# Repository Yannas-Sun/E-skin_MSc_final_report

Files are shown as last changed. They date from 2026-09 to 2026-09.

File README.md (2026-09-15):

# E-SKIN MSc final report companion

This repository is the evidence package for a modular electronic-skin prototype and its final MSc report. It collects the report-linked experimental records, derived analyses, hardware design evidence and selected figures needed to assess the reported communication, power and calibration results.

## Contents

- [Final report PDF](main_final.pdf)
- [Project background](#project-background)
- [System and data path](#system-and-data-path)
- [Hardware overview](#hardware-overview)
- [Core reported results](#core-reported-results)
- [Repository structure](#repository-structure)
- [Software simulation](#software-simulation)
- [Evidence and reproduction](#evidence-and-reproduction)
- [Scope limits](#scope-limits)

## Project background

The final report treats the E-SKIN prototype as a system-level scalability problem. It starts from an existing modular FSR platform and evaluates whether adding sensing modules remains practical across the complete chain: local acquisition, shared communication, host transport, power delivery and calibration.

### Research gap

Existing e-skin work often foregrounds sensing materials, array geometry or local sensor performance. The report identifies a system-level gap: the available modular prototype had not been evaluated as one connected scaling problem across data traffic, regulated power and calibration repeatability. In particular, the report needed evidence for:

- whether complete FSR data can be transported as modules are added, and whether cached change-driven DELTA frames reduce the same-rate traffic;
- whether the parallel 3.3 V supply maintains the specified voltage range as module count increases, without confusing static readings with a verified transient capacity; and
- whether a layer-wide calibration workflow reduces cell-to-cell variation and reconstructs applied whole-layer mass for separately calibrated FSR layers.

The report separates measured behaviour for N = 1–4 modules from conditional model projections beyond the measured range. The repository follows the same boundary.

### Hypotheses to be tested

The report defines the following hypotheses in its Background chapter. They are listed here as the claims the evidence package is intended to test or bound.

- **D-H1 — protocol-model agreement:** within N = 1–4, observed mean FULL packet lengths and DELTA packet lengths follow the byte budgets using the recorded mask activity, complete-frame incidence and module-update coverage. Values beyond four modules remain conditional extrapolations.
- **D-H2 — DELTA traffic reduction:** change-driven DELTA reduces same-rate packet bytes under the tested activity conditions in windows without detected sequence, cache-chain or target-update anomalies.
- **P-H1 — current prediction:** separately measured single-module currents provide a useful descriptive prediction of the tested multi-module combinations under comparable operating conditions; this is not treated as proof of a universal current-versus-count law.
- **P-H2 — voltage range:** recorded module voltages remain within the project-defined 3.3 V ± 5% band for the tested configurations. Transient delivery and fault-free operation require additional monitoring.
- **C-H1 — spatial dispersion:** with matched RAW inputs and common valid cells, per-cell multi-load fitting reduces spatial dispersion relative to two-point LINEAR or GAMMA calibration, assessed separately using CV, variance, IQR and MAD.
- **C-H2 — mass reconstruction:** per-cell calibration estimates known applied whole-layer mass, quantified with signed bias, absolute error, per-cell MAE/RMSE and non-zero-load percentage error. The report specifies no pass/fail accuracy threshold, so this remains a descriptive error assessment.
- **C-H3 — second-layer repeatability:** applying the same workflow independently to a second nominally identical FSR layer retains the FIT PRESS benefit relative to LINEAR and GAMMA under the same validation procedure. This tests independent retraining across layers, not direct transfer of one fitted model.

The reported results below show which parts are supported by the measured records and which remain model-based or unmeasured.

## System and data path

The report's layered acquisition and communication path is reproduced here for orientation.

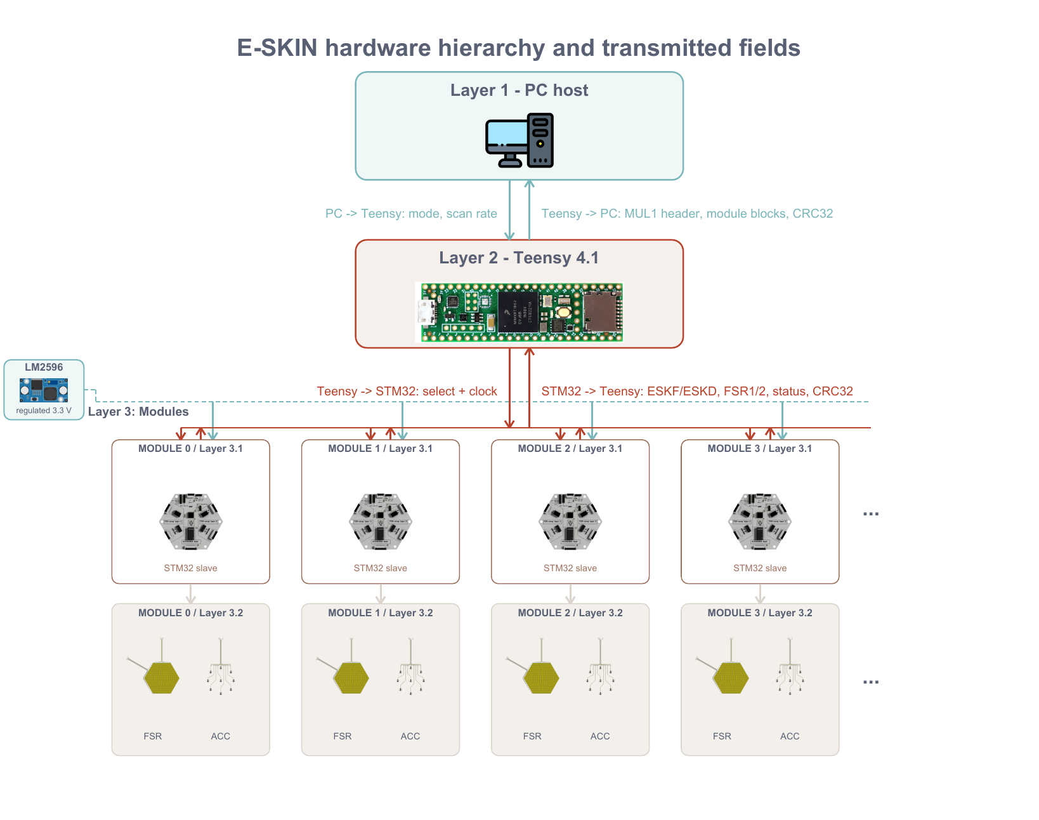
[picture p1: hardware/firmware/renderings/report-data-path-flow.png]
Layered acquisition and communication path from the report


[Open the original report flow figure](<Imperial College Individual Project Template_LaTeX/figures/data/data_path_flow.pdf>).

## Hardware overview

The sensing layer places pressure-sensitive resistive foam between opposing copper electrode layers. Orthogonal row and column electrodes form a 16 × 16 matrix; pressure changes the local resistance at each row-column intersection. The STM32 scans the matrix, buffers a complete ESKF or change-driven ESKD frame, and sends it to the Teensy bridge. The mainboard uses an external regulated 3.3 V branch for the module electronics.

The ACC board shown below is an existing prototype interface. It is retained as hardware evidence but is outside the reported FSR performance evaluation.

<table width="100%">
<tr>
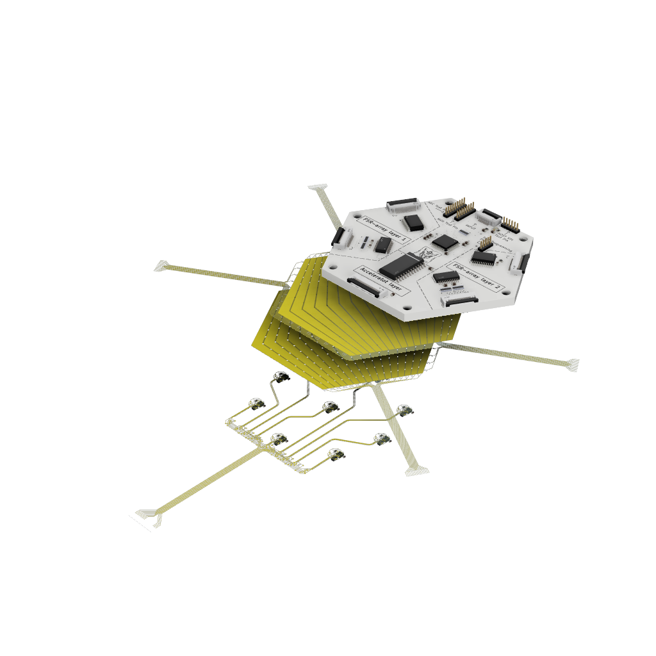
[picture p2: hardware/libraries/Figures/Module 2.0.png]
Module rendering
<td width="50%" align="center"><br>Module stack</td>
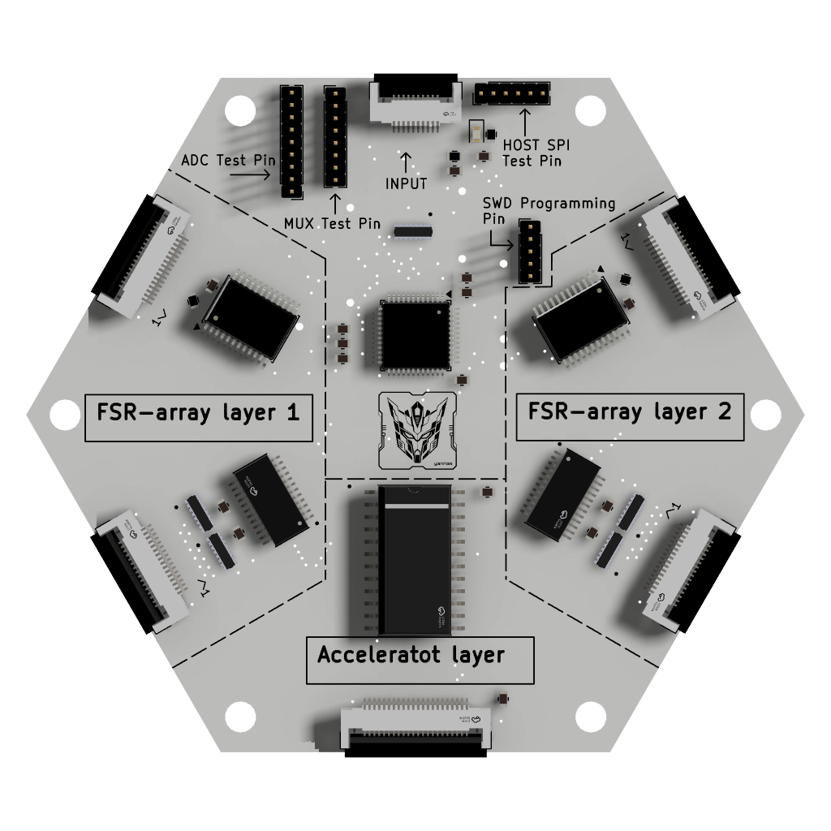
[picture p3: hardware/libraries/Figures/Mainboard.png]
Mainboard rendering
<td width="50%" align="center"><br>Rigid mainboard</td>
</tr>
<tr>
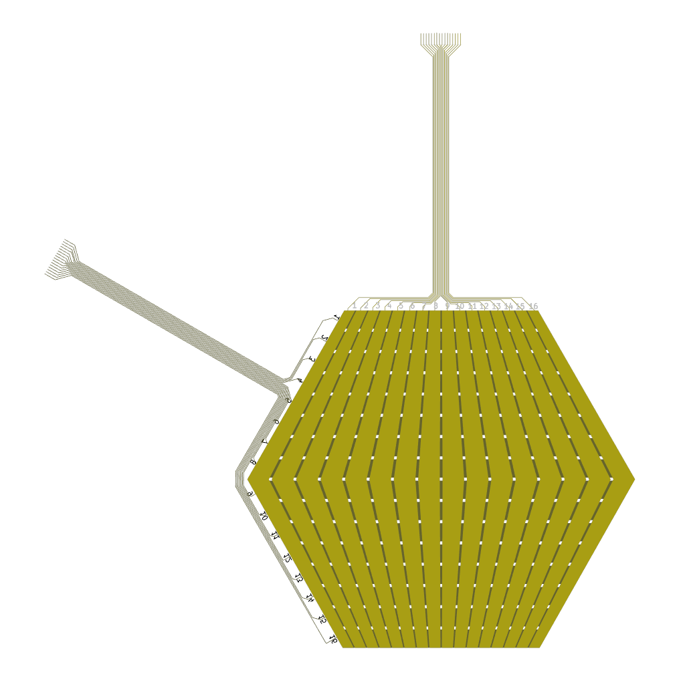
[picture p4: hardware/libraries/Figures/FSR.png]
FSR layer rendering
<td width="50%" align="center"><br>Flexible FSR layer</td>
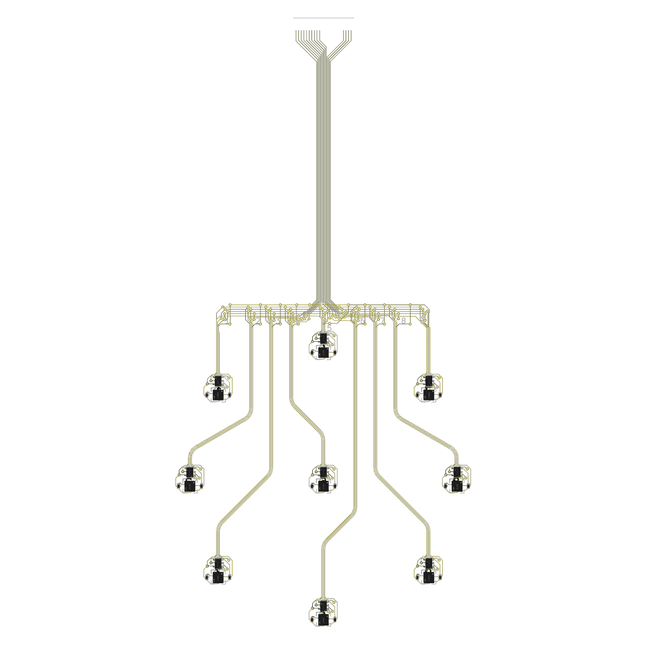
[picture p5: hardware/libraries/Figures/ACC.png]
ACC prototype rendering
<td width="50%" align="center"><br>ACC prototype</td>
</tr>
</table>

- [Hardware overview](hardware/README.md)
- [Prototype design records](hardware/prototype/README.md)
- [Shared KiCad libraries and renderings](hardware/libraries/README.md)
- [Active and archived firmware](hardware/firmware/README.md)

## Core reported results

### Communication

- The four-module FULL stream measured 6.747828 ± 0.001148 Mbit/s at the configured 200 Hz scan rate.
- Measured FULL packet lengths matched the protocol model for N = 1–4. Mean USB rates differed from the nominal 200 Hz predictions by +0.029% to +0.125%.
- Extending the FULL model to N = 100 gives 167.7184 Mbit/s; this value is unvalidated because only four modules were measured.
- DELTA reduced same-rate packet bytes by 86.60%–88.73% in zero-load windows and by 65.10%–80.57% in five audited dynamic batches.
- The fitted zero-load ordinary-mask trend is K0(N) = 7.554189 + 0.582684N. The rolling stress projection uses K = 254.
- At 200 Hz, the modelled crossing counts are conditional planning values:

<table width="100%">
<tr>
<th align="left">Traffic model</th>
<th align="right">USB 480 Mbit/s</th>
<th align="right">HOST SPI 10 Mbit/s</th>
</tr>
<tr>
<td>FULL</td>
<td align="right">286 modules</td>
<td align="right">5 modules</td>
</tr>
<tr>
<td>DELTA, zero-load K0(N)</td>
<td align="right">464 modules</td>
<td align="right">41 modules</td>
</tr>
<tr>
<td>DELTA, rolling K = 254</td>
<td align="right">501 modules</td>
<td align="right">10 modules</td>
</tr>
</table>

Only N = 1–4 is experimentally measured. The crossing counts are extrapolations from the reported packet models and interface rates.

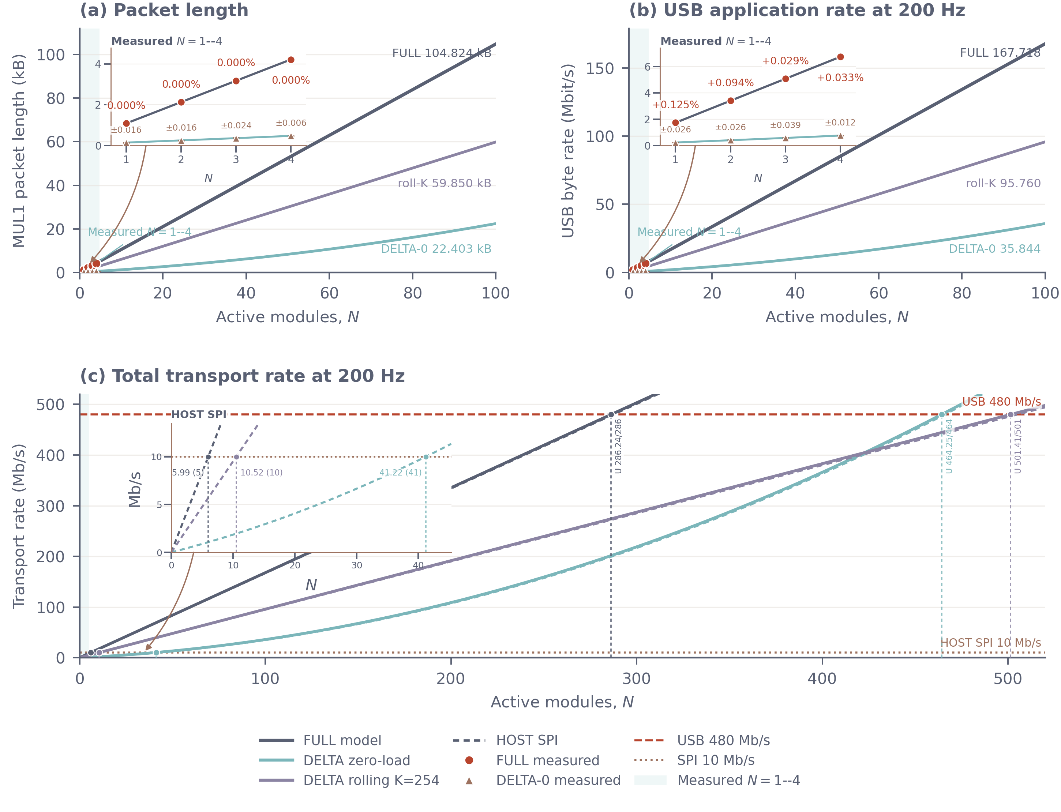
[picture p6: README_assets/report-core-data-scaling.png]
Report figure: transport-model validation and capacity projection


[Report source: transport-model validation and capacity projection](<Imperial College Individual Project Template_LaTeX/figures/data/v2_11/full_model_validation.pdf>) · [Communication data and analyses](<data scalability/README.md>)

### Power

The power experiment records static voltage, branch current and temperature readings for all 15 non-empty combinations of M0–M3 under the configured 200 Hz FULL acquisition. The four-module branch-current readings were 72.513 mA and 78.720 mA in the reported branches, and the lowest accepted module minimum was 3.236 V. These static readings do not establish transient supply capacity.

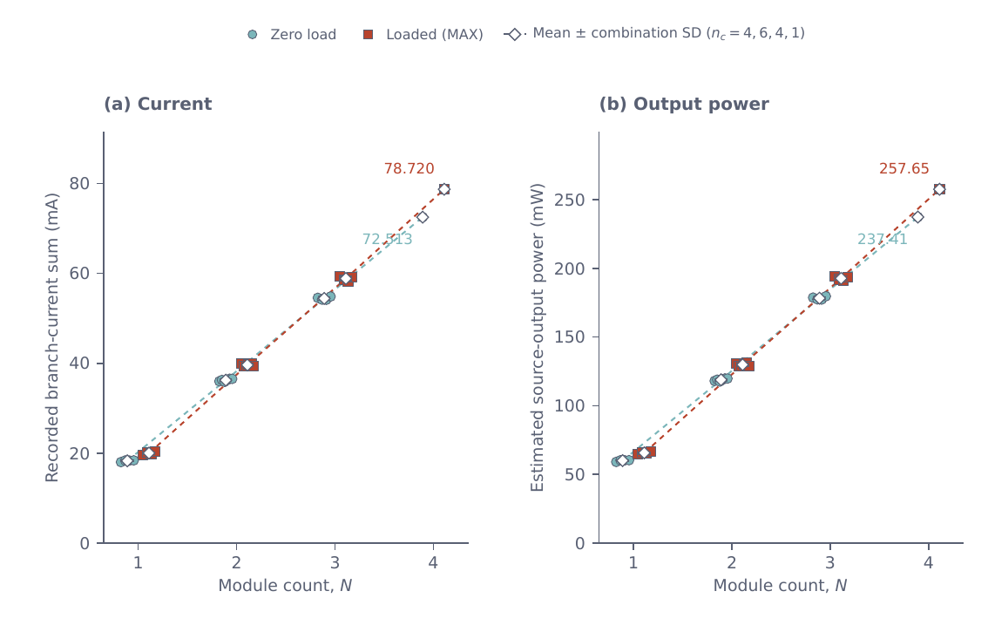
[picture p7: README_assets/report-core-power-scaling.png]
Report figure: continuous-read electrical demand


[Report source: continuous-read electrical demand](<Imperial College Individual Project Template_LaTeX/figures/power/v2_9/current_power_scaling.pdf>) · [Power data and analyses](<power scalability/README.md>)

### Calibration

FSR1 and FSR2 were calibrated in separate 22-point sweeps from 0 to 5000 g. In the FSR2 evaluation, FIT PRESS produced a 10.22% mean layer-estimate APE and 171.69 g mean per-cell MAE across 21 validation captures, with a 40.12 g zero-load estimate. The report treats these metrics as comparator- and metric-dependent.

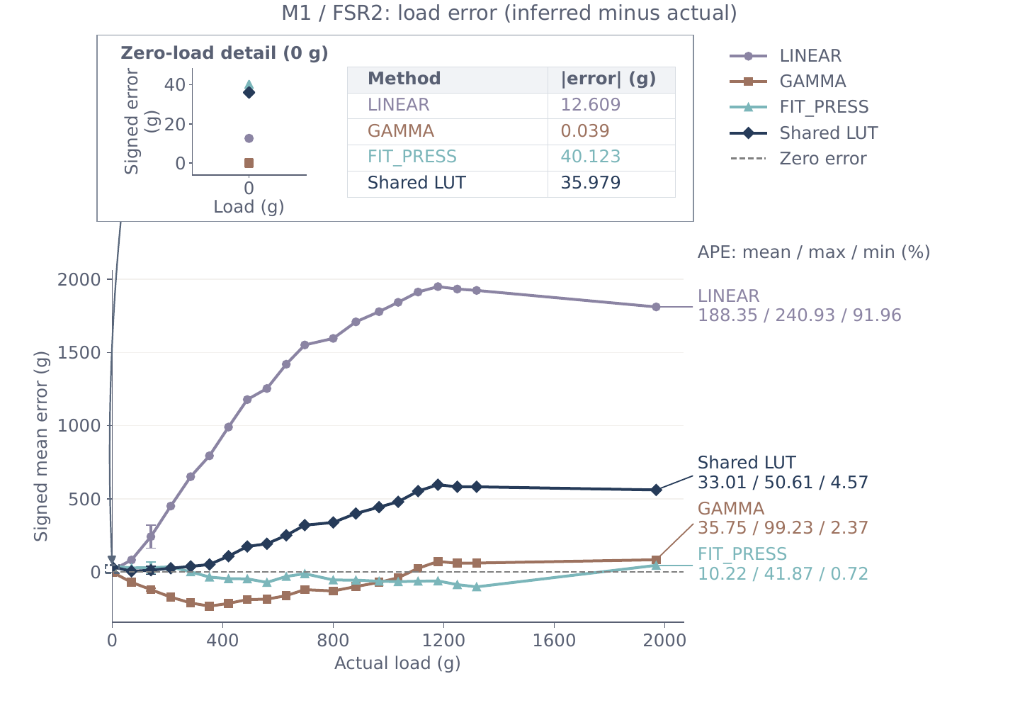
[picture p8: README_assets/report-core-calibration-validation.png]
Report figure: FSR2 load reconstruction error


[Report source: FSR2 load reconstruction error](<Imperial College Individual Project Template_LaTeX/figures/calibration/v2_7/fsr2_load_error_vs_load.pdf>) · [Calibration data and analyses](<Calibration scalability/README.md>)

## Repository structure

| Path | Purpose |
|---|---|
| [Calibration scalability](<Calibration scalability>) | FSR1/FSR2 training sweeps, validation captures, calibration models, figures and audits. |
| [data scalability](<data scalability>) | Canonical FULL/DELTA recordings, selected windows, communication models and figures. |
| [power scalability](<power scalability>) | Canonical electrical records, matched photographs, power analyses and figures. |
| [hardware](hardware/README.md) | Prototype design files, manufacturing exports, shared libraries, renderings and firmware. |
| [LaTeX supplementary package](<Imperial College Individual Project Template_LaTeX/figures>) | Report-linked figures and [audit evidence](<Imperial College Individual Project Template_LaTeX/audit>). |
| [README assets](README_assets) | Rendered copies of the core report result figures used by this README; the data-path rendering is stored with firmware. |
| [figure_style.py](figure_style.py) | Shared plotting-style helper retained with the evidence package. |

The complete report source and build outputs are intentionally ignored by Git. The final rendered report is available at [main_final.pdf](main_final.pdf); this repository publishes the supporting records and selected supplementary material rather than a standalone report compiler.

## Evidence and reproduction

Raw records are retained as recorded in the three scalability packages. Derived tables and figures identify their input manifests and analysis directories. Scripts use portable relative paths within the organized packages; machine-specific build products, caches, live captures and temporary review files are ignored.

The audit material records provenance and validation checks for report-linked data. It does not introduce additional experiments or replace the report's stated methods.

## Scope limits

- Communication measurements stop at four modules; larger module counts are conditional projections.
- Power results are static readings and do not establish transient supply capacity.
- Cross-module calibration, calibration transfer between layers and repeatability after reassembly were not measured.
- The ACC prototype is documented as hardware evidence but is outside the reported FSR evaluation.

## Software simulation

The early software simulator is maintained in the separate [e-skin-simulator repository](https://github.com/Yannas-Sun/e-skin-simulator). It explores module geometry, FSR and accelerometer readout, protocol traffic and visualisation before all hardware paths are complete.

The simulator is an initial design and communication tool. It is not evidence for the measured report results and is not a high-fidelity electrical, mechanical or finite-element model. Scan strategies, MCU-in-the-loop behaviour, event-driven sensing, multi-patch communication and physical validation still require further development.

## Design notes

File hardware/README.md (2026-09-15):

# Hardware package

This directory contains the hardware evidence for the final project: prototype design records, manufacturing exports, shared KiCad libraries, renderings and firmware.

## System principle

Each replaceable module contains two flexible FSR electrode layers and a local STM32G474CETx. Orthogonal copper rows and columns surround a pressure-sensitive resistive foam layer, producing a 16 x 16 sensing matrix. The rigid mainboard provides the FSR interfaces, ADC and multiplexing paths, branch power, connectors and programming access.

The Teensy 4.1 acts as the host bridge. It selects modules over the shared 10 MHz HOST SPI link, aggregates ESKF FULL or ESKD DELTA frames into MUL1 v2 packets and forwards them to the PC over USB. The ACC interface is retained as an existing prototype record and is outside the reported FSR evaluation.

## Renderings

<table>
<tr>
<td>Module stack<br>Module stack</td>
<td>Rigid mainboard<br>Rigid mainboard</td>
</tr>
<tr>
<td>Flexible FSR layer<br>Flexible FSR layer</td>
<td>ACC prototype<br>ACC prototype</td>
</tr>
</table>

## Navigation

- [Prototype design records](prototype/README.md): mainboard, flexible FSR array and ACC prototype design/manufacturing files.
- [Shared libraries](libraries/README.md): KiCad symbols and footprints, models, datasheets, BOMs and exported figures.
- [Firmware](firmware/README.md): active four-module firmware, protocol notes and archived firmware records.

Each prototype directory separates design files from manufacturing outputs. KiCad projects use paths relative to this hardware package.

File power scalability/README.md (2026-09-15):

# Power scalability

Evidence package for the report's module current, voltage, temperature and power analysis.

## Report links

- `Imperial College Individual Project Template_LaTeX/method/power.tex`
- `Imperial College Individual Project Template_LaTeX/result/power.tex`
- `Imperial College Individual Project Template_LaTeX/discussion/power_outline.tex`
- `Imperial College Individual Project Template_LaTeX/appendix/power.tex`
- Current figures: `Imperial College Individual Project Template_LaTeX/figures/power/`

## Contents

- `DATA/raw/canonical/`: source YAML, photographs, retests and `power_raw.csv`.
- `DATA/raw/intake/`: voltage-intake supplements.
- `DATA/analysis/current/`: current reviews, tables and figure exports.
- `DATA/analysis/retest_reviews/`: pointwise retest provenance.
- `DATA/analysis/provenance/`: path and hash manifests.
- `DATA/reference/`: frozen earlier inputs retained by current manifests.
- `DATA/archive/`: superseded previews.
- `script/Main/`: analysis utilities and pipeline entry points.

The report uses all 15 non-empty module combinations under configured 200 Hz `FULL` acquisition. Electrical readings are static descriptive measurements; they do not establish transient supply capacity or thermal equilibrium.

The neighbouring LaTeX source is excluded by its `.gitignore`.

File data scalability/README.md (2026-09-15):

# Data scalability

Evidence package for the report's FULL and DELTA communication experiments.

## Report links

- `Imperial College Individual Project Template_LaTeX/method/data_scalability.tex`
- `Imperial College Individual Project Template_LaTeX/result/data_scalability.tex`
- `Imperial College Individual Project Template_LaTeX/discussion/data_scalability.tex`
- `Imperial College Individual Project Template_LaTeX/appendix/data_scalability.tex`
- Current figures: `Imperial College Individual Project Template_LaTeX/figures/data/`

## Current selection

The indexed campaign contains 114 recordings: 48 FULL zero-load, 45 DELTA zero-load and 21 DELTA dynamic records. The report selection contains 45 FULL windows, 45 DELTA zero-load windows and 15 DELTA dynamic windows.

## Contents

- `data/`: canonical recordings and per-condition records.
- `analysis/`: current selection, audits and derived statistics.
- `history/`: superseded or diagnostic campaigns retained for provenance.
- `figures/`: figure exports; only report-linked files are release material.
- `script/`: indexing and audit utilities.

Key indexes are `data/run_index.csv`, `data/primary_matrix.csv`, `data/dynamic_analysis_selected.csv` and `data/analysis_selected.csv`. Values and source files are unchanged by this organisation.

The neighbouring LaTeX source is excluded by its `.gitignore`.

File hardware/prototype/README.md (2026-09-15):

# Prototype design records

This directory contains the current KiCad design and manufacturing records for the evaluated mainboard and flexible FSR layers, plus the ACC prototype interface.

## Hardware principles

- The [mainboard](mainboard/README.md) is a four-layer rigid FR4 controller board with local STM32G474CETx acquisition, FSR readout, branch power distribution, connectors and programming access.
- The [flexible FSR array](fsr_array/README.md) is a passive two-layer electrode carrier. Orthogonal row and column electrodes surround a pressure-sensitive resistive foam layer to form a 16 x 16 matrix.
- The [ACC prototype](acc_prototype/README.md) is an existing accelerometer interface retained as hardware evidence; it is outside the reported FSR evaluation.

Each board directory separates design files from manufacturing exports. The renderings below are orientation images; the KiCad projects and Gerbers are the source records.

## Renderings

<table>
<tr>
<td>Module stack<br>Module stack</td>
<td>Rigid mainboard<br>Rigid mainboard</td>
</tr>
<tr>
<td>Flexible FSR layer<br>Flexible FSR layer</td>
<td>ACC prototype<br>ACC prototype</td>
</tr>
</table>

## Contents

- [mainboard/](mainboard/README.md): rigid controller schematic, PCB layout, BOM and manufacturing files.
- [fsr_array/](fsr_array/README.md): flexible FSR schematic, PCB layout and manufacturing files.
- [acc_prototype/](acc_prototype/README.md): ACC prototype schematic, PCB layout, BOM and manufacturing files.
- renderings/: small reference images used by this README.

Open each KiCad project from its design directory with the shared libraries available under hardware/libraries/.

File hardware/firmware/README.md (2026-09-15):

# Firmware

This directory contains the active STM32 and Teensy firmware used by the final four-module prototype, plus archived firmware records.

## Principle

Each STM32G474CETx scans its local 16 x 16 FSR matrix and sends a complete ESKF frame or a change-driven ESKD frame over the shared 10 MHz HOST SPI link. The Teensy 4.1 selects modules, aggregates the returned frames into a MUL1 v2 packet and forwards the packet to the PC over USB. The ACC interface is a prototype record and is outside the reported FSR evaluation.

Layered acquisition and communication path from the report

## Contents

- active/: firmware used for the final report.
- active/four-module-variable-spi/: STM32 module firmware, Teensy bridge, commands, protocol notes and tests.
- archive/: superseded firmware and historical records.
- renderings/: the report data-path figure used for orientation.

## Active workflow

From active/four-module-variable-spi/:

1. Build the STM32 and Teensy targets with the supplied command scripts.
2. Flash each STM32 with its probe UID.
3. Upload the matching Teensy bridge image.
4. Start the serial monitor with the actual port name.

Required tools are CMake, Ninja, arm-none-eabi-gcc, arduino-cli, pyocd and Python on PATH. Do not commit generated build output or live measurement captures; the firmware ignore rules exclude them.

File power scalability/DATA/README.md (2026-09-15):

# Power data

Power evidence is separated by provenance and processing state.

| Directory | Role |
|---|---|
| `raw/canonical/` | Immutable source records, photographs, retests and `power_raw.csv`. |
| `raw/intake/` | Dated voltage supplements and intake notes. |
| `analysis/current/` | Current reviews, tables and report figure exports. |
| `analysis/retest_reviews/` | Pointwise retest analysis. |
| `analysis/provenance/` | Relocation and hash manifests. |
| `reference/` | Earlier analyses retained by current provenance. |
| `archive/` | Superseded preview material. |

Current report inputs are under `raw/canonical/` and `analysis/current/`. Do not edit raw records; regenerate derived outputs with scripts in `../script/Main/`.

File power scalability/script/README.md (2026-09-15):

# Power scripts

Scripts use project-relative paths and discover the project root from their own location.

- Main/pipeline/: current voltage, ZERO/MAX and retest compilation.
- Main/figures/: report figure generators and plotting style.
- Main/intake/: dated photograph transcription and supplements.
- Main/tests/: provenance and coverage checks.
- Main/legacy/: historical Power 2.1 reproduction.

Run from the power scalability directory. See Main/README.md for the current entry points.

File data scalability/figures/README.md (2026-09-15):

# Data figures

This directory contains source exports and diagnostics for the data-scalability figures.

Report-linked figures:
- figures/data/v2_11/full_model_validation.pdf
- figures/data/v2_9/data_length_traces.pdf

Other exports are intermediate theory panels, protocol diagrams and diagnostic views. They are retained only when needed to trace a report figure. USB theory uses the 480 Mbit/s reference; HOST SPI uses the 10 MHz reference. Measurements stop at N=4; extensions are conditional projections.

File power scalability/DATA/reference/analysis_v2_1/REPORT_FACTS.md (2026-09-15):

# Power report 2.1: reproducible recorded-data facts

18 continuous USB-read YAML records (9 ZERO, 9 MAX), FULL at 200 Hz; 13 separate legacy blocked-standby CSV records. Standby YAML duplicates are excluded.

Every exact continuous condition has R1 only. N=1: four labelled modules; N=2: two combinations; N=3: two combinations; N=4: one combination. Different combinations are not repeat recordings.

## Continuous USB-read results

| Load | N | Combination | Current sum (mA) | Output power estimate (mW) | Lowest module representative (V) | Lowest module MIN field (V) |
|---|---:|---|---:|---:|---:|---:|
| MAX | 1 | M0 | 19.689 | 64.600 | 3.231 | 3.231 |
| MAX | 1 | M1 | 20.110 | 65.981 | 3.250 | 3.249 |
| MAX | 1 | M2 | 19.897 | 65.282 | 3.247 | 3.247 |
| MAX | 1 | M3 | 20.340 | 66.715 | 3.248 | 3.248 |
| MAX | 2 | M0+M1 | 39.968 | 131.015 | 3.241 | 3.241 |
| MAX | 2 | M2+M3 | 39.379 | 129.084 | 3.245 | 3.244 |
| MAX | 3 | M0+M1+M2 | 59.328 | 194.359 | 3.237 | 3.237 |
| MAX | 3 | M1+M2+M3 | 59.617 | 195.305 | 3.232 | 3.232 |
| MAX | 4 | M0+M1+M2+M3 | 78.720 | 257.651 | 3.237 | 3.236 |
| ZERO | 1 | M0 | 18.160 | 59.565 | 3.235 | 3.235 |
| ZERO | 1 | M1 | 18.380 | 60.305 | 3.255 | 3.255 |
| ZERO | 1 | M2 | 18.360 | 60.239 | 3.249 | 3.249 |
| ZERO | 1 | M3 | 18.400 | 60.352 | 3.251 | 3.250 |
| ZERO | 2 | M0+M1 | 36.016 | 118.168 | 3.234 | 3.234 |
| ZERO | 2 | M2+M3 | 36.534 | 119.795 | 3.248 | 3.248 |
| ZERO | 3 | M0+M1+M2 | 54.481 | 178.480 | 3.224 | 3.224 |
| ZERO | 3 | M1+M2+M3 | 54.851 | 179.692 | 3.245 | 3.245 |
| ZERO | 4 | M0+M1+M2+M3 | 72.513 | 237.408 | 3.240 | 3.240 |

## Independent N=1 prediction

Residual = 100 × (observed branch sum − sum of separately recorded N=1 currents) / predicted sum. MAX results require equivalent loading; module labels are assumed consistent across runs.

| Load | Combination | Predicted (mA) | Observed (mA) | Residual (%) |
|---|---|---:|---:|---:|
| MAX | M0+M1 | 39.799 | 39.968 | 0.4246 |
| ZERO | M0+M1 | 36.540 | 36.016 | -1.4340 |
| MAX | M2+M3 | 40.237 | 39.379 | -2.1324 |
| ZERO | M2+M3 | 36.760 | 36.534 | -0.6148 |
| MAX | M0+M1+M2 | 59.696 | 59.328 | -0.6165 |
| ZERO | M0+M1+M2 | 54.900 | 54.481 | -0.7632 |
| MAX | M1+M2+M3 | 60.347 | 59.617 | -1.2097 |
| ZERO | M1+M2+M3 | 55.140 | 54.851 | -0.5241 |
| MAX | M0+M1+M2+M3 | 80.036 | 78.720 | -1.6443 |
| ZERO | M0+M1+M2+M3 | 73.300 | 72.513 | -1.0737 |

## Matched load comparisons

| Combination | ZERO (mA) | MAX (mA) | Increase (mA) | Increase (%) |
|---|---:|---:|---:|---:|
| M0 | 18.160 | 19.689 | 1.529 | 8.4196 |
| M1 | 18.380 | 20.110 | 1.730 | 9.4124 |
| M2 | 18.360 | 19.897 | 1.537 | 8.3715 |
| M3 | 18.400 | 20.340 | 1.940 | 10.5435 |
| M0+M1 | 36.016 | 39.968 | 3.952 | 10.9729 |
| M2+M3 | 36.534 | 39.379 | 2.845 | 7.7873 |
| M0+M1+M2 | 54.481 | 59.328 | 4.847 | 8.8967 |
| M1+M2+M3 | 54.851 | 59.617 | 4.766 | 8.6890 |
| M0+M1+M2+M3 | 72.513 | 78.720 | 6.207 | 8.5598 |

## Limits on interpretation

- Every exact continuous-state/mode/frequency/load/module-combination condition has one recording (R1); repeat SD is unavailable. Different modules/combinations are not repeats.
- Fields named avg are treated as recorded representative instrument readings, not verified time averages. DMM MIN/MAX are not repeat SD or verified high-speed transient extrema.
- Currents were measured sequentially by branch; their sum is a module-supply demand estimate, not a simultaneously measured total-current waveform or peak.
- Teensy USB power is excluded. V_source times the branch-current sum estimates module-supply output power, not converter input power, efficiency or whole-system power.
- MAX records state 2000 g but omit area and application: per-module versus whole-system mass, position and layer are unresolved. Loaded prediction comparisons are conditional on equivalent module loading.
- Continuous YAML dates, start times and operator are absent; nominal 30 s warm-up and 10 s measurement fields are prefilled and not independently confirmed.
- Fault counters are template-default zero without confirmed observation; they do not establish fault-free operation.
- M0..M3 identify modules as written in experiment records; consistent physical identity across combinations has not been independently verified by hardware UID.
- Temperature readings do not establish thermal equilibrium. Startup, fast transients, full supply-board capacity, maximum module count and 20% headroom are unverified.
- Blocked and continuous results come from separate records, not a randomized paired intervention; state differences are descriptive, not an isolated causal estimate.

5 continuous current representative readings fall outside their recorded MIN/MAX range by at most 0.005 mA. Original readings are retained.

- PS01_N2_F200_ZERO_M0-M1_USB_RX_R1 / M1: Representative=18.055 mA; MIN=18.06; MAX=18.31; outside by 0.005000 mA. Check instrument display/rounding; do not replace values.
- PS01_N3_F200_ZERO_M0-M1-M2_USB_RX_R1 / M0: Representative=17.968 mA; MIN=17.97; MAX=17.99; outside by 0.002000 mA. Check instrument display/rounding; do not replace values.
- PS01_N3_F200_ZERO_M0-M1-M2_USB_RX_R1 / M2: Representative=18.383 mA; MIN=18.35; MAX=18.38; outside by 0.003000 mA. Check instrument display/rounding; do not replace values.
- PS01_N3_F200_ZERO_M1-M2-M3_USB_RX_R1 / M3: Representative=18.383 mA; MIN=18.35; MAX=18.38; outside by 0.003000 mA. Check instrument display/rounding; do not replace values.
- PS01_N4_F200_ZERO_M0-M1-M2-M3_USB_RX_R1 / M1: Representative=18.302 mA; MIN=18.27; MAX=18.3; outside by 0.002000 mA. Check instrument display/rounding; do not replace values.

Lowest continuous module MIN field: 3.224 V, PS01_N3_F200_ZERO_M0-M1-M2_USB_RX_R1, M0; margin above 3.135 V: 89.0 mV. This is a recorded DMM value, not a high-speed transient guarantee.

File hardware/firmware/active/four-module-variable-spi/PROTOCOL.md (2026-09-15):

# Host SPI 变长传输与 USB 契约

## 1. 连接和事务

- Teensy 4.1 为 SPI master；每个 STM32 为 SPI3 slave。
- 10 MHz，mode 0，8-bit，MSB first。多字节字段使用 little-endian。
- 模块 0..3 的 Teensy CS：10、14、15、16；IRQ：2、3、4、5。
- STM32 将一帧编码到最大容量 1044 B 的缓冲区，保存其实际长度 L；按 L 启动
  一次 Tx/Rx DMA，再拉高 IRQ。两个缓冲区各自保存长度，重编码时同步更新长度。
- Teensy 等待 IRQ，拉低该模块 CS，先读 16 B ESK 头，同时在 MOSI 发出 16 B DSCM
  命令。验证头后，保持 CS 为低，继续读 L−16 B。STM32 DMA 在两次调用之间不重启。
- 完整帧总时钟数为 8L；16 B 帧头本来就在 L 中，不是额外开销。剩余 MOSI 字节为零。
- Teensy 读完后拉高 CS，验证掩码数量和 CRC，并按原规则放入 USB 队列。
  STM32 在 DMA 完成后处理收到的命令。模式改变或请求完整同步时重编码下一缓冲区。

```text
IRQ   ____/-----------------------------------\____
CS    ______\________________________________/_____
SCK          [16 B header]  [L - 16 B remainder]
MISO         [ESK header ]  [masks/values/CRC  ]
MOSI         [DSCM command] [zero filler       ]
```

示意图只表示事务关系；IRQ 下降由 DMA 完成回调触发，不要求和 CS 上升同一时刻。
STM32 可并行采集下一帧，但不会覆盖正在传输的缓冲区。

## 2. ESK v4 帧

两种帧共用 16 B 头：

| 偏移 | 长度/B | 字段 |
|---:|---:|---|
| 0 | 4 | ASCII `ESKF` 或 `ESKD` |
| 4 | 1 | version = 4 |
| 5 | 1 | flags：0x10 表示 CRC；0x20 表示 DELTA 模式；低四位为采集状态 |
| 6 | 2 | 帧总长度 L，包含 CRC |
| 8 | 4 | sequence |
| 12 | 4 | base_sequence；完整帧为 0xffffffff |

flags 的高两位保留为零。结尾 CRC32 IEEE 为 4 B little-endian，覆盖从 magic
开始到 CRC 前的所有字节。

**ESKF：1044 B。** 头后依次为 FSR1 的 256 个 uint16 和 FSR2 的 256 个 uint16，
均按编码器的行优先顺序输出，然后是 CRC。FULL 模式和 DELTA 的完整同步共用此帧；
后者带 0x20 flag。

**ESKD：84+2K B。** 头后是 FSR1 的 32 B 掩码、FSR2 的 32 B 掩码、K 个 uint16
当前值及 CRC。每个掩码的 bit i 对应 `row*16+column=i`，字节内最低位优先。
当前值先按 FSR1 的置位索引升序输出，再输出 FSR2。K 是两个掩码置位数之和。
无变化也发送 84 B 全零掩码帧。最大 DELTA K=480，超过则使用 ESKF。

变化判断仍为 `abs(current - previous) > delta_threshold`，默认阈值为 8。
为保持原始 USB 数据一致，本次不更改上一帧缓存更新方式、数值量化、采集映射或
重建语义。阈值内的微小变化仍受现有 DELTA 近似行为影响。

完整同步条件仍为缓存无效、距上次完整同步至少 1000 ms、显式重同步、或 K 超限。
Teensy 保留序号跳变、队列溢出和模块重连后的 DELTA 恢复机制。

## 3. DSCM v2 下行命令

命令与帧头同时交换，不另占 SPI 事务：

| 偏移 | 长度/B | 字段 |
|---:|---:|---|
| 0 | 4 | ASCII `DSCM` |
| 4 | 1 | version = 2 |
| 5 | 1 | mode：0 FULL；1 DELTA |
| 6 | 2 | delta_threshold |
| 8 | 2 | reserved = 0 |
| 10 | 2 | scan_rate_hz，0..1000 |
| 12 | 1 | bit 0：请求 DELTA 完整同步；其余位保留 |
| 13 | 3 | reserved = 0 |

PC 文本命令为 `MODE FULL`、`MODE DELTA`、`RESYNC DELTA`、`SCAN_HZ n`，以换行结束。
命令作用于后续采集/编码；正在发送的帧保持不变。

## 4. 异常长度和中途终止

Teensy 在仅收到头时检查 marker、版本、flags、范围和偶数长度；ESKF 必须为
1044 B，ESKD 必须在 84..1044 B。头非法则在 16 B 后释放 CS，不继续按不可信
长度读取，不将其当作有效数据。头合法后才读剩余数据，再核验掩码置位数量及 CRC。

若长度损坏成一个较小的合法值，STM32 会看到未完成 DMA 的 NSS 提前释放。
若损坏成更大的合法值，主机仍最多读取 1044 B，内层 CRC/掩码校验用于拒绝坏帧。
该协议不为帧头添加新 CRC，以保持原 ESK 字节格式。

STM32 在等待传输时检测 `NSS=高` 且 `0 < RX剩余数量 < 本帧长度`，作为部分事务
被主机终止的证据，降低 IRQ、取消 DMA，并走 SPI 重置恢复路径。此检查在并行的
下一帧采集结束后运行；极低扫描率下仍可能先等待现有扫描周期。DMA 尚未收到
任何字节时不会因空闲 NSS 高而误取消；两段读取之间 CS 低时也不会误取消。
等待传输阶段仍保留 1500 ms 超时保护。

## 5. USB MUL1 v2 保持不变

外层结构为 20 B 公共头、四个模块槽、4 B CRC。每个槽含：

| 元数据字段 | 长度/B | 用途 |
|---|---:|---|
| module_id | 1 | 表示来自哪个模块，0..3 |
| status | 1 | 更新/错误状态 |
| length | 2 | 此槽后面实际携带的字节数 |

其后仅复制 length 字节的 ESK 内帧。未更新的槽保留 4 B 元数据，通常长度为零；
诊断错误可携带原有的 16 B 帧头前缀。公共头、槽顺序、状态编码、外层序号、时间戳、
CRC 算法、USB 队列深度 4 及部分 USB 写入的处理方式均沿用原实现。

因此精确字节模型为：

```text
L_USB = 20 + 4*4 + sum(slot_length[m], m=0..3) + 4
      = 40 + sum(slot_length[m], m=0..3)
```

40 B 来源于固定四槽封装；不能随着实际在线模块数量而缩减。
若 N 个在线模块都提交 FULL、其余槽无诊断载荷，则 `L_USB=40+1044N`。
若 N 个模块都提交 ESKD，则 `L_USB=40+84N+2*sum(K_m)`。
完整同步帧和混合帧必须按实际槽长度相加。

令 q 为某模块实际输出中完整同步帧的比例，K_mean_D 为仅 ESKD 帧的平均 K：

```text
L_SPI_mean = q*1044 + (1-q)*(84 + 2*K_mean_D)
wire_time = 8*L_SPI / 10,000,000 seconds
```

上述时间仅计算 SCK 时钟，不含 IRQ 等待、CS 建立/保持、读取头后软件判断和 DMA
准备时间。K=27 的 ESKD 从原 1044 B 降至 138 B，纯时钟时间从 835.2 us 降至
110.4 us；相同有效帧在 USB 上的长度完全相同。

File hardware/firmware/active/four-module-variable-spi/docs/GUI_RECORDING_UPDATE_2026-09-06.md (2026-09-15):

# GUI recording update — 2026-09-06

This document records the PC-side recording changes. STM32/Teensy firmware and USB frame formats are unchanged.

## Paths and scheduling

- Default output: `docs/Final/data scalability/data/<run_id>/`.
- Default schedule: `docs/Final/new_firmware_experiment_plan/halfday_schedule.csv`.
- `Use row` loads the planned modules, mode, condition, block and duration, then sends `MODE` and `SCAN_HZ`.
- Settings stores operator metadata only. Repeat is generated as 1/2/3. A short record defaults to 40 s with a 10 s startup segment; long records default to 310 s with a 10 s startup segment.

## Three-record batches

- Manual recording detects recently valid slots and mode before starting.
- `Record x3` locks the batch configuration and records three consecutive windows without resending `MODE` or `SCAN_HZ`.
- Each run has its own directory. The same `batch_id` and block are used with repeats 1/2/3. Dynamic loading remains operator-controlled.
- A missing module remains an anomaly in the planned configuration; the recorder does not silently reduce `N`.

## Parsing and integrity

- Serial buffering, sequence tracking and DELTA cache state persist across recording files.
- `seq gaps` counts forward sequence jumps in complete MUL1 packets. `missing MUL1` estimates missing packets from those jumps; it is not a physical ADC-scan loss count.
- A packet split across the start boundary is completed and parsed, but only bytes received inside the window are written to the new raw file. Cross-boundary fragments are recorded as events and are excluded from window byte, `K` and `q` totals.
- CRC, missing-module, unexpected-module, stale-update and mode mismatches can produce `CHECK REQUIRED`. The recorder does not retry or overwrite a run because of a check result.
- Byte ownership follows read time; packet ownership follows completion time. PC-to-packet time is not ADC acquisition time.
- Local build hashes identify local files. The matching-flash checkbox is an operator statement, not device flash read-back.
- M0–M3 identify CS/IRQ slots, not unique physical boards. Hardware mapping requires labels or notes. Target scan rate records the GUI/plan setting; measured packet rate is separate.

## Output files

Each run writes raw bytes, `packet_log.csv`, `module_log.csv`, `events.jsonl`, `summary.json`, `experiment_log.md` and initial metadata. `summary.schema_version=2` separates `scopes.full_run` from `scopes.main` and retains per-module `K/q`, update rates, missing updates, CRC results and cache-base chains.

## Runtime controls

- `Event` and `Mark` store PC-time annotations.
- `Resync` sends an explicit synchronisation command.
- `Stop` saves received data and cancels later windows.
- Disconnects and write failures cancel remaining windows.
- Opening Settings pauses heatmap refresh only; serial receive, parsing and recording continue.
- `Next` loads the next schedule row but does not start recording.

The offline test suite covers parser recovery, three-record batches, raw offsets, configuration locking, stop/cancel paths and error attribution. These tests do not establish hardware throughput or electrical timing.

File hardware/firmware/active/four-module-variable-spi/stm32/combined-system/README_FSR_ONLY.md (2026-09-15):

# Four-module FSR firmware with variable-length HOST SPI

This STM32 image is the final-report sensing firmware. All four modules use the same image; the Teensy CS/IRQ wiring determines the module slot. ACC is not sampled or transmitted.

## Frame and link format

| Item | Definition |
|---|---|
| Acquisition | Two 16 x 16 FSR arrays using the shared MUX and two MAX11633 converters |
| HOST SPI | SPI3 slave; one full-duplex DMA transaction for the encoded frame length |
| FULL | `ESKF`, 1044 B: 16 B header, 512 B FSR1, 512 B FSR2, 4 B CRC |
| DELTA | `ESKD`, `84 + 2K` B: 16 B header, two 32 B masks, `K` uint16 values, 4 B CRC |
| DELTA base | FULL on the first frame, resynchronisation, 1000 ms base timeout or `K > 480` |
| USB | Teensy carries frames in MUL1 v2 module blocks |

The Teensy reads the 16-byte header, then clocks `length - 16` additional bytes while CS remains low. A zero-change DELTA frame clocks 84 bytes; unused buffer capacity is not clocked.

## HOST SPI command

The first 16 MOSI bytes are `DSCM` v2. Fields are: version at byte 4; mode at byte 5 (`0` FULL, `1` DELTA); little-endian DELTA threshold at bytes 6–7; target scan rate at bytes 10–11; and DELTA resync at bit 0 of byte 12. Reserved bytes are transmitted as zero.

The Teensy may send `MODE FULL`, `MODE DELTA` and `SCAN_HZ <Hz>`. Commands apply after a completed DMA transaction and preserve the existing acquisition and cache rules.

## Buffering and recovery

Acquisition and encoding use the buffer not being transmitted. DMA completion or error lowers IRQ; a new transfer waits for NSS release and reinitialises HOST SPI. Invalid or truncated transactions are aborted and retried after the existing timeout/back-off path. DELTA resynchronisation requests a new FULL base.

## Build

```powershell
cmake --preset Release
cmake --build --preset Release
```

Output: `build/Release/ESKIN_STM32.elf`. Building does not flash a device. Deploy this image with the matching variable-length Teensy bridge.

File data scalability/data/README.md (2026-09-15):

# Current data snapshot

The current variable-length FULL/DELTA campaign contains 114 recordings and 684 source files. The CSV indexes below define the evidence selection used by the report.

| Group | Recordings | Main-window PASS | CHECK | Selected windows |
|---|---:|---:|---:|---:|
| FULL zero load | 48 | 47 | 1 | 45 |
| DELTA zero load | 45 | 45 | 0 | 45 |
| DELTA dynamic | 21 | 16 | 5 | 15 |
| Total | 114 | 108 | 6 | 105 |

- All 114 records: run_index.csv
- 90-window zero-load matrix: primary_matrix.csv
- 15-window dynamic performance set: dynamic_analysis_selected.csv
- 105-window combined selection: analysis_selected.csv
- Seven-batch dynamic diagnostics: dynamic_diagnostic_statistics.csv
- Source paths and hashes: path_map.csv
- FULL matrix: FULL/README.md
- DELTA overview: DELTA/README.md
- DELTA zero-load matrix: DELTA/Zero_load/README.md
- DELTA dynamic batches: DELTA/Dynamic_load/README.md

Each run retains its raw binary stream, packet and module logs, summary metadata and experiment log. The first 10 seconds remain in the files; the main report window starts at 10 seconds and ends at recording stop. Historical pre-variable-SPI records are kept separately in history/ and are not pooled with this snapshot.

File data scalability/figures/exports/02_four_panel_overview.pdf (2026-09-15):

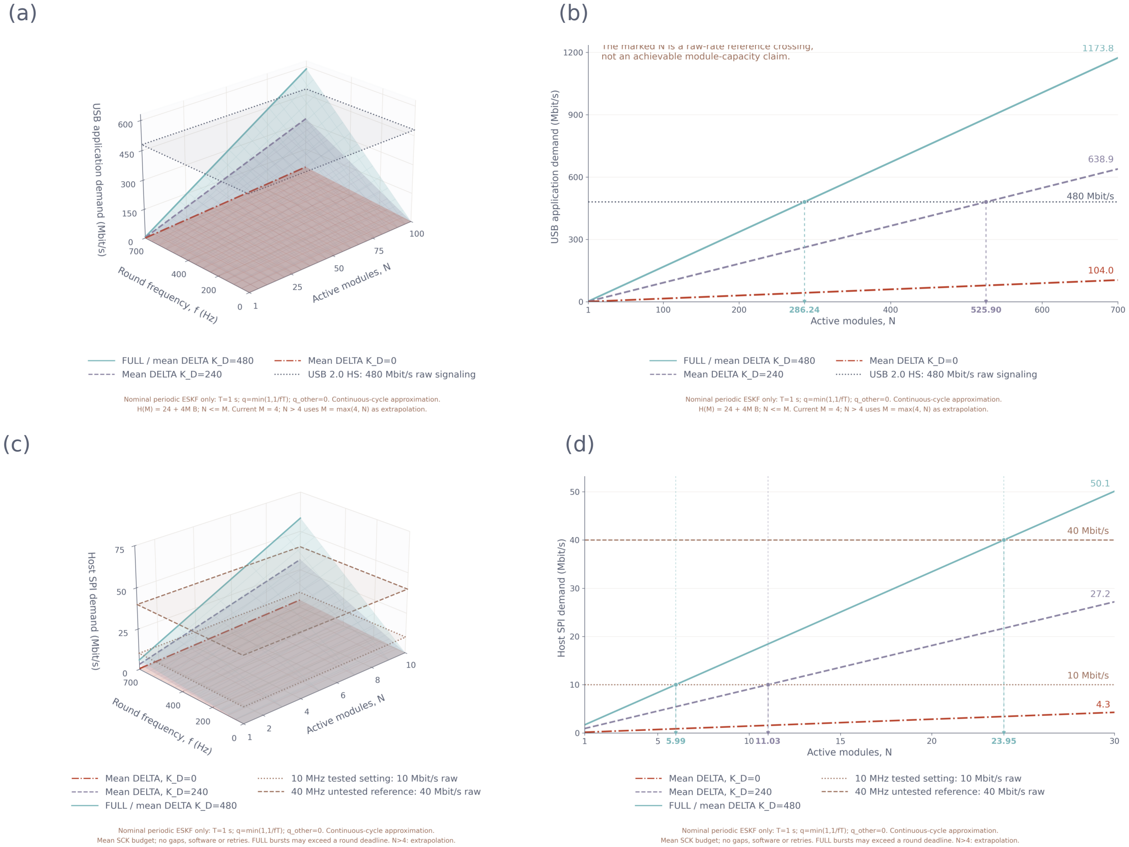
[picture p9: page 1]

(a) (b)
(c) (d)

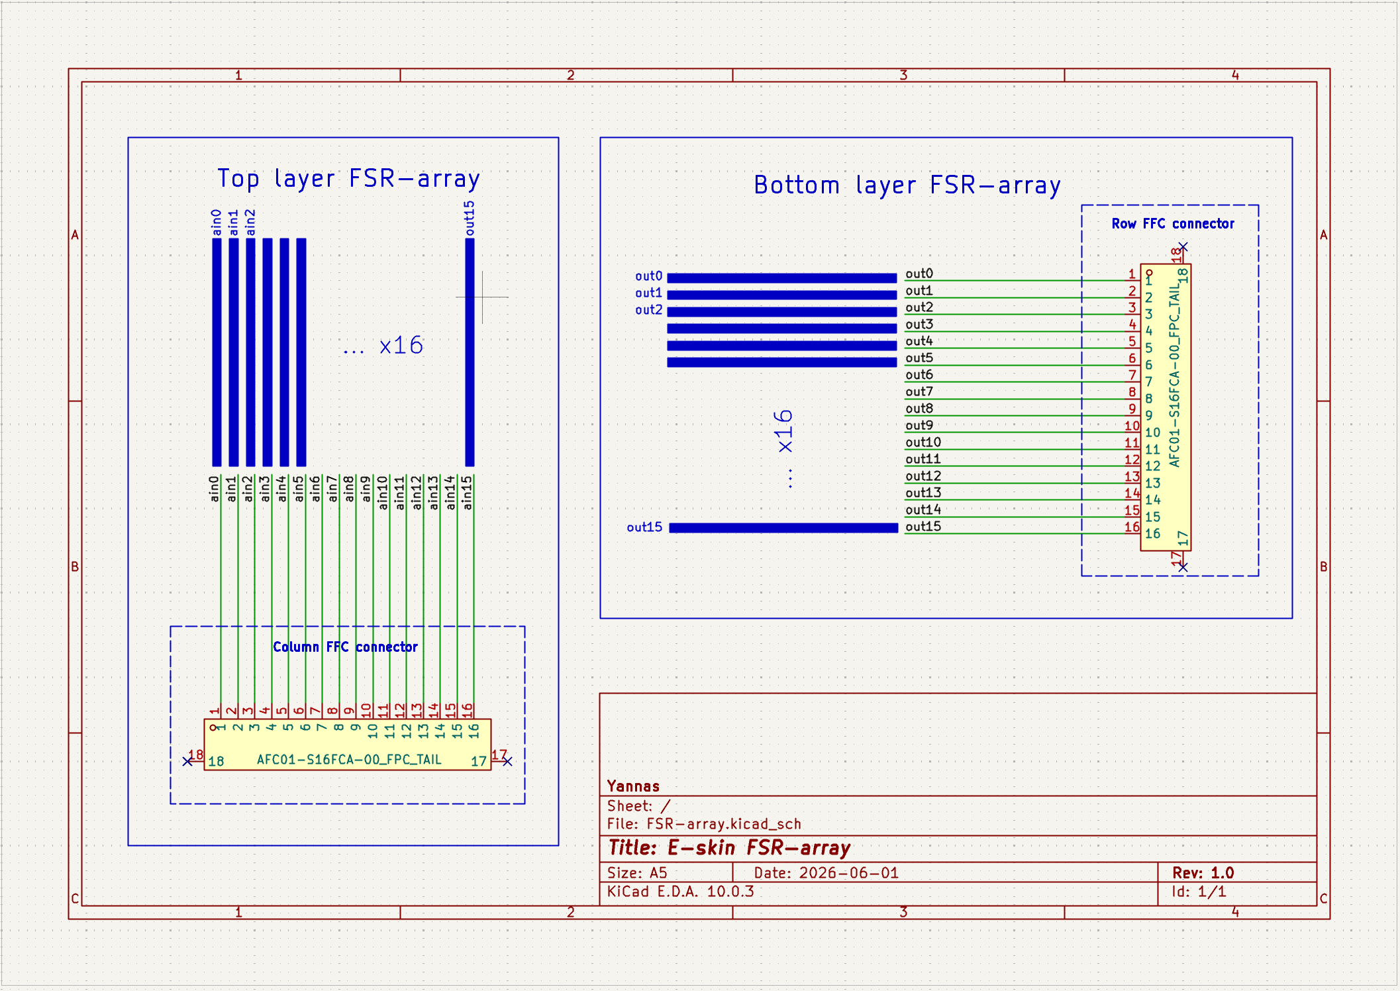
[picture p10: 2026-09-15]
Imperial College Individual Project Template_LaTeX/figures/hardware/FSR_circuit.png

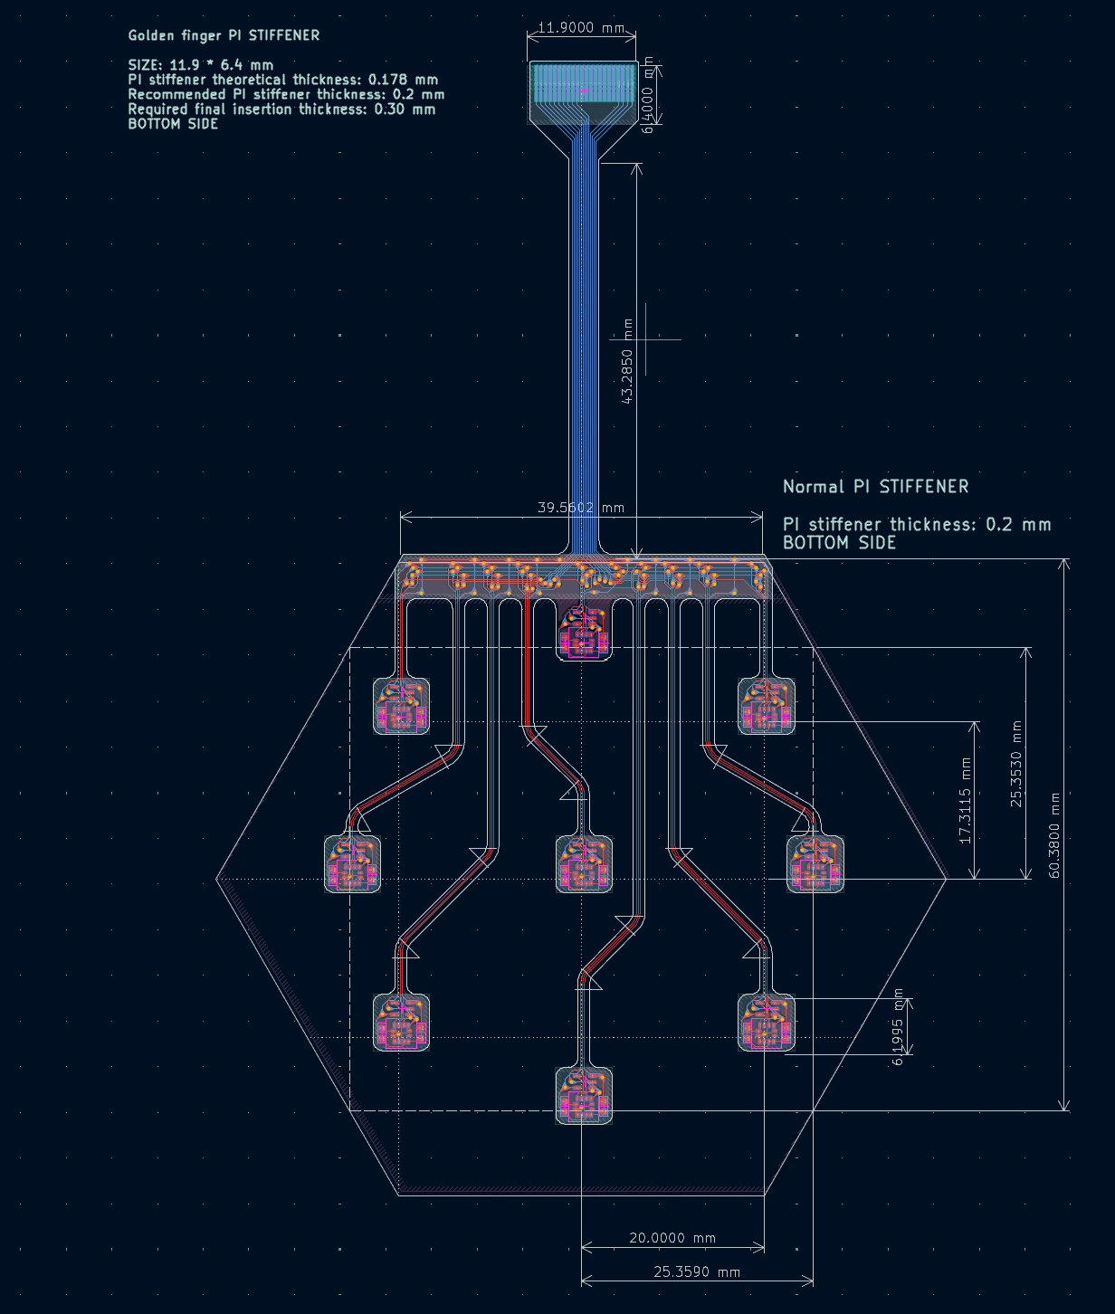
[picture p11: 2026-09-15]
Imperial College Individual Project Template_LaTeX/figures/hardware/ACC_layout.png

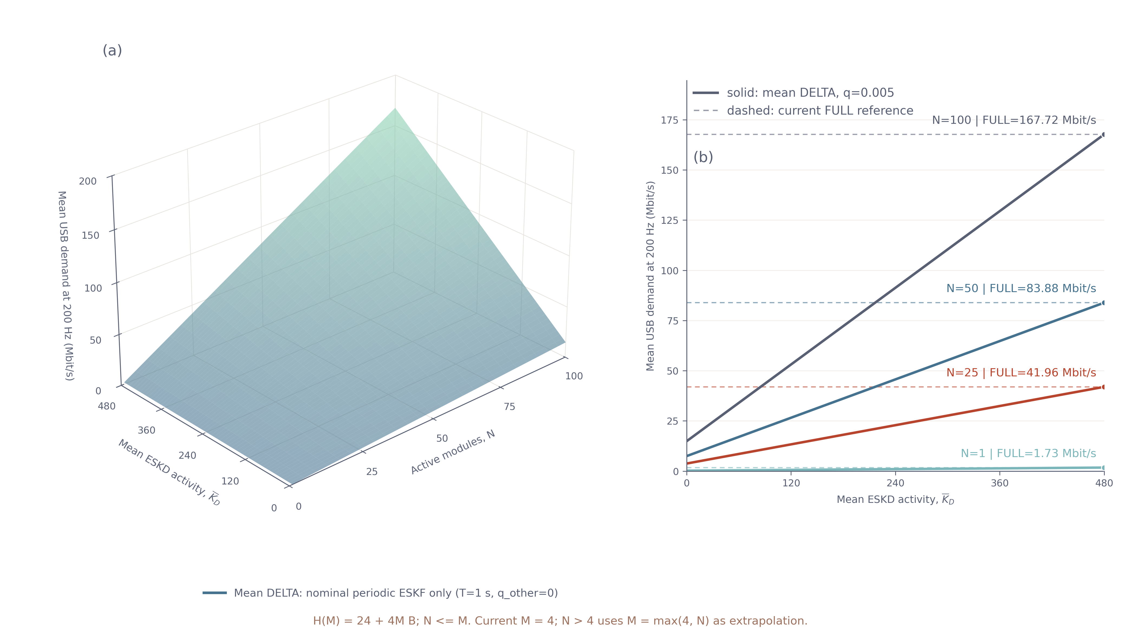
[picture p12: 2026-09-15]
data scalability/figures/exports/02e_delta_usb_k_overview_200hz.png

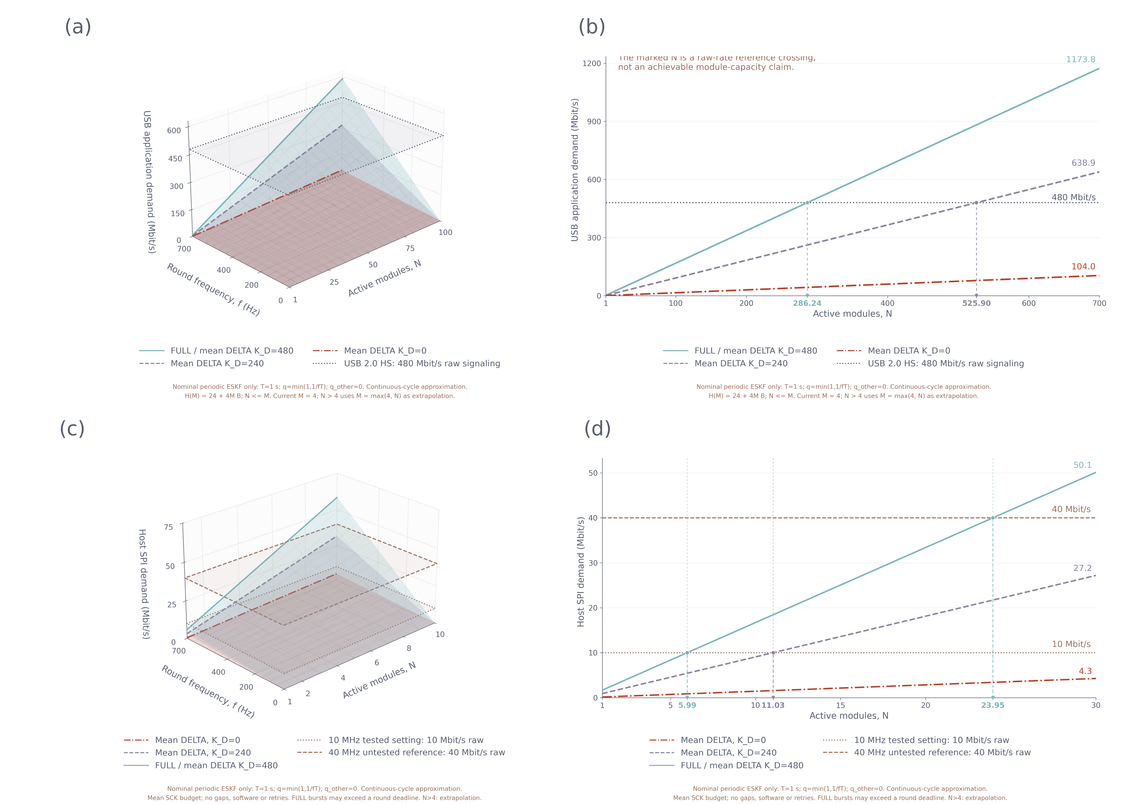
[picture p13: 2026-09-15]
data scalability/figures/exports/02_four_panel_overview.png

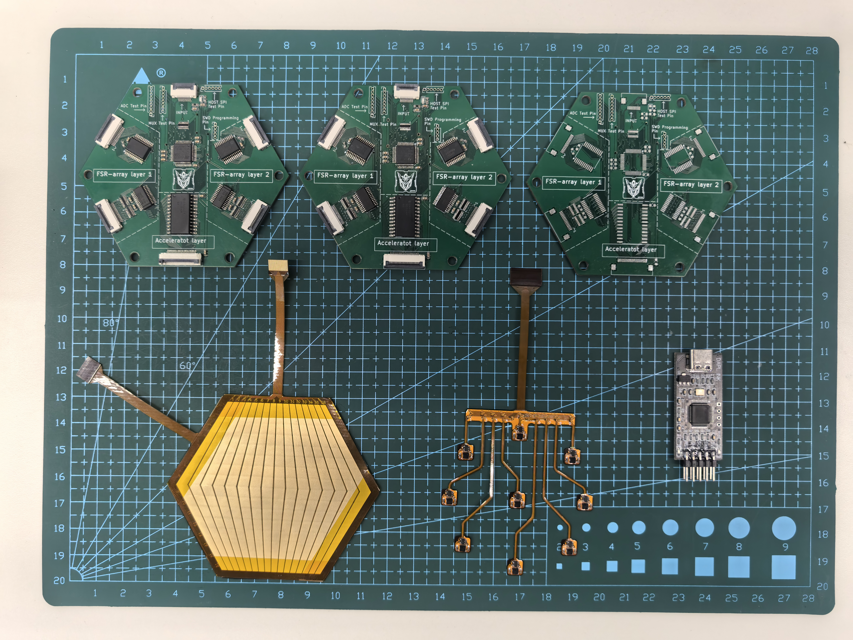
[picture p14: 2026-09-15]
Imperial College Individual Project Template_LaTeX/figures/hardware/Layer.jpg

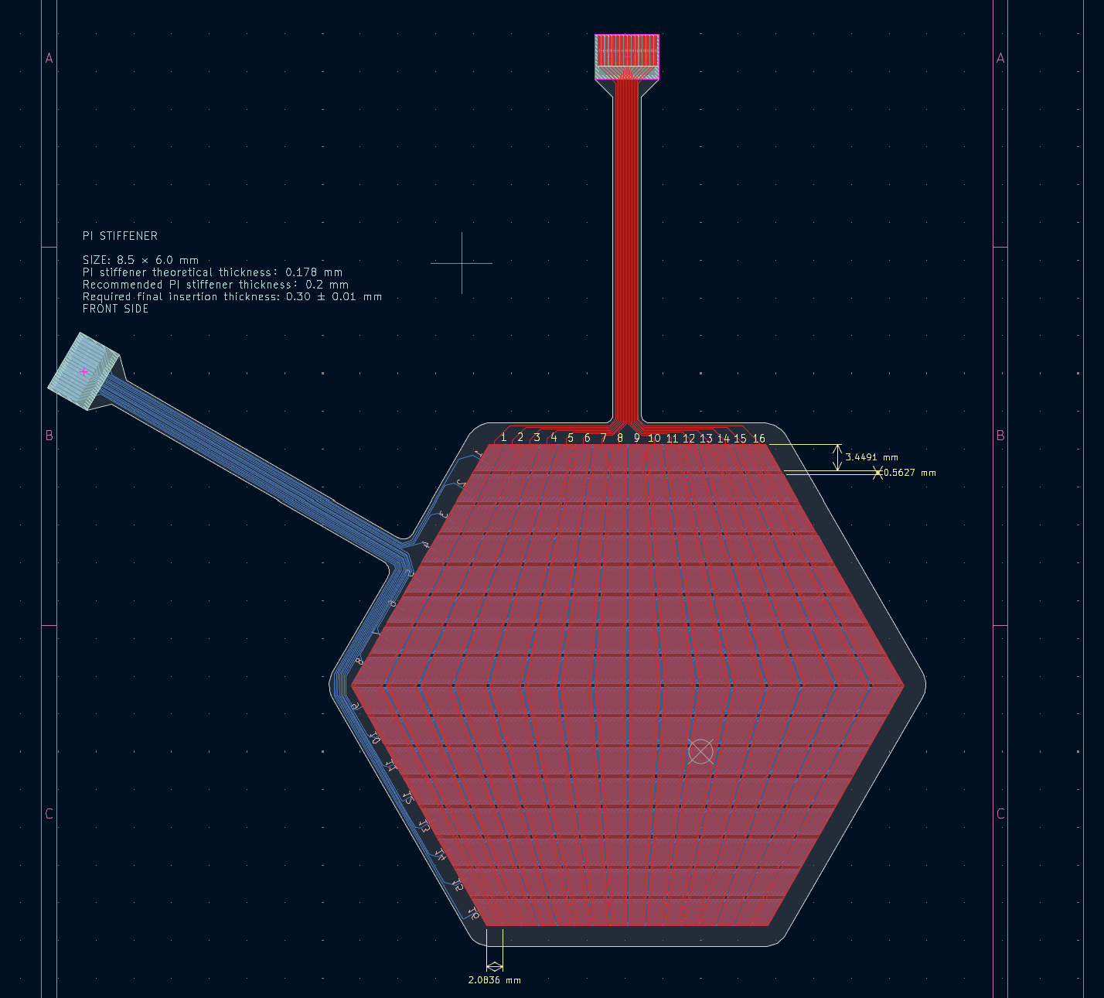
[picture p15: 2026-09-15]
Imperial College Individual Project Template_LaTeX/figures/hardware/FSR_layout.png

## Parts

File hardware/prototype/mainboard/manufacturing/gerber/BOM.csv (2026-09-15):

Reference | Value | Datasheet | Footprint | Qty | Source
J1 | AFC01-S10FCA-00 | ../../../../libraries/datasheet/MAINBOARD/connector (AFC01-S10FCA-00).PDF | 000:AFC01-S10FCA-00 | 1 | LCSC
ROW_FPC2 | FSR Scanning FFC connector 2 | ${KIPRJMOD}/../../../DATA SHEET/connector (AFC01-S16FCA-00).PDF | 000:AFC01-S16FCA-00 | 1 | LCSC
ROW_FPC1 | FSR Scanning FFC connector 1 | ${KIPRJMOD}/../../../DATA SHEET/connector (AFC01-S16FCA-00).PDF | 000:AFC01-S16FCA-00 | 1 | LCSC
COL_FPC2 | FSR ADC FFC connector 2 | ${KIPRJMOD}/../../../DATA SHEET/connector (AFC01-S16FCA-00).PDF | 000:AFC01-S16FCA-00 | 1 | LCSC
COL_FPC1 | FSR ADC FFC connector 1 | ${KIPRJMOD}/../../../DATA SHEET/connector (AFC01-S16FCA-00).PDF | 000:AFC01-S16FCA-00 | 1 | LCSC
ACC_FPC1 | ACC Scanning FFC connector | https://lcsc.com/product-detail/Others_JUSHUO-AFC01-S22FCA-00_C262668.html | 000:AFC01-S22FCA-00 | 1 | LCSC
ACC_DEC1 | CD74HC154M96 | https://www.ti.com/lit/gpn/CD74HCT154 | 000:CD74HC154M96 | 1 | LCSC
COL_ADC1,COL_ADC2 | MAX11633EEGT |  | 000:MAX11633EEGT | 2 | Digikey
RN1,RN2,RN3,RN4,RN5 | 10K |  | 000:EXB2HV103JV | 5 | LCSC
C18 | 10u |  | Capacitor_SMD:C_0603_1608Metric | 1 | LCSC
C1,C2,C5,C6,C7,C8,C9,C10,C11,C12,C13,C14,C15,C16,C17 | 100n |  | Capacitor_SMD:C_0603_1608Metric | 15 | LCSC
D1 | LED |  | LED_SMD:LED_0603_1608Metric | 1 | LCSC
MCU1 | STM32G474CETx | https://www.st.com/resource/en/datasheet/stm32g474ce.pdf | Package_QFP:LQFP-48_7x7mm_P0.5mm | 1 | Digikey
ROW_MUX1,ROW_MUX2 | CD74HC4067SM | http://www.ti.com/lit/ds/symlink/cd74hc4067.pdf | Package_SO:SSOP-24_5.3x8.2mm_P0.65mm | 2 | LCSC
R_MUX1_COM1,R_MUX2_COM1 | 1k |  | Resistor_SMD:R_0603_1608Metric | 2 | LCSC
R_LED1 | 1K |  | Resistor_SMD:R_0603_1608Metric | 1 | LCSC
R1 | 0 |  | Resistor_SMD:R_0603_1608Metric | 1 | LCSC

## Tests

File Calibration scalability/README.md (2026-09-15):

# Calibration scalability

Evidence package for the two independently calibrated 16×16 FSR layers used by the report.

## Report links

- `Imperial College Individual Project Template_LaTeX/method/calibration.tex`
- `Imperial College Individual Project Template_LaTeX/result/calibration.tex`
- `Imperial College Individual Project Template_LaTeX/discussion/calibration.tex`
- `Imperial College Individual Project Template_LaTeX/appendix/calibration.tex`
- Current figures: `Imperial College Individual Project Template_LaTeX/figures/calibration/v2_7/`

## Contents

- `DATA/`: M1 training sweeps, validation captures, fitted models and per-cell outputs.
- `script/`: acquisition, calibration, fitting and plotting scripts.
- `audit/`: checks and machine-readable summaries used by the report.
- `docs/`: calibration notes and provenance.

## Evidence boundary

Each layer uses a separate 22-point, 0–5000 g whole-layer sweep with 200 `FULL` frames per point. The report evaluates FSR2 in the main text and FSR1 in Appendix E. Validation captures are separate from training sweeps.

## Reproduction

Run scripts from this directory with relative paths, for example:

```text
python script/Main/calibrate_fsr.py --port COM9 --module 0 --fsr FSR1
```

The neighbouring LaTeX source is excluded by its `.gitignore`; this package retains evidence and supporting material.

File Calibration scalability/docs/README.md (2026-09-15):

# Documentation

| File | Purpose |
| --- | --- |
| CURRENT_WORKFLOW.md | Concise description of the acquisition, calibration, validation, and analysis procedure reported in the paper. |

Historical protocol notes, synthetic validation logs, changelogs, and superseded redraw inventories were removed so this folder describes only the current paper workflow.

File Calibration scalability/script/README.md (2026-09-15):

# Calibration scripts

The scripts implement the current paper workflow. Run them from the package root with python -B.

- Main/data_scalability_monitor.py — acquisition GUI and validation controls.
- Main/calibration_measurement.py — immutable model snapshots and 200-frame validation capture.
- Main/calibration_shared_endpoints.py — 22-point sweep and shared endpoint workflow.
- Main/Calibration/calibrate_fsr.py — endpoint-model generation from a saved sweep.
- Main/Model/plot_pressure_calibration_monotonic.py — per-cell monotonic fitting and response plots.
- Main/Model/plot_calibration_comparison.py — LINEAR, GAMMA, and FIT PRESS comparison plots; the Shared LUT comparator is generated by Main/Evaluation/shared_lut_baseline.py.
- Main/Evaluation/ — single-capture, cumulative error, dispersion, and preflight analysis.
- Main/Utility/ — portable paths and saturation-range helpers.

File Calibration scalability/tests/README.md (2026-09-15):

# Tests

These software checks cover the current shared-endpoint workflow:

- test_endpoint_calibration.py — shared endpoints, dynamic U, provenance, and incomplete captures.
- test_calibration_comparison.py — source identity, ranges, plateaus, and comparison plotting.
- test_gui_shared_endpoints.py — acquisition interlocks, queue handling, module switching, and endpoint saving.

Additional evaluation tests live beside the production modules in script/Main/Evaluation/ and cover current capture, grouping, error, dispersion, Shared LUT, and refresh behavior. They use synthetic fixtures and do not replace hardware loading validation.

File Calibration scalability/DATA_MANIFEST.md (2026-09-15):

# Current calibration data manifest

The `DATA` tree contains only the M1/FSR1 and M1/FSR2 records used by the current report. FSR2 supplies the main-text calibration results; FSR1 is the independent second-layer application reported in Appendix E.

| Path | Current-paper content |
| --- | --- |
| `module_1/FSR1/fit/raw/` | Complete 22-point FSR1 RAW sweep, 0–5000 g. |
| `module_1/FSR2/fit/raw/` | Complete 22-point FSR2 RAW sweep, 0–5000 g. |
| `module_1/*/two_point/` | Shared zero and final-load endpoint models derived from the same sweep. |
| `module_1/*/fit/analysis/` | Frozen 256-cell monotonic inverse models and calibration plots. |
| `module_1/*/evaluation/view_distribution/load_*/` | Current validation captures by recorded load, with RAW predictions and frozen model copies. FSR2 has two capture directories at 140 g; every other recorded load has one. |
| `module_1/*/evaluation/analysis/error/` | Published cumulative LINEAR, GAMMA, FIT PRESS, and Shared LUT error outputs. |
| `module_1/*/evaluation/analysis/dispersion/` | Published CV, variance, IQR, MAD, and supplementary SD outputs. |
| `module_1/*/evaluation/analysis/latest_analysis.json` | Pointer to the retained canonical full-session analysis. |

The capture roots and model copies are read-only evidence. Timestamped analysis histories from superseded reruns and material from earlier calibration workflows are not retained.

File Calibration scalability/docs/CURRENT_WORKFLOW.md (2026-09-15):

# Current paper workflow

## Acquisition

Calibration is performed independently for FSR1 and FSR2 on module M1. For each layer, the operator records a 22-point whole-layer loading sweep from 0 to 5000 g. Every point contains 200 fresh FULL frames; a per-cell temporal median produces one 16x16 RAW ADC matrix. Loading pieces are centred and a silicone pad with rigid support boards distributes the load as evenly as practicable. The experiment reports equivalent whole-layer mass because local force is not measured.

## Calibration models

The zero-load and final-load matrices from the same sweep define the shared two-point endpoints. Four mappings are evaluated on that common range:

- LINEAR uses each cell's measured endpoints.
- GAMMA applies the fixed gamma value of 4 between those endpoints.
- FIT PRESS uses a monotonic per-cell inverse LUT fitted to all sweep points.
- Shared LUT uses one monotonic inverse LUT fitted to the layer-mean response.

The source sweep, endpoint model, fitted model, and source hashes are retained for reproducibility. FSR1 and FSR2 are never pooled as one calibration model.

## Validation and analysis

Validation captures are independent from the training sweep. Each saved capture contains 200 fresh FULL frames, the temporal-median RAW matrix, the four model predictions, and exact endpoint/fitted model copies. FSR2 has 21 captures at 20 distinct loads from 0 to 1969 g; FSR1 has 20 captures at the corresponding distinct loads, with 213 g replacing 212 g.

The evaluation scripts generate single-capture distributions, cumulative load-error summaries, and spatial CV, variance, IQR, and MAD. Capture-to-capture SD is shown only where a load has at least two captures. The 200 frames and 256 cells are not independent loading repeats.

## Reproduction entry points

- script/Main/data_scalability_monitor.py starts acquisition and validation.
- script/Main/Calibration/calibrate_fsr.py derives shared endpoints.
- script/Main/Model/plot_pressure_calibration_monotonic.py fits the 256-cell response model.
- script/Main/Model/plot_calibration_comparison.py generates model comparisons.
- script/Main/Evaluation/analyze_view_distributions.py handles one capture.
- script/Main/Evaluation/analyze_validation_session.py and the companion error/dispersion scripts generate current report summaries.

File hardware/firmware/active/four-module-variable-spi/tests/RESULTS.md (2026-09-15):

# Regression results

Final complete run: **2026-09-06, PASS**. The native regression suite uses MSVC 14.50 C/C++ on Windows and the installed Python environment with NumPy and Matplotlib. The baseline is read directly from the sibling firmware directory.

| Check | Result |
|---|---|
| Real STM32 encoder, 212 shared frame vectors | PASS: old/new lengths and all 1044 output bytes equal |
| Independent CRC32, mask population, output guard bytes | PASS |
| Real PC parsers, all 212 C-generated frames with flags 0x13/0x33 | PASS: both 16×16 matrices and sequence numbers equal after every frame |
| Real Teensy bridge, 17 baseline and 30 candidate frame reads | PASS |
| Candidate 16-byte header plus actual payload under one CS | PASS |
| Bad headers stop after 16 bytes; payload/CRC errors reject | PASS |
| Two MUL1 packets with four ordered module descriptors | PASS: old/new bytes equal |
| Real STM32 acquisition, five pipeline rounds | PASS |
| DMA mode/resync lengths and active-buffer immutability | PASS |
| Six DMA completion/failure scenarios and invalid lengths | PASS |

Encoder stream SHA-256: `190748ac02b39809d34e23361c3a61a66434f331103961917283ba6ad8b22b36`.

Teensy packet stream SHA-256: `758495a3dad14b9920688ca963f4372ff3bcde880e977b916065b05040c4ecbc`.

The PC integration check initially exposed rejection of the real acquisition-status bits. After the PC flag validation was corrected, the entire suite was rerun successfully. The final machine-readable outcomes are in `regression_results.json`.

The tested DMA scenarios are CS held low between header and payload, NSS changing low between the two guard reads, partial reception followed by NSS high, explicit DMA error, no clocks until timeout, and DMA counter zero with no completion callback. A transfer with NSS low is allowed to finish; a partial transfer with NSS high is aborted immediately; an unstarted transfer waits for the existing timeout.

These are offline firmware behavior checks. Real clock gaps, throughput, IRQ latency and electrical behavior are not measured by this suite.

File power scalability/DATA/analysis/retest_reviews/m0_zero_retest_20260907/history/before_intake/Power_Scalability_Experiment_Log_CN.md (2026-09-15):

# Power Scalability 实验日志

> 本文件只记录实验时间线、执行内容和文档变更。历史汇总数据记录在 [power_raw.csv](DATA/raw/canonical/power_raw.csv) 中；新实验的结构化原始记录保存在 `DATA/raw/canonical/power_experiment_records/`。2026-09-06已完成分组分析，结果位于 `DATA/reference/analysis_v2_1/`。以下旧条目保留当时记录状态；空白字段、默认故障计数和预填时长的当前解释以报告2.3及 `POWER_REVISION_2.1_CN.md` 为准，文档修改日期不代替缺失的实验日期。

| 日期 | 时间 | 类型 | run_id | 记录 |
|---|---|---|---|---|
| 2026-09-07 | 用户澄清；非另一次实验 | M3复测SOURCE未重测 | M1-M2-M3 / MAX / M3 | 用户确认3.243/3.243/3.244 V是M3模块端照片值，SOURCE尚未重测。测点身份疑问已解决；新源端电压和新压降保持空值。复测前重新插入connector已确认，旧记录与复测继续分开保存，报告及图未替换。 |
| 2026-09-07 | 用户澄清；非另一次实验 | M3复测接头操作及源端身份 | M1-M2-M3 / MAX / M3 | 用户确认复测前重新插入connector；未确认更换线缆或加载完全相同。SOURCE问题回复3.243/3.243/3.244 V，与M3照片一致，原样存为候选并再次核对测点身份；新压降留空，不记作0 mV。原值和复测分别保留。 |
| 2026-09-07 | 用户提交复测照片；实际起止未提供 | M3定向复测 | M1-M2-M3 / MAX / M3 | 电压主读数/MIN/MAX=3.243/3.243/3.244 V；电流=19.263/19.25/19.41 mA。相对旧3.232 V、19.721 mA变化+11 mV、−0.458 mA；原照片核验复制到targeted_retests。源端电压、接头调整及加载一致性待确认，新压降留空。保留旧44 mV；本次为单模块定向复测，不增加完整配置重复数，不改已发布报告。 |
| 2026-09-07 | 文档发布；非新增实验 | 报告2.3更新 | 15组合×ZERO/MAX | 以2.2为基线存档，纳入30条件/64支路；更新7张Power图及方法、结果、讨论、附录、摘要和结论，最终61页。顺序测量、共享参考、每条件一组、M0 connector及其他数据质量限制保留。同一清单更新，P05部分未勾；动态测试为未来工作。版本与SHA256见Final/report_versions/v2.3/manifest.json。 |
| 2026-09-07 | MAX照片文件名03:34:28–03:53:03；实际测量窗口未记录 | N=3 MAX两组补录及全部Power汇总 | M0-M1-M3、M0-M2-M3；`n3_max_20260907.csv` | 录入14张照片的电压/电流主读数/MIN/MAX及10个温度点。M0-M1-M3：I=19.648/19.805/19.178 mA，合计58.631 mA；Vs3.275 V、模块3.239/3.248/3.243 V；温度27.4/27.3/26.9/42.6/30.0 °C。M0-M2-M3：I=19.505/19.451/19.323 mA，合计58.279 mA；Vs3.275 V、模块3.240/3.242/3.243 V；温度27.2/26.8/26.6/42.6/29.6 °C。顺序测量功率估计192.016525/190.863725 mW。全部15组合×ZERO/MAX已有V/I/T，共30条件、64支路，每条件一组记录；负载质量/面积/分配及故障监测未知项保留。新增`DATA/analysis/current/all_power_review_20260907/`完整汇总；旧ZERO/原始YAML/main 2.1不变。 |
| 2026-09-07 | 同轮目录维护；非实验 | N=3 ZERO照片引用迁移 | M0-M1-M3、M0-M2-M3 | 另核对14张旧ZERO照片（8张电压、6张电流）移入各自zero_load，均与旧来源SHA256一致；连同下方20张N=2照片，迁移映射共34张。M0_new复测照片路径未变，未读入或统计新增N=3 MAX照片。两个ZERO汇总的最新MAX覆盖说明更新为13/15，ZERO全部数值不变。 |
| 2026-09-07 | 新照片文件名02:53:57–03:30:36；实际起止时窗未另记 | 四组N=2 MAX电压、电流及温度录入 | M0-M2、M0-M3、M1-M2、M1-M3；`n2_max_20260907.csv` | 用户明确本次四组为满负载；录入20张照片的主读数/MIN/MAX及16个温度点。电流合计39.357/39.335/39.719/40.016 mA，源端电压3.278/3.278/3.277/3.277 V；输出侧功率估计129.012246/128.940130/130.159163/131.132432 mW。电压与电流分次读取，各组合仍一组记录；负载质量/面积/分配未知，不复制旧2000 g字段。N=2 ZERO/MAX均6/6，整体MAX13/15，仅缺M0-M1-M3与M0-M2-M3。详细温度、支路V/I及照片映射见新补充CSV和`DATA/analysis/current/n2_max_review_20260907/`；旧ZERO、M0接头事件、冻结分析及main 2.1未改。 |
| 2026-09-07 | 目录维护；非实验 | N=2 ZERO照片引用迁移 | 四个补充双模块组合 | 核对20张旧ZERO照片已由组合根目录移入各自zero_load，SHA256与旧清单一致。修复当前分析的来源路径并保留原引用；迁移表和修改前派生文件保存于`DATA/analysis/provenance/path_relocation_20260907/`。原始YAML/CSV字节和照片内容不变，不将本次MAX照片混入ZERO。 |
| 2026-09-07 | 用户补充确认；非新增重复实验 | N=3 ZERO MIN补录 | M0-M1-M3的M0 | 用户明确确认MIN为18.00 mA；主读数18.005 mA、MAX18.03 mA保持不变，照片无法读取的MIN来源标为用户确认。此次补录解决下方同日条目的待确认项，全部32个空载支路现有主读数/MIN/MAX；电流合计和功率估计不变。 |
| 2026-09-07 | 新电流照片文件名02:15:24–02:27:55；温度由用户消息提供 | 两组N=3 ZERO电流/温度补录 | M0-M1-M3、M0-M2-M3 | 依模块编号顺序录入六条支路电流，合计54.159/54.130 mA；每组三个STM32、Teensy、regulator温度分别27.4/26.7/26.9/42.7/29.6 °C及27.4/26.6/26.6/42.6/29.2 °C。电压沿用此前对应组合记录，功率为跨记录估计。M0-M1-M3的M0 MIN无法从照片下部辨认，保持空值待确认；主读数18.005及MAX18.03 mA明确。整体空载电压、电流主读数和温度覆盖15/15，每组合仍一组电流记录。结果存`DATA/analysis/current/zero_power_review_20260907/`；原始YAML、旧分析及main 2.1未改。 |
| 2026-09-07 | 用户范围确认；无新增实验 | 未来工作与故障记录解释 | — | 将启动峰值、供电纹波、负载切换波形和持续温升曲线明确列为未来工作，本轮不要求补测，也不标记为已验证。解释故障计数默认0与实际监测结果的区别，未知观察方式/时窗保持未确认；M0 connector事件保留。更新方案及修订说明，原始测量、统计和main 2.1均未改。 |
| 2026-09-07 | 用户补充确认；非新增重复实验 | N=2 ZERO MIN补录 | M0-M3的M3 | 将此前反光无法辨认的MIN补录为用户确认的17.89 mA；主读数17.922 mA和MAX 18.05 mA保持不变。12/12支路现均有主读数/MIN/MAX数值，来源中明确该MIN来自用户确认；电流合计、功率与组合间统计不变。此前缺失状态及数据版本已保存，main 2.1未改。 |
| 2026-09-07 | 新电流照片文件名01:08:53–01:27:49；温度由用户最新消息提供 | 四组N=2 ZERO电流/温度补录和六组合统计 | `n2_zero_20260907.csv`关联M0-M2、M0-M3、M1-M2、M1-M3既有电压记录 | 按模块编号顺序转录8张电流照片，最新regulator温度分别29.3/29.2/29.1/28.8 °C。六组合分支主读数合计35.907–36.561 mA，组合间36.263±0.265 mA；输出侧功率估计118.907±0.848 mW。新增四组合的电压/电流来自不同记录；每组合一组电流记录，不能把补录当重复。M0-M3的M3 MIN反光不可读，保持空；旧M0-M1的M1主读数/MIN差异保留。结果存`DATA/analysis/current/n2_zero_review_20260907/`，原YAML/照片、冻结分析及main 2.1均未改。 |
| 2026-09-07 | 用户澄清；无新增测量 | M0 connector故障范围修正 | `PS01_N3_F200_ZERO_M0-M1-M2_USB_RX_R1`及其M0复测 | 用户确认只有M0 connector接触不良，其他电压测点未受影响、沿用原值。因此撤销整条运行排除，保留源端3.276 V、M1 3.250 V、M2 3.246 V，M0采用复测3.241 V；逐点来源保留。空载电压配置覆盖达到15/15。M0的35 mV压降为采用已确认未变源端值的修订估计，未声称新增同步采集或增加重复。原始YAML/照片与PDF不改；此前范围说明已存档。 |
| 2026-09-07 | 新组合照片文件名00:05:39–00:23:43；M0_new.jpg未给运行起止时间 | 三模块ZERO电压补录与供电接触故障登记 | `PS01_N3_F200_ZERO_{M0-M1-M3,M0-M2-M3}_USB_RX_VOLTAGE_R1`；`PS01_N3_F200_ZERO_M0-M1-M2_USB_RX_VOLTAGE_RETEST_R1` | 补录两组各4个电压测点和M0复测3.241 V。用户确认旧M0的3.224 V由供电线/接头接触不良导致，按实际供电异常工况保存，未改写原YAML。独立事件JSON关联旧记录与复测；修复后没有同次源端/M1/M2及电流，保持缺测，不与旧值合成运行或计算重复SD。报告2.1尚未更新。 |
| 2026-09-06 | 照片文件名23:19:27–23:39:28；实际运行起止未另记 | 四组双模块ZERO电压补录 | `PS01_N2_F200_ZERO_{M0-M2,M0-M3,M1-M2,M1-M3}_USB_RX_VOLTAGE_R1` | 根据12张照片新增4条仅电压记录。用户确认按模块编号递增测量；每组首张电源端身份依既有顺序推定并注明。保存主读数/MIN/MAX及逐测点照片映射，缺失电流、温度、时长及故障观察保持空白。N=2 ZERO电压覆盖达到6种组合，未增加加载或独立重复证据。原照片、已有原始数据及main 2.1保持不变。 |
| 2026-09-06 | 未记录 | 分析与报告修订（无新增实验） | 18条USB_RX及13条旧CSV记录 | 按持续USB接收与阻塞待机分开分析，排除11条重复的待机YAML映射。保留原始数据，新增analysis_v2_1派生结果、独立单模块预测、加载差异和QC标记；更新7幅Power图及报告2.1。N=4空载/加载支路电流合计为72.513/78.720 mA。每确定条件仍只有R1，未补写未知日期、实际预热/观察时长、加载分配及故障日志。原Word清单新增勾选7项Power任务，P05保留部分完成。 |
| 2026-09-05 | 未记录 | N=3 Zero 记录补录 | `PS01_N3_F200_ZERO_M0-M1-M2_USB_RX_R1`, `PS01_N3_F200_ZERO_M1-M2-M3_USB_RX_R1` | 按照片拍摄时间和模块测试顺序补录源端电压、各模块电压及各支路电流，并保留此前补录的 STM32、Teensy 和稳压器温度。M0-M1-M2 的模块顺序为 M0、M1、M2；M1-M2-M3 的模块顺序为 M1、M2、M3。两条记录标记为 `MEASURED`，数据质量为 `INCOMPLETE`。个别主读数与 MAX/MIN 存在小数位舍入差异，保留照片显示值。 |
| 2026-09-05 | 未记录 | M2-M3 温度补录 | `PS01_N2_F200_ZERO/FULL_M2-M3_USB_RX_R1` | 根据桌面记录补录 M2、M3 的 STM32 温度，以及 Teensy、稳压器温度。两条记录更新为 `MEASURED`，但电压、电流和满载信息仍未提供，因此数据质量保留为 `INCOMPLETE`。 |
| 2026-09-05 | 未记录 | M0-M1 记录补录 | `PS01_N2_F200_ZERO/FULL_M0-M1_USB_RX_R1` | 按照片拍摄时间将较早读数分配给 M0、较晚读数分配给 M1，补录源端电压、两路模块电压和两路支路电流；根据桌面记录补录 M0、M1 的 STM32 温度以及 Teensy、稳压器温度。两条记录更新为 `MEASURED`，数据质量保留为 `INCOMPLETE`。Zero load 下 M1 的主电流读数为 `18.055 mA`，照片显示最小值为 `18.06 mA`，差异来自显示精度，未擅自修正。 |
| 2026-09-05 | 未记录 | 图片读数与温度补录 | `PS01_N1_F200_*_M1/M2/M3_USB_RX_R1` | 根据 transmission/N=1 文件夹中的新照片补录 M1、M2 的源端和模块端电压；根据桌面记录补录 M1、M2、M3 的 STM32、稳压器和 Teensy 温度。6 个记录状态更新为 `MEASURED`，数据质量保留为 `INCOMPLETE`；M1/M2 满载未观察到额外瞬时峰值，记为 `N/A`。照片与记录未提供满载质量、加载面积和加载方式，因此这些字段仍留空。 |
| 2026-09-05 | 未记录 | 记录模板修正 | `PS01_N1_F200_*_M*_USB_RX_R1` | 按当前供电证据，将 N=1 transmission 的 8 个模板中的 `power_supply_current_limit_setting_mA` 统一填写为 `NOT_AVAILABLE`；现有资料仅确认 LM2596 芯片额定输出能力为 3 A，未确认实际模块的可调限流设定。将 `PS01_N1_F200_ZERO_M0_USB_RX_R1` 修正为 `warmup_duration_s: 30`、`measurement_duration_s: 10`。日期、开始时间、操作者、观察和结论继续留空。 |
| 2026-09-05 | 未记录 | 图片读数补录 | `PS01_N1_F200_MAX_M0_USB_RX_R1`, `PS01_N1_F200_MAX_M1_USB_RX_R1`, `PS01_N1_F200_MAX_M2_USB_RX_R1` | 根据各实验文件夹中的万用表图片补录支路电流：M0 Full 为 `19.689 mA`（`19.52–19.69 mA`），M1 Full 为 `20.11 mA`（`20.06–20.12 mA`），M2 Full 为 `19.897 mA`（`19.86–19.93 mA`）。图片未能可靠提供完整温度或电压统计，因此未补写这些字段。 |
| 2026-09-05 | 未记录 | 旧数据归档 | `no_transmission`，N=1–4 | 将 `power_raw.csv` 中已有且与当前 200 Hz 模板对应的 11 条待机记录写入 `no_transmission`；这些记录标记为 `MEASURED`，数据质量保留为 `INCOMPLETE`。未对应的 100 Hz 历史记录继续保留在 `power_raw.csv`，未创建额外模板；未测得的 Full load 和其他组合保持为空。 |
| 2026-09-05 | 未记录 | 实验结构调整 | `no_transmission` | 按当前实验目标删除 7 个不需要的 `Full load` 模板：N=1 的 M2/M3，以及 N=2–4 的全部组合。`no_transmission` 仅保留各组合的 `Zero load`，并保留 N=1 的 M0/M1 `Full load`，用于比较负载变化下的单模块功耗。 |
| 2026-09-04 | 未记录 | 数据标记 | — | 在 `power_raw.csv` 中新增 `host_usb_polling_state` 字段；现有 13 条 Power 记录全部标记为 `BLOCKED_STANDBY_NO_CONTINUOUS_USB_READ`，数值未修改。后续 USB 持续接收的通路测试标记为 `CONTINUOUS_USB_READ`。 |
| 2026-09-04 | 未记录 | 文件清理 | — | 按要求删除 `DATA/rawdata/` 及其中的 M3 压降诊断记录、M1+M2+M3 填写模板和旧版 N=4 历史备份；当前分析数据 `power_raw.csv` 未删除。 |
| 2026-09-04 | 未记录 | 数据修正 | `PS01_N1_F200_ZERO_M3_R1` | 更正 N=1、Module 3、200 Hz、`FULL`、`ZERO` 记录中的模块电压：平均值 `3.265 V`、最小值 `3.264 V`、最大值 `3.266 V`；其他字段不变。 |
| 2026-09-04 | 未记录 | 数据更新 | `PS01_N3_F200_ZERO_M1_M2_M3_R1` | 将 Module 1 + Module 2 + Module 3 的三模块、200 Hz、`FULL`、`ZERO` 联合测试数据写入 `power_raw.csv`；源端平均电流按三条支路平均值之和记录为 `24.910 mA`，故障计数填写为 `0`。温度字段沿用 M1/M2/M3 原始参考记录，并标明不是本次联合运行的同步温度；记录仍为 `INCOMPLETE`。重新生成分析后，N=3 汇总同时包含 M0+M1+M2 和 M1+M2+M3 两种组合。 |
| 2026-09-04 | 未记录 | 实验准备 | `PS01_N3_F200_ZERO_M1_M2_M3_R1` | 曾生成 Module 1 + Module 2 + Module 3 的三模块联合测试填写模板；该模板已按要求删除，未参与 `power_raw.csv` 或现有分析。 |
| 2026-09-04 | 未记录 | 实验记录 | `PS01_M3DROP_A_R1` | 曾完成四模块 M3 压降初步诊断；原始诊断文件已按要求删除，本记录未并入 `power_raw.csv` 或现有分析图表。 |
| 2026-09-04 | 未记录 | 数据修正 | `PS01_M3DROP_A_R1` | 交换原始记录中的 M3 电压最小值和最大值：`3.262 V` → `V_module3_max_V`，`3.259 V` → `V_module3_min_V`；同步将计算的下限余量修正为 `124 mV`。 |
| 2026-09-04 | 未记录 | 数据更新 | `PS01_N4_F200_ZERO_R1` | 将活动 `N=4` 源行更新为新的四模块记录：总平均电流 `32.492 mA`，源电压 `3.278 V`，模块电压与支路电流采用 `PS01_M3DROP_A_R1`；旧版历史备份曾单独保留，现已按要求删除。仅重新生成 Results 所引用的 Power 图，正文文字未改。 |
| 2026-09-04 | 未记录 | 实验记录 | `PS01_N2_F200_ZERO_M2_M3_R1` | 新增 Module 2 + Module 3 的两模块、200 Hz、`FULL`、`ZERO` 稳态记录；源端平均电流按全部模块支路平均电流之和记录为 `16.646 mA`；未填写的故障计数统一记录为 `0`。温度字段沿用原始 M2/M3 参考记录，并标明不是本次联合运行的同步温度；记录仍为 `INCOMPLETE`。 |
| 2026-08-31 | 16:22 | 实验 | `PS01_N1_F100_ZERO_M0_R1` | 开始 Module 0、100 Hz、`FULL`、`ZERO` 的 PS-01 稳态实验；外部 3.3 V 供电；完成电压、电流、温度和系统状态采集。数据已写入 `power_raw.csv`。 |
| 2026-08-31 | 未记录 | 数据修正 | `PS01_N1_F100_ZERO_M0_R1` | 重新连接并使用 mA 量程复测电流；将 CSV 中原电流读数替换为约 8.13 mA，最小 8.112 mA，最大 14.5 mA；标记最大值为短时峰值。 |
| 2026-08-31 | 未记录 | 数据修正 | `PS01_N1_F100_ZERO_M0_R1` | 更新 Module 0 输入端电压：平均值 3.267 V，最小值 3.266 V，最大值 3.267 V。 |
| 2026-08-31 | 未记录 | 供电配置 | — | 确认当前 3.3 V 供电模块为 LM2596；下载并保存 TI datasheet。记录芯片级 3 A 输出能力及 3.6/4.5/6.9 A 峰值限流参数；具体模块限流设定仍待确认。 |
| 2026-08-31 | 16:54 | 实验准备 | `PS01_N1_F200_ZERO_M0_R1` | 准备 Module 0、200 Hz、`FULL`、`ZERO` 实验；除频率由 100 Hz 改为 200 Hz 外，其他条件保持不变。 |
| 2026-08-31 | 17:00 | 实验记录 | `PS01_N1_F200_ZERO_M0_R1` | 确认实际测量开始时间为 17:00；记录数值与 100 Hz 完全一致。初步判断在当前单模块、无负载条件下，频率变化对供电数据没有明显影响；该判断仍需更多重复实验确认。 |
| 2026-08-31 | 17:02 | 实验记录 | `PS01_N1_F200_MAX_M0_R1` | 完成 Module 0、200 Hz、`FULL`、`MAX` 满负载实验；测量值与 100 Hz 和 200 Hz 的 `ZERO` 记录完全一致，作为结束单模块负载筛查并转入多模块扩展实验的依据。 |
| 2026-08-31 | 17:10 | 实验开始 | `PS01_N1_F100_ZERO_M1_R1` | 更换为 Module 1，保持 100 Hz、`FULL`、`ZERO`、LM2596 3.3 V 和 mA 量程不变，用于与 Module 0 的 100 Hz 无负载基线直接比较。若结果一致，将该条件作为后续多模块扩展实验的固定基线。 |
| 2026-08-31 | 未记录 | 实验记录 | `PS01_N1_F100_ZERO_M1_R1` | 完成 Module 1、100 Hz、`FULL`、`ZERO` 测量并写入 CSV；模块电压统计值存在均值高于最大值的不一致，且模块电流与测量开始时间未提供，本次暂记为 `INCOMPLETE`。 |
| 2026-08-31 | 未记录 | 实验记录 | `PS01_N1_F200_ZERO_M1_R1` | 补录 Module 1、200 Hz、`FULL`、`ZERO` 实验；数值与 Module 1 的 100 Hz、`ZERO` 记录完全一致。 |
| 2026-08-31 | 未记录 | 实验记录 | `PS01_N1_F200_MAX_M1_R1` | 补录 Module 1、200 Hz、`FULL`、`MAX` 实验；数值与 Module 1 的 100 Hz、`ZERO` 及 200 Hz、`ZERO` 记录完全一致。 |
| 2026-08-31 | 17:41 | 实验记录 | `PS01_N1_F200_ZERO_M2_R1` | 完成 Module 2、200 Hz、`FULL`、`ZERO` 测量并写入 CSV；模块支路电流未提供，本次暂记为 `INCOMPLETE`。 |
| 2026-08-31 | 17:41 | 实验记录 | `PS01_N1_F200_ZERO_M3_R1` | 完成 Module 3、200 Hz、`FULL`、`ZERO` 测量并写入 CSV；模块支路电流和测量开始时间未提供，本次暂记为 `INCOMPLETE`。 |
| 2026-08-31 | 未记录 | 方案调整 | — | 对比已记录的 200 Hz `ZERO` 与 `MAX` 单模块数据后，停止后续单模块频率/负载筛查；后续正式实验固定为 200 Hz、`FULL`、`ZERO`，从多模块数量扩展开始。历史单模块数据保留在 CSV 中。 |
| 2026-08-31 | 未记录 | 数据修正 | `PS01_N1_F200_ZERO_M1_R1` | 更正 Module 1 的温度字段：稳压器温度与 Teensy 温度原先对调，已交换为正确位置。 |
| 2026-08-31 | 未记录 | 数据修正 | `PS01_N1_F200_ZERO_M2_R1` | 更正 Module 2 的温度字段：稳压器温度与 Teensy 温度原先对调，已交换为正确位置。 |
| 2026-08-31 | 未记录 | 数据修正 | `PS01_N1_F100_ZERO_M1_R1`、`PS01_N1_F200_ZERO_M1_R1`、`PS01_N1_F200_MAX_M1_R1` | 将 Module 1 三条记录的模块电压最大值统一修正为 3.271 V，解决平均值高于最大值的不一致；其他数据不变。 |
| 2026-08-31 | 未记录 | 文档变更 | — | 确认电流测量值单位为 A；`DMM_current_range` 单独记录仪器量程，不作为电流值单位。 |
| 2026-08-31 | 未记录 | 实验记录 | `PS01_N2_F200_ZERO_R1` | 完成 Module 0 + Module 1、200 Hz、`FULL`、`ZERO` 双模块测量；分别测量两条支路电流，并计算总平均电流。 |
| 2026-08-31 | 未记录 | 实验记录 | `PS01_N3_F200_ZERO_R1` | 完成 Module 0 + Module 1 + Module 2、200 Hz、`FULL`、`ZERO` 三模块测量并写入 CSV；Module 0 的模块电压最小值和最大值填写顺序异常，本次暂记为 `INCOMPLETE`。 |
| 2026-08-31 | 未记录 | 数据修正 | `PS01_N3_F200_ZERO_R1` | 将 Module 0 的模块电压最小值和最大值位置互换为 `3.262 V` 和 `3.264 V`；其他数据不变。 |
| 2026-08-31 | 未记录 | 实验记录 | `PS01_N4_F200_ZERO_R1` | 完成 Module 0 + Module 1 + Module 2 + Module 3、200 Hz、`FULL`、`ZERO` 四模块测量并写入 CSV；Module 1 的模块电压最大值与平均值不一致，本次暂记为 `INCOMPLETE`。 |
| 2026-08-31 | 未记录 | 数据修正 | `PS01_N4_F200_ZERO_R1` | 将 Module 1 的模块电压最大值由 `2.254 V` 修正为 `3.254 V`；其他数据不变。 |
| 2026-08-31 | 未记录 | 文档变更 | — | 将已完成的实验数据从 Markdown 迁移到 `power_raw.csv`；本日志删除具体测量值和重复操作说明，仅保留时间线。 |
| 2026-08-31 | 未记录 | 文档变更 | — | 将当前 CSV 中的电流字段、数值和单位统一改为 `mA`；历史记录中的 A 说明保留为变更过程。 |
| 2026-09-01 | 未记录 | 数据分析 | `PS01_N1–N4_F200_ZERO_R1` | 保持 `power_raw.csv` 不变；建立可复现分析脚本，生成电流/功耗、供电电压、支路压降、支路电流、温度、峰值上界图及派生 CSV/JSON，并将初步结论与异常值写入测量计划。 |
| 2026-09-01 | 未记录 | 文档变更 | — | 在 Power Scalability 报告中声明：当前四模块硬件实测具有很大的电源电流容量余量；通过减少扫描量降低功耗的空间稀疏算法不纳入本报告，留待独立 Data Scalability 评估。 |
| 2026-09-02 | 03:02 BST | 图表更新 | — | 使用 scientific-visualization、matplotlib 和 Markdown 技能更新全部 7 张分析图；统一样式并补充测量限制，导出高清 PNG 与 PDF/SVG，保存绘图样式、校验脚本和图表目录；原始 CSV 与 5 份派生 CSV 的校验值不变，未新增实验。 |
| 2026-09-02 | 11:34 BST | 报告编写 | — | 依据 MSc booklet 第 10–12 页，将 Power Methods、Results 和简要 Discussion 提纲写入 Final Report 模板；正文复用 3 图、附录保留 4 图，增加方法表、数据溯源及待补清单；原始数据不变，动态测试仍未完成。 |
| 2026-09-02 | 未记录 | 图表与报告变更 | — | 清理报告中全部 7 张 Power 图：移除图内标题、副标题、页眉、底部注释和重复面板标题；保留坐标、图例、数据编码及必要数值标注，并将条件、拟合公式、样本基础和限制移入图题；重新生成并编译报告，原始及派生 CSV 不变。 |
| 2026-09-02 | 未记录 | 图表与报告变更 | `voltage_scaling` | 删除电压图中的黑色最低值曲线；保留 Module 3 的最低值数值标注，并在报告图题中说明电源平均值和最差模块平均值的计算方式；重新生成并编译报告，原始及派生 CSV 不变。 |
| 2026-09-02 | 未记录 | 图表与报告变更 | `voltage_scaling` | 为蓝色电源平均值曲线的每个点增加具体电压；为橙色最差模块平均值曲线的每个点增加对应模块编号和电压；派生 `power_scaling.csv` 增加 `worst_module_id` 供标注使用，原始测量值和计算规则不变。 |

## 数据文件

- [power_raw.csv](DATA/raw/canonical/power_raw.csv)：实验条件、原始测量值、状态、观察和结论。
- [Power_Scalability_Measurement_Plan_CN.md](Power_Scalability_Measurement_Plan_CN.md)：实验设计、测量量、计算量和通过条件。
- M1+M2+M3 联合测试模板：曾用于单次三模块 Power 测试填写，现已按要求删除。

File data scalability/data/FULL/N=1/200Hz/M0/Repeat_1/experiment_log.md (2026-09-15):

# Experiment 20260906_225934_745706

Started: 2026-09-06T22:59:34.745706+01:00
Actual duration: 40.001560 s; requested: 40 s; settle: 10 s.
Result (main window): PASS: main window checks passed

## Conditions

```json
{
  "target_modules": [
    0
  ],
  "module_selection_source": "automatic",
  "target_mode": "FULL",
  "target_hz": 200,
  "delta_threshold": 8,
  "spi_setting_hz": 10000000,
  "condition": "zero_load",
  "block": "1",
  "repeat": "1",
  "operator": "",
  "load_protocol_id": "",
  "load_layers": "unspecified",
  "load_notes": "",
  "notes": "",
  "deployment_note": "",
  "deployment_confirmed": false,
  "board_identity_handling": "slots_only",
  "physical_modules_to_slots": {},
  "board_identity_source": "unknown_not_transmitted_by_protocol",
  "target_hz_source": "GUI default 200 Hz; not firmware readback",
  "module_detection_at_record": {
    "source": "recent_successful_protocol_slots_not_board_uids",
    "ready": true,
    "modules": [
      0
    ],
    "mode": "FULL",
    "slot_modes": {
      "0": "FULL"
    },
    "slot_last_success_monotonic": {
      "0": 185771.8387738
    },
    "last_packet_monotonic": 185771.8387738,
    "observed_at_monotonic": 185771.8387738,
    "window_span_seconds": 1.499573600012809,
    "window_seconds": 1.5,
    "stale_seconds": 0.5,
    "packet_count": 301,
    "limitation": "No response cannot establish whether a board is physically attached. The recent union can retain a briefly missing slot; recording freezes the set."
  },
  "observed_mode_at_record": "FULL",
  "observed_mul1_rate_at_record_Hz": 200.08132658732444,
  "spi_setting_source": "local firmware configuration; not measured or read back",
  "delta_threshold_source": "local firmware configuration; not measured or read back",
  "module_identity_source": "CS/IRQ slot; protocol carries no unique board identity",
  "N": 1,
  "M": 4,
  "local_provenance": {
    "source": "local_files_not_device_flash_readback",
    "firmware_variant": "four-module-variable-spi",
    "files": {
      "stm32_elf": {
        "path": "D:\\study\\programming\\ESKIN\\E-SKIN\\hardware\\new\\firmware\\active\\four-module-variable-spi\\stm32\\combined-system\\build\\Release\\ESKIN_STM32.elf",
        "sha256": "8fb1791504f3c2bf23dce9d57ca9b877b8cd1653d167dfe5a58b0c5176c4c8b6"
      },
      "teensy_hex": {
        "path": "D:\\study\\programming\\ESKIN\\E-SKIN\\hardware\\new\\firmware\\active\\four-module-variable-spi\\build\\teensy\\four_module.ino.hex",
        "sha256": "32a95ff60bef1029a8b25a62d4ece524abc97813955e6586fc50fc9bf4cd2a67"
      },
      "pc_monitor": {
        "path": "D:\\study\\programming\\ESKIN\\E-SKIN\\hardware\\new\\firmware\\active\\four-module-variable-spi\\pc\\four-module-fsr-monitor.py",
        "sha256": "f3cb2910054e26300a223cbac611e08eb4eae6ac6fa2a60ebd3c414695758949"
      },
      "pc_recorder": {
        "path": "D:\\study\\programming\\ESKIN\\E-SKIN\\hardware\\new\\firmware\\active\\four-module-variable-spi\\pc\\experiment_recording.py",
        "sha256": "aff5787daa91bdb16719b0601d71707307e9d3471f636192cc5308445bf1b9ed"
      },
      "pc_controls": {
        "path": "D:\\study\\programming\\ESKIN\\E-SKIN\\hardware\\new\\firmware\\active\\four-module-variable-spi\\pc\\experiment_controls.py",
        "sha256": "9e7ff3b5678de04c46dbf9653385e7dbac9a8ec59f95737122020de50299b194"
      },
      "pc_module_detection": {
        "path": "D:\\study\\programming\\ESKIN\\E-SKIN\\hardware\\new\\firmware\\active\\four-module-variable-spi\\pc\\module_detection.py",
        "sha256": "52e35e8991c13e70e8f1e64d7b32d6b25bfa0fa7aeda8ec2333033540eb59ec1"
      }
    }
  },
  "batch_id": "BATCH_a3da6b70a7684d359fd18d817b963390",
  "batch_repeat_index": 1,
  "batch_repeat_count": 3,
  "batch_recording_method": "consecutive_capture_windows_same_setup",
  "batch_interpretation": "Temporal repeats under one setup; not independent setup blocks or automatic reloading",
  "batch_initial_observations": "GUI at_record fields describe the initial batch request; each run measures its own statistics",
  "module_detection_at_repeat_start": {
    "source": "recent_successful_protocol_slots_not_board_uids",
    "ready": true,
    "modules": [
      0
    ],
    "mode": "FULL",
    "slot_modes": {
      "0": "FULL"
    },
    "slot_last_success_monotonic": {
      "0": 185771.8439825
    },
    "last_packet_monotonic": 185771.8439825,
    "observed_at_monotonic": 185771.8502633,
    "window_span_seconds": 1.490694899985101,
    "window_seconds": 1.5,
    "stale_seconds": 0.5,
    "packet_count": 300,
    "limitation": "No response cannot establish whether a board is physically attached. The recent union can retain a briefly missing slot; recording freezes the set."
  },
  "module_detection_at_worker_start": {
    "source": "recent_successful_protocol_slots_not_board_uids",
    "ready": true,
    "modules": [
      0
    ],
    "mode": "FULL",
    "slot_modes": {
      "0": "FULL"
    },
    "slot_last_success_monotonic": {
      "0": 185771.8439825
    },
    "last_packet_monotonic": 185771.8439825,
    "observed_at_monotonic": 185771.850355,
    "window_span_seconds": 1.490694899985101,
    "window_seconds": 1.5,
    "stale_seconds": 0.5,
    "packet_count": 300,
    "limitation": "No response cannot establish whether a board is physically attached. The recent union can retain a briefly missing slot; recording freezes the set."
  },
  "pre_record_commands": [],
  "stream_start_offset": 2615089,
  "live_parser_buffer_bytes_at_start": 1,
  "live_parser_continuous_across_recordings": true,
  "module_count": 1,
  "algorithm": "FULL",
  "modules": [
    "M0"
  ],
  "active_module_ids": [
    "M0"
  ],
  "scan_hz": 200,
  "target_scan_rate_hz": 200,
  "load_label": "zero_load"
}
```

## Scope checks

- full_run: CHECK REQUIRED; 40.001560 s; 8004 valid MUL1; 8004/8004 target updates.
  Review reasons: unassigned_raw_bytes_in_full_capture.
- main: PASS; 30.001560 s; 6003 valid MUL1; 6003/6003 target updates.
  Review reasons: none.

Raw bytes are assigned by chunk arrival; complete packet bytes by completion time.
Start-boundary packets: 1; suffixes are audited separately and excluded from complete packet rates, K and q.
Missing updates and unknown initial cache prefixes are not proven physical-scan losses.
Local artifact hashes identify source/build files; no device flash readback was performed by this recorder.

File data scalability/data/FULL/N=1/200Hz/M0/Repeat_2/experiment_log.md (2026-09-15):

# Experiment 20260906_230014_784220

Started: 2026-09-06T23:00:14.784220+01:00
Actual duration: 40.002489 s; requested: 40 s; settle: 10 s.
Result (main window): PASS: main window checks passed

## Conditions

```json
{
  "target_modules": [
    0
  ],
  "module_selection_source": "automatic",
  "target_mode": "FULL",
  "target_hz": 200,
  "delta_threshold": 8,
  "spi_setting_hz": 10000000,
  "condition": "zero_load",
  "block": "1",
  "repeat": "2",
  "operator": "",
  "load_protocol_id": "",
  "load_layers": "unspecified",
  "load_notes": "",
  "notes": "",
  "deployment_note": "",
  "deployment_confirmed": false,
  "board_identity_handling": "slots_only",
  "physical_modules_to_slots": {},
  "board_identity_source": "unknown_not_transmitted_by_protocol",
  "target_hz_source": "GUI default 200 Hz; not firmware readback",
  "module_detection_at_record": {
    "source": "recent_successful_protocol_slots_not_board_uids",
    "ready": true,
    "modules": [
      0
    ],
    "mode": "FULL",
    "slot_modes": {
      "0": "FULL"
    },
    "slot_last_success_monotonic": {
      "0": 185771.8387738
    },
    "last_packet_monotonic": 185771.8387738,
    "observed_at_monotonic": 185771.8387738,
    "window_span_seconds": 1.499573600012809,
    "window_seconds": 1.5,
    "stale_seconds": 0.5,
    "packet_count": 301,
    "limitation": "No response cannot establish whether a board is physically attached. The recent union can retain a briefly missing slot; recording freezes the set."
  },
  "observed_mode_at_record": "FULL",
  "observed_mul1_rate_at_record_Hz": 200.08132658732444,
  "spi_setting_source": "local firmware configuration; not measured or read back",
  "delta_threshold_source": "local firmware configuration; not measured or read back",
  "module_identity_source": "CS/IRQ slot; protocol carries no unique board identity",
  "N": 1,
  "M": 4,
  "local_provenance": {
    "source": "local_files_not_device_flash_readback",
    "firmware_variant": "four-module-variable-spi",
    "files": {
      "stm32_elf": {
        "path": "D:\\study\\programming\\ESKIN\\E-SKIN\\hardware\\new\\firmware\\active\\four-module-variable-spi\\stm32\\combined-system\\build\\Release\\ESKIN_STM32.elf",
        "sha256": "8fb1791504f3c2bf23dce9d57ca9b877b8cd1653d167dfe5a58b0c5176c4c8b6"
      },
      "teensy_hex": {
        "path": "D:\\study\\programming\\ESKIN\\E-SKIN\\hardware\\new\\firmware\\active\\four-module-variable-spi\\build\\teensy\\four_module.ino.hex",
        "sha256": "32a95ff60bef1029a8b25a62d4ece524abc97813955e6586fc50fc9bf4cd2a67"
      },
      "pc_monitor": {
        "path": "D:\\study\\programming\\ESKIN\\E-SKIN\\hardware\\new\\firmware\\active\\four-module-variable-spi\\pc\\four-module-fsr-monitor.py",
        "sha256": "f3cb2910054e26300a223cbac611e08eb4eae6ac6fa2a60ebd3c414695758949"
      },
      "pc_recorder": {
        "path": "D:\\study\\programming\\ESKIN\\E-SKIN\\hardware\\new\\firmware\\active\\four-module-variable-spi\\pc\\experiment_recording.py",
        "sha256": "aff5787daa91bdb16719b0601d71707307e9d3471f636192cc5308445bf1b9ed"
      },
      "pc_controls": {
        "path": "D:\\study\\programming\\ESKIN\\E-SKIN\\hardware\\new\\firmware\\active\\four-module-variable-spi\\pc\\experiment_controls.py",
        "sha256": "9e7ff3b5678de04c46dbf9653385e7dbac9a8ec59f95737122020de50299b194"
      },
      "pc_module_detection": {
        "path": "D:\\study\\programming\\ESKIN\\E-SKIN\\hardware\\new\\firmware\\active\\four-module-variable-spi\\pc\\module_detection.py",
        "sha256": "52e35e8991c13e70e8f1e64d7b32d6b25bfa0fa7aeda8ec2333033540eb59ec1"
      }
    }
  },
  "batch_id": "BATCH_a3da6b70a7684d359fd18d817b963390",
  "batch_repeat_index": 2,
  "batch_repeat_count": 3,
  "batch_recording_method": "consecutive_capture_windows_same_setup",
  "batch_interpretation": "Temporal repeats under one setup; not independent setup blocks or automatic reloading",
  "batch_initial_observations": "GUI at_record fields describe the initial batch request; each run measures its own statistics",
  "module_detection_at_repeat_start": {
    "source": "recent_successful_protocol_slots_not_board_uids",
    "ready": true,
    "modules": [
      0
    ],
    "mode": "FULL",
    "slot_modes": {
      "0": "FULL"
    },
    "slot_last_success_monotonic": {
      "0": 185811.8478074
    },
    "last_packet_monotonic": 185811.8478074,
    "observed_at_monotonic": 185811.88651,
    "window_span_seconds": 1.4597060999949463,
    "window_seconds": 1.5,
    "stale_seconds": 0.5,
    "packet_count": 293,
    "limitation": "No response cannot establish whether a board is physically attached. The recent union can retain a briefly missing slot; recording freezes the set."
  },
  "pre_record_commands": [],
  "stream_start_offset": 11292509,
  "live_parser_buffer_bytes_at_start": 1,
  "live_parser_continuous_across_recordings": true,
  "module_count": 1,
  "algorithm": "FULL",
  "modules": [
    "M0"
  ],
  "active_module_ids": [
    "M0"
  ],
  "scan_hz": 200,
  "target_scan_rate_hz": 200,
  "load_label": "zero_load"
}
```

## Scope checks

- full_run: CHECK REQUIRED; 40.002489 s; 8011 valid MUL1; 8011/8011 target updates.
  Review reasons: unassigned_raw_bytes_in_full_capture.
- main: PASS; 30.002489 s; 6003 valid MUL1; 6003/6003 target updates.
  Review reasons: none.

Raw bytes are assigned by chunk arrival; complete packet bytes by completion time.
Start-boundary packets: 1; suffixes are audited separately and excluded from complete packet rates, K and q.
Missing updates and unknown initial cache prefixes are not proven physical-scan losses.
Local artifact hashes identify source/build files; no device flash readback was performed by this recorder.

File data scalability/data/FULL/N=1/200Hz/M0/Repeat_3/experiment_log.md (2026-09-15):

# Experiment 20260906_230054_835519

Started: 2026-09-06T23:00:54.835519+01:00
Actual duration: 40.000773 s; requested: 40 s; settle: 10 s.
Result (main window): PASS: main window checks passed

## Conditions

```json
{
  "target_modules": [
    0
  ],
  "module_selection_source": "automatic",
  "target_mode": "FULL",
  "target_hz": 200,
  "delta_threshold": 8,
  "spi_setting_hz": 10000000,
  "condition": "zero_load",
  "block": "1",
  "repeat": "3",
  "operator": "",
  "load_protocol_id": "",
  "load_layers": "unspecified",
  "load_notes": "",
  "notes": "",
  "deployment_note": "",
  "deployment_confirmed": false,
  "board_identity_handling": "slots_only",
  "physical_modules_to_slots": {},
  "board_identity_source": "unknown_not_transmitted_by_protocol",
  "target_hz_source": "GUI default 200 Hz; not firmware readback",
  "module_detection_at_record": {
    "source": "recent_successful_protocol_slots_not_board_uids",
    "ready": true,
    "modules": [
      0
    ],
    "mode": "FULL",
    "slot_modes": {
      "0": "FULL"
    },
    "slot_last_success_monotonic": {
      "0": 185771.8387738
    },
    "last_packet_monotonic": 185771.8387738,
    "observed_at_monotonic": 185771.8387738,
    "window_span_seconds": 1.499573600012809,
    "window_seconds": 1.5,
    "stale_seconds": 0.5,
    "packet_count": 301,
    "limitation": "No response cannot establish whether a board is physically attached. The recent union can retain a briefly missing slot; recording freezes the set."
  },
  "observed_mode_at_record": "FULL",
  "observed_mul1_rate_at_record_Hz": 200.08132658732444,
  "spi_setting_source": "local firmware configuration; not measured or read back",
  "delta_threshold_source": "local firmware configuration; not measured or read back",
  "module_identity_source": "CS/IRQ slot; protocol carries no unique board identity",
  "N": 1,
  "M": 4,
  "local_provenance": {
    "source": "local_files_not_device_flash_readback",
    "firmware_variant": "four-module-variable-spi",
    "files": {
      "stm32_elf": {
        "path": "D:\\study\\programming\\ESKIN\\E-SKIN\\hardware\\new\\firmware\\active\\four-module-variable-spi\\stm32\\combined-system\\build\\Release\\ESKIN_STM32.elf",
        "sha256": "8fb1791504f3c2bf23dce9d57ca9b877b8cd1653d167dfe5a58b0c5176c4c8b6"
      },
      "teensy_hex": {
        "path": "D:\\study\\programming\\ESKIN\\E-SKIN\\hardware\\new\\firmware\\active\\four-module-variable-spi\\build\\teensy\\four_module.ino.hex",
        "sha256": "32a95ff60bef1029a8b25a62d4ece524abc97813955e6586fc50fc9bf4cd2a67"
      },
      "pc_monitor": {
        "path": "D:\\study\\programming\\ESKIN\\E-SKIN\\hardware\\new\\firmware\\active\\four-module-variable-spi\\pc\\four-module-fsr-monitor.py",
        "sha256": "f3cb2910054e26300a223cbac611e08eb4eae6ac6fa2a60ebd3c414695758949"
      },
      "pc_recorder": {
        "path": "D:\\study\\programming\\ESKIN\\E-SKIN\\hardware\\new\\firmware\\active\\four-module-variable-spi\\pc\\experiment_recording.py",
        "sha256": "aff5787daa91bdb16719b0601d71707307e9d3471f636192cc5308445bf1b9ed"
      },
      "pc_controls": {
        "path": "D:\\study\\programming\\ESKIN\\E-SKIN\\hardware\\new\\firmware\\active\\four-module-variable-spi\\pc\\experiment_controls.py",
        "sha256": "9e7ff3b5678de04c46dbf9653385e7dbac9a8ec59f95737122020de50299b194"
      },
      "pc_module_detection": {
        "path": "D:\\study\\programming\\ESKIN\\E-SKIN\\hardware\\new\\firmware\\active\\four-module-variable-spi\\pc\\module_detection.py",
        "sha256": "52e35e8991c13e70e8f1e64d7b32d6b25bfa0fa7aeda8ec2333033540eb59ec1"
      }
    }
  },
  "batch_id": "BATCH_a3da6b70a7684d359fd18d817b963390",
  "batch_repeat_index": 3,
  "batch_repeat_count": 3,
  "batch_recording_method": "consecutive_capture_windows_same_setup",
  "batch_interpretation": "Temporal repeats under one setup; not independent setup blocks or automatic reloading",
  "batch_initial_observations": "GUI at_record fields describe the initial batch request; each run measures its own statistics",
  "module_detection_at_repeat_start": {
    "source": "recent_successful_protocol_slots_not_board_uids",
    "ready": true,
    "modules": [
      0
    ],
    "mode": "FULL",
    "slot_modes": {
      "0": "FULL"
    },
    "slot_last_success_monotonic": {
      "0": 185851.8871737
    },
    "last_packet_monotonic": 185851.8871737,
    "observed_at_monotonic": 185851.9384681,
    "window_span_seconds": 1.4338678999920376,
    "window_seconds": 1.5,
    "stale_seconds": 0.5,
    "packet_count": 291,
    "limitation": "No response cannot establish whether a board is physically attached. The recent union can retain a briefly missing slot; recording freezes the set."
  },
  "pre_record_commands": [],
  "stream_start_offset": 19977517,
  "live_parser_buffer_bytes_at_start": 1,
  "live_parser_continuous_across_recordings": true,
  "module_count": 1,
  "algorithm": "FULL",
  "modules": [
    "M0"
  ],
  "active_module_ids": [
    "M0"
  ],
  "scan_hz": 200,
  "target_scan_rate_hz": 200,
  "load_label": "zero_load"
}
```
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

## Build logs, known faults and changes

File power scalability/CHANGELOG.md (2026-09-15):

## 2026-09-13 - DATA reclassification and portable paths

- Split `DATA/` into `raw/canonical`, `raw/intake`, `analysis/current`, `analysis/retest_reviews`, `analysis/provenance`, `reference` and `archive` so raw evidence is separate from derived outputs and historical snapshots.
- Updated analysis scripts, manifests, generated documentation and package READMEs to use repository-relative paths. Refreshed JSON validity and SHA-256 fields for files whose paths or metadata changed.
- Raw measurements, photographs, report artwork and the final report PDF were not regenerated or edited. The two validation suites continue to pass.
# Power Scalability Changelog

## 2026-09-07 - Report Version 2.8, latest M0 retests and signed drop panels

- Added the five latest M0 current/voltage retests: N=1 ZERO/MAX and every N=2
  ZERO combination containing M0. Together with the earlier N=3 M0 and M3
  updates, the selected analysis contains seven targeted branch updates but no
  new complete configuration repeats.
- Selected M0 values are 18.018 mA and 3.252 V at N=1 ZERO, 19.675 mA and
  3.249 V at N=1 MAX, and N=2 ZERO branch currents 17.941/17.969/17.956 mA
  with module voltages 3.251/3.251/3.250 V. The user-confirmed M0-M1 voltage
  replaces a misassigned photograph; the excluded assignment remains recorded.
- Recomputed the N summaries. ZERO current means are 18.290, 36.253, 54.426
  and 72.513 mA for N=1--4; recorded MAX means are 20.006, 39.629, 58.849
  and 78.720 mA. N=1--3 SDs describe different configurations, and N=4 remains
  n=1. Current-prediction residuals span -1.483 to -0.256% at ZERO and
  -2.726 to +0.460% at MAX.
- Removed the mean heatmap from the report. The new combination heatmap shows
  ZERO, MAX and signed MAX-minus-ZERO change, with adaptive 25--40 mV absolute
  scaling and a symmetric -10 to +10 mV difference scale. Of 32 paired module
  cells, 21 increase, six decrease and five are unchanged.
- Frozen analysis tables are in DATA/analysis/current/report_v2_8_analysis and formal figure
  exports in DATA/analysis/current/report_v2_8_figures. Eight report figures were exported in
  vector and raster formats; figure inputs, scripts and hashes are recorded.
- Updated the report's Power methods, results, discussion, appendix, abstract,
  conclusion and claim/evidence mapping. Accepted DMM minima are 3.240 V at
  ZERO and 3.236 V at MAX. Historical readings, source values, temperatures
  and unmodified branches keep their earlier provenance.
- The 72-page Version 2.8 PDF compiled without reportable LaTeX warnings, and
  all Power result/discussion/appendix pages were visually reviewed. Loading
  distribution, repeatability, simultaneous total current, verified monitoring,
  startup peaks, ripple, switching response and thermal rise remain unresolved.

## 2026-09-07 - Version 2.4, targeted Power retests and module-count figures

- Archived the complete live 2.3 source/PDF/checklist before editing under
  report_versions/v2.3/before_power_2.4_20260907_055110. Old PDF releases,
  acquisitions and derived 2.3 analyses remain unchanged.
- Selected the M0-M1-M2 ZERO M0 current retest (18.051 mA); retained its
  previously accepted 3.241 V. Selected M1-M2-M3 MAX M3 current 19.263 mA
  and voltage 3.243 V, with SOURCE 3.276 V confirmed unchanged: 33 mV,
  compared with the earlier 44 mV. Old measurements remain documented.
- Compiled sums are 54.564 and 59.159 mA for these two conditions. Other
  branches, temperatures and source extrema keep their earlier provenance.
  The 30 condition entries and 64 selected branches do not become 32 runs;
  no complete configuration repeat or simultaneous sum is claimed.
- Updated Power methods, results, discussion, appendix, abstract and conclusion.
  Revised N3 means/SD, included a before/after table, regenerated seven
  figures, and added the module-count mean heatmap plus N1-N4 four-panel
  figure. Four separate N figures are also exported (13 figures in total).
  M3 MAX N3 differences are 32,32,33 mV: mean 32.33, sample SD 0.58 mV.
- SD describes configuration spread, not repeatability. All five historical
  MIN/MAX inconsistencies remain in the baseline; four remain in the selected
  view. Retest loading equivalence and the cause of the M3 change are unresolved.
- Updated the same Word/Markdown checklist: 20/60 checked, P05 partial.
  Dynamic supply/thermal tests remain future work. Checked 179 source hashes,
  561 protected Power files, 118 unrelated report assets, 30 condition entries,
  64 branches and 110 group rows. Shared non-Power text is unchanged.
- Final PDF: 64 pages, stable references, no missing glyphs, undefined references
  or overfull boxes. All pages rendered and reviewed; repaired one long appendix
  paragraph and brought the supplementary heading onto its first figure page.
  Version hashes, source/data/figure archives and checklist snapshot are in
  report_versions/v2.4/manifest.json. Human scientific verification remains pending.

## 2026-09-07 - M3 retest source unchanged; drop estimate 33 mV

- User confirms SOURCE is unchanged for M1-M2-M3/MAX/M3. Retained original
  source main 3.276 V is now an explicit user-confirmed reference.
- Calculated 33 mV from 3.276-3.243 V, versus original 44 mV (-11 mV).
  The source/reference and retest module photo are distinct records; no
  new source extrema, simultaneous capture or full-configuration repeat is inferred.
- Updated record revision 4, readings/comparison CSVs and notes; archived
  previous versions. Connector reinsertion remains recorded; a causal fault
  diagnosis is not asserted. Existing full-matrix figures/report remain retained.

## 2026-09-07 - Targeted M0-M1-M2 ZERO M0 current retest

- Preserved the user's current photo and independently transcribed M0
  main/MIN/MAX 18.051/18.00/18.08 mA. User confirms voltage remains 3.241 V;
  its new MIN/MAX are not supplied and stay null.
- Current increased 0.083 mA from the original 17.968 mA. New main current is
  inside its display extrema; the historical main/MIN mismatch is retained.
  Linked the prior confirmed M0 contact-fault event and separate voltage retest.
- This supplies a later M0 current observation, not a new complete N3 run.
  No new SOURCE/M1/M2 values, summed current, repeat SD or fault-free result
  is inferred. Preserved original data, complete matrix, M3 retest and report.
  Saved intake and comparison under DATA/analysis/retest_reviews/m0_zero_retest_20260907/.

## 2026-09-07 - Retest SOURCE clarified as unmeasured

- User clarifies that 3.243/3.243/3.244 V are the photographed M3 module
  values; SOURCE has not been remeasured. Resolved the candidate's identity,
  retained the clarification history and kept retest SOURCE/drop null.
- Connector reinsertion remains confirmed; the original and new module
  readings are separate. No source value, complete run, repeat SD or
  retrospective fault diagnosis is fabricated; report/figures stay unchanged.

## 2026-09-07 - M3 retest connector clarification

- User confirms M3 connector reinsertion before the retest; no cable
  replacement, matched load or causal fault diagnosis is inferred.
- The response to the SOURCE question repeats 3.243/3.243/3.244 V,
  identical to the M3 photo. Saved it as a pending measurement-point
  candidate and requested clarification; new drop stays null, not 0 mV.
- Archived the pre-clarification record and notes, updated targeted-retest
  provenance only. Original readings, full matrix and report remain retained.

## 2026-09-07 - Targeted M1-M2-M3 MAX M3 retest

- Saved the user's two unmodified photographs and a separate targeted-retest
  record: M3 V main/MIN/MAX 3.243/3.243/3.244 V; I 19.263/19.25/19.41 mA.
  Direct visual transcription was independently checked.
- Compared with original M3 3.232 V and 19.721 mA: +11 mV and -0.458 mA.
  Retest source voltage and setup/connector/load changes remain unconfirmed,
  so new drop and fault cause are not inferred. Original 44 mV is retained.
- This is one module observation set, not a complete three-module repeated run.
  Original data, 30-condition matrix, existing figures and report 2.3 remain
  unchanged. Intake and comparison are in DATA/analysis/retest_reviews/m3_max_retest_20260907/.

## 2026-09-07 - Supplementary voltage-drop means by module count

- Added DATA/analysis/current/voltage_drop_by_N_20260907 and script/Main/figures/power_drop_by_count.py.
  Six figures (mean heatmap, four-panel raw-point/mean/SD plot, four separate
  N plots) are available as PNG/PDF/SVG, with 32 summary groups and all 64
  contributing branch observations and provenance.
- Per-module n is 1/3/3/1 at N=1/2/3/4. SD describes combinations, not repeated
  trials; n=1 SD is absent. ZERO N3 M0 keeps the marked cross-record retest
  estimate. MAX N3 M3 retains 32/32/44 mV, mean 36.00 and sample SD 6.93 mV.
- Verified 158 source hashes, statistics, export dimensions/fonts and visual
  layout. Mean plots supplement the full combination heatmap; no raw input,
  existing report figure, main 2.3 PDF or version archive was modified.

## 2026-09-07 - Report Version 2.3 published

- Integrated 15 combinations per ZERO/MAX label (30 conditions, 64 branches)
  into the Version 2.2 baseline; updated seven Power figures and the methods,
  results, discussion, appendix, abstract, conclusion and system interpretation.
- Configuration SD and n=4/6/4/1 remain distinct from repeatability; every
  exact condition has one observation. Loading and monitoring gaps, five
  current-reading flags and the M0 connector fault/retest remain documented.
- Preserved raw records, frozen analyses and older PDFs. The before-edit
  source/PDF/checklist archive is in report_versions/v2.2; the new 61-page
  report and release hashes are in main 2.3.pdf and report_versions/v2.3
  at the Final directory. The same Word checklist is updated, P05 partly
  complete and unchecked. Dynamic power/thermal validation is future work.

## 2026-09-07 - Completed N=3 MAX and summarized the full Power matrix

- Added `current_temperature_supplements/n3_max_20260907.csv` and metadata for
  M0-M1-M3 and M0-M2-M3: fourteen photos (six current, eight voltage) provide
  all main/MIN/MAX readings. Recorded the user's temperatures in module-ID
  order, Teensy, regulator: 27.4/27.3/26.9/42.6/30.0 and
  27.2/26.8/26.6/42.6/29.6 degC. Prior ZERO temperatures remain unchanged.
- Branch main-current sums are 58.631 and 58.279 mA, each with a 3.275 V
  source. Output-side estimates are 192.016525 and 190.863725 mW. The clear
  photographed M0-M1-M3 M3 current 19.178 mA is retained without adjustment.
  MAX follows the ongoing full-load completion task; mass/area/distribution,
  actual timing and fault counts are unknown. No simultaneous reading or
  time average is inferred, and SOURCE labels retain their order-based basis.
- Added `summarize_all_power_20260907.py` and `DATA/analysis/current/all_power_review_20260907/`:
  fifteen physical configurations each with ZERO/MAX observations, thirty
  configuration/load conditions and sixty-four module branches. Provides
  complete voltage/current/temperature tables, per-N and filename-batch
  descriptive statistics, matching-combination load differences, independent
  N=1-reference prediction checks, quality notes and source hashes. Historical
  blocked-standby records remain separate and are not counted as new repeats.
- N=3 MAX current is 58.96375 +/- 0.616176044 mA; power estimate is
  193.1360175 +/- 2.050760870 mW. SD is across the four different configurations,
  not repeat SD. Each configuration/load condition remains n=1; N=4 SD is null.
  Across all fifteen configurations MAX current exceeds ZERO by 7.664881% to
  10.972901%, interpreted descriptively given dates and incomplete load definitions.
- Current coverage views now report ZERO 15/15 and MAX 15/15. Previous ZERO
  and N=2 MAX numeric summaries are preserved; prior coverage outputs/scripts
  are archived under `DATA/analysis/current/all_power_review_20260907_history/before_n3_max_coverage/`.
  Updated current overviews, record guidance, revision notes and experiment log.
- Original measurement YAMLs, previous supplements, M0-only voltage repair,
  frozen analysis_v2_1 and main 2.1 PDF remain unchanged. Startup peaks, ripple,
  load-switching waveforms and continuous thermal curves remain future work.
- Validation: all fourteen new photos and six supplement rows checked; independent
  QA matched 448 branch numeric fields across 64 branches and recomputed all
  110 group-statistic rows. All configuration sums and voltage/current products
  agree. Source hashes, original 19 frozen inputs and report PDF were verified.
  The eight prior ZERO/N2 MAX measurement CSVs remain byte-identical; only
  coverage/provenance descriptions changed. All 23 existing tests passed. Five
  historical ZERO main-versus-MIN/MAX inconsistencies remain flagged unchanged.

## 2026-09-07 - Completed all N=2 MAX pairs; recorded voltage, current and temperature

- Added `current_temperature_supplements/n2_max_20260907.csv` and metadata for
  M0-M2, M0-M3, M1-M2 and M1-M3. The user explicitly confirmed MAX/full load.
  Twenty photographs supply all main/MIN/MAX values for eight branch-current,
  eight module-voltage and four source-voltage observations. Recorded sixteen
  user-supplied temperature points in ascending module order, Teensy, regulator;
  normalized the final supplied `29,2` to 29.2 degC.
- Preserved photographed main-current precision: M1-M2 M1 is 19.99 mA and
  M1-M3 M1 is 20.32 mA. New branch sums are 39.357, 39.335, 39.719 and
  40.016 mA; corresponding output-side estimates are 129.012246, 128.940130,
  130.159163 and 131.132432 mW. Neither sums nor power products are simultaneous
  measurements; no repeated observations or time averages are inferred.
- Added `summarize_n2_max_20260907.py` and `DATA/analysis/current/n2_max_review_20260907/` to
  combine all six MAX pairs, compare the matching ZERO configurations and
  retain dated-batch statistics and per-source provenance. MAX current is
  39.629 +/- 0.315 mA; estimated output power is 129.891 +/- 1.020 mW.
  These are sample SDs across six different configurations, not repeat SDs.
  Each condition has one record per configuration. Load comparisons are
  descriptive; new MAX mass/area/distribution are unspecified and date effects
  cannot be separated from configuration effects.
- Updated current coverage: N=2 ZERO and MAX each 6/6; overall ZERO 15/15 and
  MAX 13/15. Only M0-M1-M3 and M0-M2-M3 lack MAX records. Dynamic/thermal
  curves remain future work. Prior ZERO values, connector correction, original
  YAMLs/CSV inputs, frozen analysis_v2_1 and published main 2.1 remain unchanged.
- Repaired references after twenty historical N=2 ZERO photos moved into each
  pair's `zero_load` folder. All hashes match the earlier source manifest.
  `photo_source_paths.py` accepts only registered exact relocations and checks
  hashes; current outputs retain actual and original paths. Stored the migration
  manifest and prior scripts/derived files in `DATA/analysis/provenance/path_relocation_20260907/`.
  The raw historical references remain intact; no new MAX photo is substituted.
- Subsequently resolved fourteen moved N=3 ZERO photographs (eight voltage,
  six current) by the same recorded-hash rule: 34 relocations in total.
  Refreshed the ZERO coverage view to 13/15 MAX without changing any ZERO
  numerical result; linked the latest N=2 MAX review. The earlier YAML-only
  voltage view has its narrower scope documented separately.
- Validation: independent photo/temperature and Decimal arithmetic checks
  agree with the new supplement and six-pair summary. All 23 existing tests
  passed. The original 19 frozen inputs and published PDF hashes still match;
  migration checks preserve all ZERO measurements and the connector correction.

## 2026-09-07 - Added N=3 ZERO currents and temperatures; completed main-reading coverage

- Added six photographed branch currents for M0-M1-M3 and M0-M2-M3, linked
  to the existing voltage-only records. Main currents are respectively
  18.005/18.110/18.044 mA and 17.993/18.069/18.068 mA in module-ID order.
  Main sums are 54.159 and 54.130 mA; source-output estimates are
  177.479043 and 177.329880 mW using the earlier corresponding source voltage.
- Recorded the user's five temperatures per combination: M0-M1-M3
  27.4/26.7/26.9/42.7/29.6 degC; M0-M2-M3 27.4/26.6/26.6/42.6/29.2 degC.
  Order is three STM32 points in ascending module ID, Teensy, regulator.
- Created the combined `DATA/analysis/current/zero_power_review_20260907/` with all 15 ZERO
  configurations and 32 module branches, per-source provenance, N-specific
  and filename-date-batch statistics, plus a four-combination N=3 table.
  N=3 mean +/- sample SD is 54.405 +/- 0.337 mA and 178.245 +/- 1.091 mW.
  These are descriptive differences between configurations, not repeat SD.
- The M0-M1-M3 M0 photo's decoded lower portion does not expose MIN. The user
  subsequently confirmed MIN 18.00 mA during this intake; provenance identifies
  that confirmation separately from photograph-read main 18.005 mA and MAX
  18.03 mA. All 32 ZERO branches now have main/MIN/MAX values; original
  main-versus-extrema inconsistencies elsewhere remain flagged unchanged.
- Preserve all original YAMLs/photos, the historical M0-M1-M2 current and
  temperature readings, the M0-only voltage correction and connector event.
  The six supplemented configurations use separate current/voltage records;
  no simultaneous measurement, additional repeat or zero-fault result is inferred.
- MAX remains 9/15 configurations. Startup peaks, ripple, load-switching
  waveforms and continuous thermal curves remain future work as requested.
  Data notes/log updated; report PDF and frozen analysis_v2_1 are unchanged.
- Validation: six new branch readings and temperatures match the photographs
  and user values; both confirmed MIN values retain explicit provenance.
  Independent arithmetic agrees for the four N=3 configurations and all N-level
  current means/SD. Verified all 68 analysis-source hashes, the original 19
  frozen inputs and unchanged PDF; 189 protected files were unchanged during
  generation. Five historical main/MIN/MAX inconsistencies remain flagged;
  the six new branches have no such inconsistency. Existing N=2 values agree.

## 2026-09-07 - Deferred dynamic and thermal curves to future work

- Following the user's explicit scope decision, classify startup peak current,
  supply ripple, load-switching waveforms and continuous temperature-rise curves
  as future work, outside this round's required Power data completion. Mark
  them unvalidated rather than completed; existing point readings remain usable
  within their stated scope.
- Clarified incomplete fault-monitoring evidence: historical default-zero
  counters lack a verified observation method/window or event log. This alone
  establishes neither a fault nor its absence. Distinguish observed absence,
  unmonitored events and documented faults; retain the M0 connector event.
- Updated the measurement-plan scope, revision/future-work notes, record
  guidance and experiment log. No raw measurements, statistics, checklist
  completion marks or published report PDFs were changed.

## 2026-09-07 - User confirmed M0-M3 M3 minimum current

- Filled the previously unreadable M0-M3 M3 MIN with the user's 17.89 mA
  confirmation. Main 17.922 mA and MAX 18.05 mA are unchanged. Photo glare
  remains, so provenance is user confirmation rather than visual transcription.
- Regenerated branch/QC coverage and source hashes: all 12 N=2 ZERO branches
  now have main/MIN/MAX values. The separate old M0-M1 M1 main/MIN mismatch
  remains flagged. All current sums, power estimates and aggregate statistics
  are unchanged; no extra measurement repetition is counted.
- Updated the supplement, metadata, analysis script and current documentation.
  Preserved the previous eight input/derived/code files under
  `DATA/analysis/current/n2_zero_review_20260907/history/before_user_MIN_confirmation/`.
  This supersedes the missing-MIN status in the earlier entry below.
  Published report 2.1 and original photographs/YAMLs remain unchanged.

## 2026-09-07 - Completed N=2 ZERO current and temperature coverage

- Transcribed eight new DC-current photographs for M0-M2, M0-M3, M1-M2 and
  M1-M3, assigning branches in the user-confirmed ascending module order.
  Used the latest temperature message: regulator readings are respectively
  29.3, 29.2, 29.1 and 28.8 degC. The earlier incomplete message is superseded.
- Added `DATA/raw/canonical/power_experiment_records/current_temperature_supplements/`
  with a CSV and source/condition metadata. Link these later measurements to
  the existing voltage-only configurations without rewriting their raw YAMLs
  or counting voltage/current acquisitions as independent complete-run repeats.
- Added `script/Main/pipeline/summarize_n2_zero_20260907.py` and the six-configuration,
  twelve-branch review in `DATA/analysis/current/n2_zero_review_20260907/`. Branch-current sums
  span 35.907-36.561 mA; across-combination mean +/- sample SD is
  36.263 +/- 0.265 mA (CV 0.731%). Source-output power estimates are
  118.907 +/- 0.848 mW. Four estimates use earlier source-voltage readings;
  they are labelled cross-record estimates and exclude Teensy/regulator losses.
- Corresponding N=1 reference predictions give residuals -1.786% to -0.595%.
  Six configurations share four modules and two filename-date batches; this
  descriptive SD is not within-condition repeatability. Each pair has one
  recorded current observation per branch. Batch-specific statistics are retained.
- M0-M3 M3 current MIN is unreadable under glare and remains null. Main
  17.922 mA and MAX 18.05 mA are retained. The pre-existing M0-M1 M1 main
  18.055 mA versus MIN 18.06 mA mismatch is flagged without changing either.
- Recorded temperature ranges: module STM32 26.3-27.3 degC, Teensy
  42.5-43.1 degC, regulator 28.8-29.3 degC. These are point readings with
  no verified ambient temperature or thermal settling time.
- Generated per-source SHA256 provenance and verified 177 protected existing
  files unchanged during analysis. Published main 2.1, frozen analysis_v2_1,
  original voltage/current YAMLs and all photographs remain unchanged.
- Validation: all 23 existing power/voltage review tests passed; independent
  arithmetic agrees for six current sums, six power estimates and descriptive
  statistics. Verified all 32 new-analysis sources and 19 frozen original
  source hashes, the missing M3 MIN, and unavailable repeat SD fields.

## 2026-09-07 - Clarified that only the M0 connector was affected

- The user confirmed SOURCE/M1/M2 voltage points were unaffected and retain
  their original values. Revised the event to scope the fault to the original
  M0 voltage point only; the earlier whole-run exclusion was an over-broad
  interpretation and is superseded by this clarification.
- Accept the corrected M0-M1-M2 ZERO voltage configuration as SOURCE 3.276 V,
  M0 3.241 V from the retest, M1 3.250 V and M2 3.246 V from the original
  record. Preserve all raw values and per-point provenance. This is one
  corrected configuration, not a new simultaneous acquisition or extra repeat.
- Retain the old M0 3.224 V / 52 mV difference as fault history. The corrected
  M0 difference is estimated as 35 mV using the user-confirmed unchanged source;
  label this separately from differences measured within one record. The raw
  retest source remains null. No current or temperature values were invented.
- Accepted ZERO voltage coverage is 15/15 subsets (4+6+4+1), consisting of
  14 complete original configurations and one pointwise-corrected configuration.
  Raw review retains 51 module points, excludes only old M0, and accepts the
  other 50 points. The previous 14-complete/1-partial conclusion no longer
  describes accepted configuration coverage.
- Archived the previous event, manifest, review and code under
  `DATA/raw/intake/voltage_additions_20260907/history/before_M0_only_scope_clarification/`.
  Updated the event, voltage review and current explanatory notes; published
  main 2.1, its frozen analysis, all original YAMLs and photographs are unchanged.
- Validation: eleven updated voltage-review tests and twelve historical-analysis
  tests passed. Intake replay preserved the clarification byte-for-byte. The
  corrected four-point configuration and 15/15 ZERO coverage were independently
  inspected; original record/photo and published PDF hashes remain unchanged.

## 2026-09-07 - Added N=3 ZERO combinations and recorded a supply-contact fault

The whole-run exclusion and partial-coverage interpretation in this earlier
entry are superseded by the subsequent M0-only clarification above.

- Transcribed source and three module voltages for M0+M1+M3 and M0+M2+M3,
  keeping main/MIN/MAX values and per-photo provenance. Added a separate
  M0-only retest in the M0+M1+M2 configuration: main/MIN/MAX all 3.241 V.
  Three new VOLTAGE_ONLY YAMLs cover nine photographed points. Unknown
  source voltage for the partial retest, currents, temperatures and timing
  remain null; no old source voltage is reused to calculate a repaired drop.
- The user explicitly identified the earlier 3.224 V M0 reading as a supply
  wire/connector contact issue. It is an actual abnormal supply condition,
  not a probe/instrument measurement error. Preserved the original run and
  recorded the cause, hashes and retest relationship in
  `DATA/raw/canonical/power_experiment_records/quality_events/supply_contact_M0_20260907.json`.
- The original affected run is separated from summaries of connections without
  a reported contact fault. The repair retest measures only M0; original
  source/M1/M2 voltages and currents are not revalidated after repair. Fault
  and repaired readings are not pooled as equivalent-condition repetitions.
- Added a batch summary in `DATA/raw/intake/voltage_additions_20260907/` and a separate
  voltage review in `DATA/analysis/current/voltage_review_20260907/`. All four N=3 ZERO subsets
  have historical coverage, but M0+M1+M2 has only a partial post-repair voltage
  record; it is not a complete new normal-connection run.
- The historical Power 2.1 reproducer skips seven voltage-only supplements,
  discloses the subsequent contact event and warns against interpreting its
  unfiltered old tables as a current normal-connection analysis. The published
  PDF and `DATA/reference/analysis_v2_1/` remain unchanged pending report integration.
- Voltage review preserves 25 runs / 51 module points, classifying three points
  from the known fault run separately. The remaining 48 points have recorded
  minima of 3.234 V at ZERO and 3.231 V at MAX/overall; these are not transient
  bounds or proof that no other fault occurred. The old 3.224 V / 52 mV drop
  remains in historical/fault output. The old 89 mV value is headroom above
  3.135 V, not voltage drop.
- Validation: twelve historical-analysis checks and nine voltage-review checks
  passed. Independent photo/record review and input/output hash checks verified
  the new records, preserved old readings and unchanged published PDF.

## 2026-09-06 - Added four ZERO voltage-only two-module combinations

- Transcribed twelve photographs for M0+M2, M0+M3, M1+M2 and M1+M3:
  four source-voltage points and eight module-voltage points. The user
  confirmed ascending module order. The first photograph in each group is
  assigned to the source using the established sequence; this assignment is
  explicitly marked as inferred because the probe endpoint is not identifiable.
- Added one `zero_load/*VOLTAGE_R1.yaml` per combination with photo mappings,
  hashes and `measurement_scope: VOLTAGE_ONLY`. Main, MIN and MAX readings
  remain separate; unknown currents, temperatures, timing and fault counts
  are null. Capture-filename dates are kept separate from experiment times.
- Added `DATA/raw/intake/voltage_additions_20260906/` with the twelve-point CSV, source
  manifest and Chinese summary. ZERO voltage coverage for N=2 is now six
  combinations out of six, across the original and new record batches.
  Loaded coverage and repeat counts have not increased.
- The combined voltage/current analysis now explicitly excludes VOLTAGE_ONLY
  supplements and records their paths. Missing current in an unmarked record
  remains an error. Published report 2.1 and its derived outputs are unchanged;
  the voltage supplement has not yet been incorporated into report figures.
- Validation: all eleven combined-analysis regression checks passed; an
  independent transcription review matched all four YAML/CSV records. SHA-256
  checks passed for the four new YAMLs and twelve source photographs, and the
  published 2.1 PDF and its analysis source manifest remain unchanged.

## 2026-09-06 - Report 2.1 analysis of existing continuous-read records

- Added `analyze_power_revision.py` and `DATA/reference/analysis_v2_1/` for 18 FULL,
  configured-200-Hz continuous-USB records and 13 separately grouped legacy
  blocked-standby records. Eleven standby YAML mappings are duplicates, not
  additional experiments. Raw inputs and `DATA/analysis/` remain unchanged.
- Correctly mapped the N=1 module0 measurement columns to the recorded
  module label; retained each multi-module subset and each load condition.
- Added independent-single-module predictions, paired load differences,
  provenance and explicit QC flags. N=4 ZERO/MAX totals are 72.513/78.720 mA;
  minimum continuous-read module MIN is 3.224 V. Five minor representative
  current versus MIN/MAX inconsistencies were flagged without changing values.
- Regenerated seven report figures using the new analysis, with individual
  combinations and load states visible. No repeat SD is inferred from DMM
  ranges or differences between module combinations. Nine regression checks
  passed and all 21 PDF/PNG/SVG exports have recorded hashes.
- Updated the main report to Version 2.1 and the original Word checklist in
  place. Added `POWER_REVISION_2.1_CN.md` with evidence limits and future work.
  Revised P-H1 is a descriptive cross-configuration prediction check; P-H2
  concerns recorded voltage readings. Neither establishes fault-free operation,
  a worst-case load, thermal equilibrium or verified supply capacity.
- Archived the pre-revision report, checklist and Power support files under
  `../report_versions/v2.0/before_power_2.1_resumed_20260906_215540/`.
  This is an analysis/documentation revision, not a new experiment date.

## 2026-09-05 - Completed N=3 zero-load record transcription

- Transcribed source voltage, module voltages and branch currents from the
  photographs in module-number test order for M0-M1-M2 and M1-M2-M3.
- Retained the STM32, regulator and Teensy temperatures supplied separately.
- Marked the two zero-load records as `MEASURED` with `INCOMPLETE` quality;
  full-load records and unsupported metadata remain blank.
- Preserved the displayed values where the main reading and MAX/MIN differ
  slightly because of display precision.

## 2026-09-05 - Added N=2 M2-M3 temperature records

- Added the M2/M3 STM32 temperatures and the Teensy and regulator temperatures
  for the zero-load and full-load records.
- Marked both records as `MEASURED` with `INCOMPLETE` quality because the
  corresponding voltage, current and full-load metadata are not available.

## 2026-09-05 - Completed N=2 M0-M1 transmission record transcription

- Assigned the earlier photographs to M0 and the later photographs to M1.
- Transcribed source voltage, both module voltages and both branch-current readings
  for the zero-load and full-load records.
- Added the STM32, regulator and Teensy temperatures supplied in the desktop note.
- Marked both records as `MEASURED` with `INCOMPLETE` quality because full-load
  metadata and other run metadata remain unavailable.
- Preserved the displayed Zero-load M1 current values, including the 18.055 mA
  main reading and 18.06 mA displayed minimum; the 0.005 mA difference is a
  display-precision effect.

## 2026-09-05 - Completed N=1 transmission record transcription

- Transcribed the new M1/M2 voltage readings from the experiment photographs.
- Transcribed STM32, regulator and Teensy temperatures for the M1, M2 and M3
  zero-load/full-load records from the desktop measurement note.
- Marked the six updated records as `MEASURED` with `INCOMPLETE` quality because
  optional load metadata and run metadata remain unavailable.
- Kept the canonical `power_raw.csv` unchanged; continuous-USB records are not
  mixed into the legacy blocked-standby analysis until the analysis grouping is
  updated.

## 2026-09-04 - Set default fault counters in experiment templates

- Set `reset_count`, `current_limit_count`, `brownout_count`, `data_stop_count`,
  `data_gap_count` and `other_fault` to `0` in all 36 concrete run templates.
- Kept the completely blank master template unchanged; observed events should
  replace the relevant default count.

## 2026-09-04 - Set default run timing in experiment templates

- Set all 36 concrete run templates to `warmup_duration_s: 30` and
  `measurement_duration_s: 10`.
- Kept the completely blank master template unchanged.

## 2026-09-04 - Added structured Power experiment record templates

- Created `DATA/raw/canonical/power_experiment_records/` with a complete blank template and
  36 pre-parameterised run templates.
- Organised templates as `transmission` and `no_transmission`, then `n=1`--`4`,
  module combinations, and `zero_load`/`full_load` folders.
- Pre-filled only fixed run conditions; direct measurements and observations
  remain blank, while derived quantities are intentionally omitted for script
  calculation.

## 2026-09-04 - Marked existing Power records as blocked standby

- Added `host_usb_polling_state` to `DATA/raw/canonical/power_raw.csv` and marked all 13
  existing records as `BLOCKED_STANDBY_NO_CONTINUOUS_USB_READ`.
- Reserved `CONTINUOUS_USB_READ` for the new measurements with continuous USB
  consumption; all measured values remain unchanged.

## 2026-09-04 - Removed the rawdata archive on request

- Deleted `DATA/rawdata/`, including the M3 diagnostic record, the unfilled
  M1+M2+M3 template and the legacy N=4 CSV backup.
- Preserved `DATA/raw/canonical/power_raw.csv`, all derived analysis and current figures.

## 2026-09-04 - Documented host-side USB polling states in the report Method

- Added the closed-GUI and open-but-idle GUI states to the Method measurement
  boundary for 200 Hz FULL power measurements.
- Recorded that GUI state affects host polling and communication continuity,
  while the Teensy remains USB-powered and module current is measured only on
  the external 3.3 V branch.
- No power source data or Result text was changed.

## 2026-09-04 - Corrected N=1 Module 3 voltage record

- Corrected `PS01_N1_F200_ZERO_M3_R1` in `DATA/raw/canonical/power_raw.csv` to
  `V_module_avg=3.265 V`, `V_module_min=3.264 V` and `V_module_max=3.266 V`.
- Regenerated the derived Power analysis and figures; no current, temperature,
  fault or other module values were changed.

## 2026-09-04 - Added N=3 M1+M2+M3 steady-state record

- Added `PS01_N3_F200_ZERO_M1_M2_M3_R1` to `DATA/raw/canonical/power_raw.csv` using the
  supplied voltage and branch-current measurements.
- Recorded source average current as the sum of all three branch averages:
  `8.359 + 8.790 + 7.761 = 24.910 mA`; the unsynchronised minimum and maximum
  estimates are `24.470 mA` and `46.450 mA`.
- Set unreported fault counters to zero. Temperature fields use the original
  M1/M2/M3 reference records and are labelled as non-simultaneous inherited
  values; the run remains `INCOMPLETE` because timing and source-current
  extrema were not supplied.
- Regenerated the derived analysis and figures so the N=3 summary now includes
  both M0+M1+M2 and M1+M2+M3 combinations; report text was left unchanged.

## 2026-09-04 - Rescaled Figure 4.6 to the measured range

- Changed Figure 4.6's colour scale from a fixed `0-60 mV` range to the
  observed minimum-to-maximum voltage-drop range (`10-53 mV` for the current
  data).
- Changed the minimum-value colour to pure white while retaining the existing
  teal endpoint; missing module combinations remain separately masked.
- Kept all source values, calculations, cell labels and missing-data handling
  unchanged.

## 2026-09-04 - Added M1+M2+M3 joint-test template

- Added the fillable single-run template
  `DATA/rawdata/PS01_N3_F200_ZERO_M1_M2_M3_TEMPLATE.yaml` for
  `PS01_N3_F200_ZERO_M1_M2_M3_R1`.
- Fixed the test boundary to 200 Hz, `FULL`, `ZERO`, external regulated 3.3 V,
  Teensy connected and running with stable USB power, and STM32 SWD disconnected.
- Recorded that source average current is the sum of the three module branch
  averages; unobserved fault counters are entered as zero.
- Kept the template outside `power_raw.csv` and the derived analysis until a
  completed measurement is supplied.
- Marked the unfilled record as `TEMPLATE / NOT_RUN` so it cannot be confused
  with measured evidence.

## 2026-09-04 - Added N=2 M2+M3 steady-state record

- Added `PS01_N2_F200_ZERO_M2_M3_R1` to `DATA/raw/canonical/power_raw.csv`.
- Recorded source average current as the sum of all module branch averages:
  `8.808 + 7.838 = 16.646 mA`; missing fault counters were recorded as zero.
- Filled temperature fields from the original M2/M3 reference records and
  labelled them as non-simultaneous inherited values; the run remains
  `INCOMPLETE` because timing, source-current extrema and stable branch maxima
  were not supplied.
- Regenerated the derived power analysis and report figures so the N=2 point
  includes both M0+M1 and M2+M3 combinations.

## 2026-09-04 - Replaced active N=4 source for Results figures

- Archived the previous `N=4` row as
  `DATA/rawdata/PS01_N4_F200_ZERO_R1_legacy_20260904.csv` and replaced the
  active row in `DATA/raw/canonical/power_raw.csv` with the new `PS01_M3DROP_A_R1` values.
- Regenerated the derived power analysis and used the new N=4 values for the
  Results figures: current/power, supply voltage and voltage drop.
- Kept the report text unchanged as requested; the previous row remains an
  excluded historical record rather than an active measurement.

## 2026-09-04 - Added M3 voltage-drop raw record and fixed power-test boundary

- Saved the new four-module diagnostic record `PS01_M3DROP_A_R1` under
  `DATA/rawdata/PS01_M3DROP_A_R1.yaml`.
- Recorded that all power experiments use the Teensy connected to the modules
  and running the acquisition/control code, with stable USB power for the
  Teensy and no SWD connection to the STM32 boards.
- Kept the new diagnostic record outside `power_raw.csv` and existing plots
  because its duration, temperatures and status counts are missing, and the
  supplied M3 voltage minimum/maximum order was initially inconsistent and was
  corrected in the following entry.
- Recompiled the report after the Method update; `build/main.pdf` remains a
  49-page PDF.

## 2026-09-04 - Corrected M3 voltage extrema order

- Swapped the M3 source values in `PS01_M3DROP_A_R1.yaml` so that
  `V_module3_min_V=3.259` and `V_module3_max_V=3.262`.
- Updated the derived lower-limit headroom from 127 mV to 124 mV.
- Existing `power_raw.csv`, derived analysis files, figures and report results
  were left unchanged because this diagnostic record remains outside the formal
  analysed dataset.

## 2026-09-03 - Label all measured points in Figure 4.4

- Added direct numeric labels to every measured current and output-power point
  in Figure 4.4.
- Fits, extrapolations, measurements and calculations were unchanged.

## 2026-09-03 - Matched lowest-module labels to their curve

- Figure 4.5 now uses the same dark-charcoal colour for the `Lowest module
  mean` line, markers and numeric labels.
- Measurements, calculations and other figure encodings were unchanged.

## 2026-09-03 (revised project palette)

- Replaced the shared figure colours with `#596073`, `#7BB6BA`, `#DBD4CC`,
  `#D7BBA5`, `#9D725F` and `#B8442D`.
- Kept the source-versus-lowest-module comparison high-contrast using teal
  against dark charcoal; module series retain separate marker encodings.
- Preserved all measurements, calculations, axes and scientific meanings.

## 2026-09-03 (unified scientific figure palette)

- Replaced the previous mixed-color series with the shared muted teal
  scientific palette used by the final report.
- Standardised charcoal axes/text, pale grid and region fills, publication
  export settings, and the continuous heatmap palette.
- Preserved power measurements, calculations, axes, ranges, labels and output
  meanings.

## 2026-09-03 (higher-contrast comparison encodings)

- Separated `Source mean` and `Lowest module mean` with teal-cyan and slate
  blue respectively; the meanings and line/marker encodings are unchanged.
- Increased visual separation between mean-current and separately captured
  maximum bars using the palette's lavender fill and hatch.

## 2026-09-02 (direct voltage-point labels)

- Added a voltage label to every blue source-mean point.
- Added a `M0/M1/M2/M3: value` label to every orange worst-module point, using the module that produced that minimum.
- Added `worst_module_id` to the derived scaling summary only; raw measurements and estimators remain unchanged.
- Updated the report caption and regenerated the report figure exports.

## 2026-09-02 (remove minimum-voltage curve)

- Removed the black `Lowest module minimum` curve from the voltage-scaling figure.
- Kept the Module 3 minimum as an in-plot reference annotation and clarified the averaging/lowest-value rules in the report caption.
- Regenerated all figure exports and preserved the raw and derived CSV files unchanged.

## 2026-09-02 (clean report figures)

- Removed visible titles, subtitles, divider lines, footer notes and redundant panel titles from all seven generated power figures.
- Kept axes, legends, data encodings and essential in-plot numeric annotations; moved fit equations, conditions, sample basis and limitations into the report captions.
- Regenerated the PNG/PDF/SVG outputs and recopied the seven PDF figures used by the report; raw and derived measurement CSV files were not changed.

## 2026-09-02 (integration into final report template)

- Added Power Methods and Results to `../Final Report/`, following MSc booklet pages 10-12; Discussion is an outline only.
- Reused three core and four supplementary PDF figures without alteration; raw CSV and analysis outputs were not changed.
- Documented missing dynamic tests, repetitions, measurement metadata, temperature-field reconciliation and actual supply-board capacity.
- Kept report source/claim checks, completion notes and compilation outputs with the report rather than adding measurements to this dataset.

## 2026-09-02 (scientific figure refresh)

- Refreshed all seven charts using the scientific-visualization and matplotlib skills: consistent 180 mm layout, English labels, readable typography, and color-plus-marker encodings.
- Separated the measured range from model-only extrapolation; retained the original fits and exposed the limited sample basis.
- Replaced truncated branch-current bars with aligned dot plots and voltage-drop lines with an annotated matrix that explicitly marks absent module/run combinations.
- Displayed the full voltage acceptance band and separated temperature records into point-only panels; labelled non-synchronous maxima sums without implying a guaranteed transient bound.
- Added `power_figures.py`, `power_report.mplstyle`, and reproducible PNG (300 dpi), PDF, and SVG exports; retained the original PNG filenames for report compatibility.
- Added a figure index, source/export hashes, a validation script, and validation results. Inspected all seven PNGs for clipping and overlap.
- Corrected the default CSV input and documentation links to `DATA/raw/canonical/power_raw.csv`; the raw CSV and all five derived CSVs remain byte-for-byte unchanged.
- Updated report captions and the experiment log. No new measurement, raw-value correction, or fit change was introduced.

## 2026-09-01 (source-data analysis and folder organisation)

- Added an explicit scope statement: current N<=4 measurements show large supply-current capacity headroom, while scan-reduction spatial algorithms are excluded from this report and reserved for a separate Data Scalability evaluation.
- Added `README.md` and organised reproducible outputs under `DATA/analysis/` and the analysis code under `script/Main/`.
- Added `analyze_power_scalability.py` and `script/requirements.txt`; the script leaves `power_raw.csv` unchanged.
- Generated run, scaling, branch, thermal, anomaly, and JSON summaries plus seven power-scalability figures.
- Added a concise source-data analysis to `Power_Scalability_Measurement_Plan_CN.md`, including current/power fits, voltage margin, branch balance, temperature limitations, and named anomalies.
- Identified Module3's 53 mV average branch drop at N=4, Module2's 8.988 mA single-module current, Module1's N=4 current increase, non-monotonic Teensy temperature, and historical Module1 temperature-field conflict.
- Marked the N=4 64.72 mA value as a non-synchronous conservative upper estimate rather than a measured total-current peak.
- Corrected the planned PS-01 count from 27 to 9, the overall PS-01/PS-02 count from 45 to 27, and the PS-02 run IDs from `MAX` to the fixed `ZERO` load condition.

## 2026-08-31 (LM2596 supply documentation)

- Added the TI LM2596 datasheet to `hardware/new/docs/datasheet/LM2596_datasheet_TI.pdf`.
- Recorded the LM2596 3 A output rating and 3.6/4.5/6.9 A chip-level peak current-limit range in the power plan.
- Distinguished the chip protection limit from the actual current-limit setting of the assembled module.
- Added the LM2596 supply metadata and the unresolved module current-limit setting to `power_raw.csv`.

## 2026-08-31 (200 Hz run preparation)

- Started preparation for `PS01_N1_F200_ZERO_M0_R1`.
- Kept Module 0, `FULL`, `ZERO`, LM2596 3.3 V supply, and mA current range unchanged; only the frequency changes to 200 Hz.
- Left measurement fields pending until the hardware readings are available.

## 2026-08-31 (100 Hz module voltage correction)

- Corrected the Module 0 input voltage in `power_raw.csv` for `PS01_N1_F100_ZERO_M0_R1` to `3.267 V` average, `3.266 V` minimum, and `3.267 V` maximum.

## 2026-08-31 (200 Hz measurement)

- Added the measured `PS01_N1_F200_ZERO_M0_R1` row to `power_raw.csv`.
- Recorded that all available values matched the 100 Hz Module 0 run after changing only the frequency to 200 Hz.
- Left the measurement start time blank because it was not provided.
- Added the preliminary observation that frequency had no obvious supply-data impact for the current single-module, no-load comparison; this is not yet a general conclusion.

## 2026-08-31 (200 Hz start time correction)

- Set `measurement_start_time` for `PS01_N1_F200_ZERO_M0_R1` to `2026-08-31 17:00`.
- Separated the 16:54 preparation time from the actual measurement start time in the experiment log.

## 2026-08-31 (200 Hz maximum-load run)

- Started `PS01_N1_F200_MAX_M0_R1` at `2026-08-31 17:02`.
- Kept Module 0, `FULL`, LM2596 3.3 V supply, and mA current range unchanged; changed the load from `ZERO` to `MAX`.
- Added a pending CSV row for the run; measurement values remain blank until collected.

## 2026-08-31 (200 Hz maximum-load result)

- Completed `PS01_N1_F200_MAX_M0_R1` in `power_raw.csv` with the same measured values as the 100 Hz and 200 Hz `ZERO` runs.
- Recorded the preliminary observation that load change had no visible supply-data effect in the single-module comparison.
- Kept the conclusion incomplete pending repeat runs and additional module counts.
- Removed the temporary `STARTED` placeholder so the CSV contains one authoritative row for this run.

## 2026-08-31 (Module 1 baseline verification)

- Started `PS01_N1_F200_ZERO_M1_R1` at `2026-08-31 17:08` after replacing Module 0 with Module 1.
- Kept 200 Hz, `FULL`, `ZERO`, LM2596 3.3 V, and mA range fixed to verify the preliminary frequency/load conclusion.
- Added a pending CSV row; the fixed baseline will be adopted only after the Module 1 comparison is complete.

## 2026-08-31 (CSV encoding fix)

- Re-saved `power_raw.csv` as UTF-8 with BOM so Excel and VS Code correctly decode the Chinese fields and notes.

## 2026-08-31 (CSV language simplification)

- Replaced the Chinese text inside `power_raw.csv` with English while keeping all values and field meanings unchanged.

## 2026-08-31 (current remeasurement)

- Corrected the Module 0, 100 Hz, `FULL`, `ZERO` current values after reconnecting the meter in the mA configuration.
- Replaced the previous current readings with `8.13 mA` average, `8.112 mA` minimum, and `14.5 mA` maximum for the single-module record.
- Marked the `14.5 mA` value as a short transient peak requiring repeat confirmation.
- Standardized the CSV current value columns to A (`0.00813`, `0.008112`, `0.0145`); retained `DMM_current_range` as `mA`.

## 2026-08-31 (current unit normalization)

- Standardized the current fields and stored values in `power_raw.csv` to mA.
- Renamed current columns from `_A` to `_mA` and stored `8.13`, `8.112`, and `14.5`.
- Added the mA-to-A conversion rule before power calculations.

## 2026-08-31 (data and log separation)

- Moved the completed Module 0 measurement values into `power_raw.csv`.
- Reduced `Power_Scalability_Experiment_Log_CN.md` to experiment actions, timestamps, run IDs, and document changes.
- Updated the measurement plan to identify `power_raw.csv` as the source for collected values.

## 2026-08-31 (temperature measurement update)

- Removed ambient temperature from the direct measurement list.
- Added Teensy temperature to the temperature measurement points.
- Changed the temperature-rise reference from ambient temperature to each measurement point's run-start temperature.

## 2026-08-31 (measurement scope update)

- Removed connector-temperature measurement.
- Removed separate Teensy/Host current measurement.
- Defined source current as the external 3.3 V module-supply current, excluding the Teensy USB supply branch.
- Simplified the total-current and theoretical-current equations accordingly.
- Clarified that steady-state ripple uses a stable-run window, while power-on minimum voltage uses the complete startup transient window.

## 2026-08-31 (static measurement scope)

- Limited the plan to steady-state measurements after a fixed 30 s stabilization period.
- Removed ripple, power-on inrush, recovery-time, waveform, and long-term dynamic measurements.
- Removed the PS-02 and PS-03 experiments; the plan now contains 72 PS-01 runs.
- Changed voltage, current, and temperature fields to stable readings and removed peak/minimum transient requirements.

## 2026-08-31 (dynamic module transition scope)

- Kept PS-01 as the 72-run steady-state measurement.
- Added PS-02 for controlled module add/remove transitions while the remaining system is operating.
- Defined six transition types at 200 Hz and `MAX`, repeated three times, for 18 dynamic-event runs.
- Added healthy-module impact, event minimum voltage, recovery time, reset, current-limit, and data-gap checks.
- Added behavior-to-measurement tables for the PS-01 steady-state and PS-02 module-transition procedures.

## 2026-08-31 (experiment log)

- Added `Power_Scalability_Experiment_Log_CN.md` for the first formal run.
- Recorded the initial condition as Module 0, 100 Hz, `FULL`, `ZERO`, with a separate DMM voltage/current measurement sequence.
- Moved the detailed PS-01 and PS-02 operating procedures, wiring, instrument steps, and run-record templates into the experiment log.
- Reorganised the power plan to match the concise calibration-document structure: motivation, method, measurements, calculations, Evaluation, and outputs.
- Recorded the measured voltage, current, temperature, timestamp, and no-fault status for `PS01_N1_F100_ZERO_M0_R1`.
- Added pending experiment record `PS01_N1_F200_ZERO_M0_R1`, changing only the scan frequency from 100 Hz to 200 Hz.
- Confirmed that the recorded current values use amperes (A); retained the separately reported DMM range information.

## 2026-08-31 (stable summary values)

- Restored average, minimum, and maximum readings for basic voltage and current measurements.
- Defined these three values as readings within the stabilized measurement window, excluding startup transients, inrush, and ripple waveforms.
- Updated the first-run log fields and average-value power/drop calculations.

## 2026-08-31

- Reorganised the plan as a power-only scalability experiment.
- Fixed the test path to FSR-only `FULL` mode; removed ACC and data-algorithm comparisons.
- Added the complete experiment count: 72 main runs, 4 inrush groups with 20 power-on events, and 3 long-term runs.
- Replaced the obsolete ACC term in the theoretical current model.
- Added explicit run IDs, execution order, power-scaling model, pass criteria, and theory-versus-measurement outputs.
- Recorded the actual FNIRSI 2C53P instrument and its DMM/shunt-oscilloscope measurement procedures.
- Corrected the 2C53P DMM description: it supports maximum/minimum values and a time-variation curve; shunt-plus-oscilloscope is reserved for faster transient verification.

## 2026-08-31 (single-module screening closure)

- Confirmed that the recorded 200 Hz Module 0 `ZERO` and `MAX` runs produced identical available measurements.
- Stopped additional single-module frequency/load screening; retained all historical single-module rows, including the incomplete Module 1 baseline row.
- Fixed the formal scalability experiment conditions to 200 Hz, `FULL`, `ZERO`, and changed the steady-state matrix to start at `N=2`.
- Updated the power plan from a frequency/load matrix to a module-count scalability model and changed the formal steady-state total from 72 planned runs to 27.

## 2026-08-31 (Module 1 screening records completed)

- Added `PS01_N1_F200_ZERO_M1_R1` and `PS01_N1_F200_MAX_M1_R1` to `power_raw.csv`.
- Recorded both runs with the same supplied measurements as `PS01_N1_F100_ZERO_M1_R1`.
- Kept both runs `INCOMPLETE` because the module-voltage statistics are internally inconsistent and module-current, measurement-start-time, and supply-limit fields remain unavailable.

## 2026-08-31 (Module 2 and Module 3 baseline runs)

- Added pending `PS01_N1_F200_ZERO_M2_R1` and `PS01_N1_F200_ZERO_M3_R1@ rows for 200 Hz `FULL` `ZERO` reference measurements.
- Kept the formal scalability matrix unchanged; these are module-to-module baseline checks before the `N=2` multi-module runs.

## 2026-08-31 (Module 2 measurement)

- Updated `PS01_N1_F200_ZERO_M2_R1` from `STARTED` to `MEASURED` in `power_raw.csv`.
- Recorded the supplied Module 2 voltage, source-current, and temperature values; stored current in mA and marked the 16.99 mA value as an instantaneous peak.
- Kept the run `INCOMPLETE` because module branch current, measurement-start time, and the power-supply current-limit setting were not supplied.

## 2026-08-31 (Module 1 and Module 2 temperature correction)

- Swapped the regulator and Teensy temperature fields for `PS01_N1_F200_ZERO_M1_R1` and `PS01_N1_F200_ZERO_M2_R1@ after identifying a recording error.
- Kept the voltage, current, and other temperature values unchanged.

## 2026-08-31 (Module 1 voltage maximum correction)

- Updated `V_module0_max_V` to `3.271 V` for `PS01_N1_F100_ZERO_M1_R1`, `PS01_N1_F200_ZERO_M1_R1`, and `PS01_N1_F200_MAX_M1_R1`.
- Removed the related average-greater-than-maximum data-quality warning; all other values remain unchanged.

## 2026-08-31 (two-module power measurement)

- Extended `power_raw.csv` with Module 1 voltage/current fields, calculated total-current fields, per-module STM32 temperature fields, measurement duration, and the separate-branch current method.
- Added `PS01_N2_F200_ZERO_R1` for the Module 0 + Module 1 measurement.
- Calculated total average current as `16.267 mA`; minimum and maximum totals are unsynchronized branch-sum estimates of `16.238 mA` and `32.40 mA`.

## 2026-08-31 (three-module power measurement)

- Extended `power_raw.csv` with Module 2 voltage/current fields and Module 2 STM32 temperature.
- Added `PS01_N3_F200_ZERO_R1` for the Module 0 + Module 1 + Module 2 measurement.
- Calculated total average current as `25.179 mA`; minimum and maximum totals are unsynchronized branch-sum estimates of `24.779 mA` and `48.53 mA`.
- Kept the run `INCOMPLETE` because Module 0 voltage minimum and maximum were supplied in reverse order and measurement metadata remain incomplete.

## 2026-08-31 (three-module Module 0 voltage correction)

- Corrected the `V_module0_min_V` and `V_module0_max_V@ positions in `PS01_N3_F200_ZERO_R1` to `3.262 V` and `3.264 V`.
- Removed the related data-quality warning; all other three-module values remain unchanged.

## 2026-08-31 (four-module power measurement)

- Extended `power_raw.csv` with Module 3 voltage/current fields and Module 3 STM32 temperature.
- Added `PS01_N4_F200_ZERO_R1` for the Module 0 + Module 1 + Module 2 + Module 3 measurement.
- Calculated total average current as `33.134 mA`; minimum and maximum totals are unsynchronized branch-sum estimates of `32.505 mA` and `64.72 mA`.
- Kept the run `INCOMPLETE` because Module 1 maximum voltage was supplied as `2.254 V` while its average and minimum were about `3.253 V`, and measurement metadata remain incomplete.

## 2026-08-31 (four-module Module 1 voltage correction)

- Corrected `V_module1_max_V` in `PS01_N4_F200_ZERO_R1` from `2.254 V` to `3.254 V`.
- Removed the related data-quality warning; all other four-module values remain unchanged.

## 2026-08-31 (Module 3 measurement)

- Updated `PS01_N1_F200_ZERO_M3_R1` from `STARTED` to `MEASURED` in `power_raw.csv`.
- Recorded the supplied Module 3 voltage, source-current, and temperature values; stored current in mA and marked the 16.30 mA value as an instantaneous peak.
- Kept the run `INCOMPLETE` because module branch current, measurement-start time, and the power-supply current-limit setting were not supplied.

## 2026-08-31 (Module 1 baseline frequency correction)

- Changed the pending Module 1 baseline run from 200 Hz to 100 Hz before measurement.
- Renamed it to `PS01_N1_F100_ZERO_M1_R1` and set the corrected measurement start time to `2026-08-31 17:10`.
- Kept the previously recorded Module 0 runs unchanged; no 200 Hz Module 1 measurement data was retained.

## 2026-08-31 (Module 1 100 Hz zero-load measurement)

- Recorded `PS01_N1_F100_ZERO_M1_R1` in `power_raw.csv` as the completed 100 Hz `FULL` `ZERO` Module 1 run.
- Stored source voltage as `3.281/3.281/3.282 V` and source current as `8.119/8.112/15.98 mA` for average/minimum/maximum; the peak was marked as instantaneous.
- Stored the supplied module voltage and temperature readings; normalized the current fields to mA.
- Kept the run `INCOMPLETE` because the supplied module voltage average (`3.271 V`) exceeds its supplied maximum (`3.270 V`) and module current/start-time data are unavailable.

## 2026-08-28

- Corrected LaTeX escaping in the measurement and calculation formulas.
- Limited the FSR frequency test points to 240 Hz, the current hardware maximum.
- Added the required measurement-tool list and mapped each tool to the corresponding measurements.
- Corrected the power-scalability frequency ceiling from 240 Hz to 200 Hz, the current maximum combined-system frequency.

- Added `Power_Scalability_Measurement_Plan_CN.md`.
- Recorded the test matrix, direct measurements, calculated quantities, and output files for subsequent power-scalability experiments.
- Updated Figure 4.7's voltage-drop matrix gradient from #DBD4CC to #0F9EA8; data, scale and missing-value encoding are unchanged.
- Changed Figure 4.8 to a vertical two-panel layout; individual-cell traces now use thinner #7BB6BA lines. Data, measurement points, fitted lines and axes are unchanged.
- Updated Figure 4.10 calibration-dispersion colours: FIT PRESS uses #7BB6BA and LINEAR uses #8B84A3; NORM CAL, data and axes are unchanged.
- Updated Figure 4.8 measured points to #45728F; cell traces, connected mean/model lines, data and layout are unchanged.

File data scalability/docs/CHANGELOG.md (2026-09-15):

# Data Scalability changelog

## 2026-09-07 - Final evidence package

- Consolidated the current variable-length FULL/DELTA campaign into 114 indexed recordings: 48 FULL zero-load, 45 DELTA zero-load and 21 dynamic.
- Preserved 90 selected zero-load windows and 15 windows from five complete passing dynamic batches. Diagnostic batches and connector findings remain separately identified.
- Kept raw recordings, source hashes, selection tables, independent audits and report-ready figure sources together. No raw source file or report PDF was modified.
- Documented USB and HOST SPI planning models, including the 480 Mbit/s USB reference, the user-confirmed 10 MHz HOST SPI reference and the conditional N>4 extrapolation.
- Moved superseded 2026-09-06 review snapshots, generated caches, the one-time archive utility and replaced Chinese notes to archive/. The complete earlier changelog is preserved as archive/historical_documents/CHANGELOG_CN.md.

## 2026-09-06 - Historical campaign boundary

- The pre-variable-SPI recordings remain under history/pre_variable_spi_20260906/ and are excluded from current report statistics.

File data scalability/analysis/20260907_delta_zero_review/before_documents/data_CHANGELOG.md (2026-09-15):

# Data Scalability 文档修改日志

## 2026-09-07 - M012 补测与 N=4 通过，FULL 零载主矩阵完成

- 核验6条新记录：M0_M1_M2完整补测批次三条和N=4三条，全部主窗口PASS。独立解析48,070个有效MUL1、168,243个有效ESKF并核对192,280行module_log；主窗口36,017包/126,058ESKF，CRC、内外序号、模块更新、偏移及摘要计数均无新增异常。全窗口3 PASS/3仅1 B尾片段CHECK。
- 补测M012主包率200.084479±0.057550 Hz、USB完整包5.077344±0.001460 Mbit/s，N4为200.066062±0.034040 Hz、6.747828±0.001148 Mbit/s，均n=3、段间样本SD。有效包长分别3172/4216 B。补测R3的278.7935 ms PC完成间隔对应桥端5 ms，序号连续，保留在统计中。
- 新M012保存在原组合下 `Batch_20260907_004948_668301/Repeat_1..3/`；原三条Repeat目录不搬迁、不覆盖。N4整理为 `data/FULL/N=4/200Hz/M0_M1_M2_M3/Repeat_1..3/`。36个原文件208,073,646 B搬迁前后SHA256一致。
- FULL零载主矩阵选取15种组合各一个完整三次批次，45条全部主窗口PASS：M012整批使用补测batch，其余使用原批次，包括原M013低率PASS。选择不按帧率筛选单条。原M012失败和两条合格记录仍保留，旧两条PASS作为补充；不能以补测通过改写历史失败。
- 总索引48条/47主窗口PASS/1 CHECK，288原文件、16实际批次。新增primary_matrix.csv与primary_matrix_selected/selection_reason/replacement_batch_id；group_statistics明确改为45条主矩阵，另存全部47 PASS辅助统计、48条诊断统计及逐批统计。M012分别为主n3/batch1、全部PASS n5/batch2、全部记录n6/batch2。选择清单位于 `analysis/20260907_full_completion_review/primary_selection.json`。
- 更新data总览、FULL主矩阵总表、N3补测与N4说明，并保存修改前派生文档。独立审计、时间检查、路径映射和搬迁验证均位于 `analysis/20260907_full_completion_review/`。原数据、旧审计、GUI、设备固件、论文和图表未修改；此完成状态只覆盖FULL零载。

## 2026-09-07 - N=3 四种 FULL 零载组合已整理，保留一条主窗口失败

- 固定核验N=3四种组合共12条，每组一个batch、Repeat 1/2/3，FULL、zero_load、目标200 Hz，每次40 s保留前10 s。主窗口11 PASS/1 CHECK；全窗口4 PASS/8 CHECK，不能照抄此前全部主窗口通过的结论。
- 原日志口径：96,120个候选、96,119个外CRC有效包，288,357个有效ESKF；主窗口72,029候选/72,028有效包。逐行核对384,476行module_log，独立结果与原日志/summary一致。标准包长为3172 B。
- M0_M1_M2第一次（20260907_000133_670681）在19.4723392 s有真实完整性异常：seq1675977头到1675978头相隔2148 B，比声明长度短1024 B；1675978完整有效包仍在raw中，但被实时解析器越过。Session缺号2不能写成两个原始包都丢失。独立raw扫描额外恢复一个有效包作为证据，不回填日志/summary，不据此改为PASS；故障来源仍未定位。
- M0_M1_M3第三次为PASS但帧率199.123828 Hz，末段存在123 ms桥端入队间隔，另有301.3735 ms PC完成时间间隔及1020 B截止半包。保留在性能统计，不因较低帧率剔除；时钟字段不能直接证明物理扫描丢失或SPI饱和。
- 将12条全部保留并整理至 `data/FULL/N=3/200Hz/<组合>/Repeat_1..3/`，包括异常Repeat_1。72个原文件共364,788,907 B，搬迁前后SHA256一致，原数据/状态/元数据/嵌入旧路径不修改。证据、路径映射、raw和时间审计位于 `analysis/20260907_n3_full_review/`。
- 性能汇总按主窗口完整性过滤，M0_M1_M2有效n=2，其他组n=3；全部三条另列all_runs_diagnostic_statistics，异常仍进入可靠性评估。总索引现有42条、14个配置、252原文件，增加main_eligible与错误/时间备注；无错误性能窗口41条。还需补齐M0_M1_M2一条合格窗口及N=4三条，不能将N=3记成全部合格。
- 未更新设备固件、GUI或论文图表；保留N=1/N=2及历史审计。批次内时间重复不作为三个独立装配Block。

## 2026-09-06 - 完成 N=2 六种 FULL 零载组合的核验与整理

- 固定核验23:22:05–23:48:31（英国当地 +01:00）的18条完成记录：四槽位任取两个的六种组合，每组一个batch、Repeat 1/2/3；FULL、zero_load、目标200 Hz，每次40 s保留前10 s。18个主窗口全部PASS。
- 独立解析144,212个完整MUL1、288,424个有效ESKF，逐行核对576,848行module_log；主窗口108,109个MUL1和216,218个ESKF。包长统一2128 B，内外CRC、序号、模块模式、日志偏移/数量和会话错误增量均无异常。
- 全窗口2条PASS、16条CHECK；后者仅由截止时1 B尾片段导致。17个起点跨界包中11个有真实前尾/后首字节验证，六个批次首段的缺失magic前缀仍明确作为推断；原始检查状态保留。
- 将18个时间戳目录整理至 `data/FULL/N=2/200Hz/M0_M1..M2_M3/Repeat_1..3/`。108个原文件共393,046,829 B，搬迁前后SHA256一致；run_id、batch_id、Repeat、嵌入的旧路径及所有原始内容不修改。
- 新增N=2组/组合说明、均值±样本SD与n、逐次索引、路径映射和独立审计；证据位于 `analysis/20260906_n2_full_review/`。更新data总README，并合并N=1/N=2为30条记录、10个配置、180个原文件的CSV索引。历史数据与N=1审计原样保留。
- FULL零载按每组合三段的当前主矩阵完成30/45段，剩余N=3四种组合和N=4一种组合。n=3仍是同一setup的连续时间重复，不写成三个独立Block；本次不替换论文或旧图。

## 2026-09-06 - 核验并分类新采集的 12 条 FULL 单槽位零载记录

- 审计本次固定快照：22:59:34–23:11:09（英国当地 +01:00），FULL、zero_load、N=1、目标200 Hz，M0–M3各三次。全部主窗口PASS；独立核验96,193完整MUL1/ESKF、主窗口72,096包，内外CRC、模块模式、序号与日志offset均一致。全窗口CHECK唯一原因是每段末尾1 B片段，不要求因此重录。
- 按原FULL层级将12个时间戳目录整理为 `data/FULL/N=1/200Hz/M0..M3/Repeat_1..3/`。保留全部原始文件、run_id、batch_id、Repeat和summary中的采集时路径；72个文件共159,181,044 B，搬迁前后SHA256全部一致。
- 新增data总README、组/槽位目录说明、逐次run_index、段间均值/样本SD/n的group_statistics、逐文件path_map及搬迁验证。完整证据、可复现只读审计脚本和整理计划位于 `analysis/20260906_current_data_review/`。
- 每槽位n=3表示同一setup连续时间窗口，batch_n=1；不充当三个独立装配Block。后续批次不得覆盖Repeat目录。未修改原始测量或历史归档，未更新报告和旧图；schema2新分析必须使用main窗口。

## 2026-09-06 - 修复录制启动时清空半包导致的假跳号

- 原 GUI 在每次开始录制时重置 PacketFramer，丢弃已收到的半包前缀，下一完整包触发会话 seq gaps/lost 增加；DELTA 还可能产生连带缓存链错误。改为会话解析缓冲、序号与 DELTA 缓存连续运行，录制文件使用相对于本段的 raw_offset。
- 跨起点包仍正常参与实时解析，但只保存本窗口实际收到的原始后缀。用 capture_start_boundary 事件、计数和 known_start_boundary_bytes 单列，不回填录制前字节，不计入本文件完整包率、K/q，也不伪造文件内 DELTA 基线。真实跳号、CRC、模块和解析错误保留。
- GUI 的 lost 标签改为 missing MUL1，说明它是按 MUL1 序号估算的缺包数量，不能直接解释为 STM32 物理扫描丢失。
- 只读审计当前三段 FULL/M0：前两段启动各增加一次会话跳号，第三段没有增加。R1 尾部与 R2 开头可拼出序号801025的完整包，内外CRC通过；三段主窗口均PASS。详细证据见 analysis/20260906_record_boundary/ANALYSIS_CN.md；原始数据、packet_log和summary均未修改。
- 验证：20项记录后端、26项GUI/串口集成、7项检测及解析器自测通过，包含FULL/DELTA三连录半包边界和真实缺包保留。修改前备份、测试暂存和部署哈希位于 docs/Final/tmp/gui_stream_boundary_20260906。重启GUI生效，设备固件不变。

## 2026-09-06 - 每次 Record 自动连续录制三次

- GUI 按钮改为 Record x3，每次点击冻结同一配置并由串口线程自动完成三次独立录制。默认每次40 s、每次前缀10 s，共约120 s；三份原始数据和逐段统计分别保存。
- Repeat 不再手选，自动编号1/2/3；三段共享batch_id、模块清单和Block。保存每段开始时的检测快照，但不因模块未更新而缩小预期N。这是同一设置下的连续时间窗口，不是自动完成三个独立装配区组或动态重新加载。
- Stop 保存当段并取消余下；断线、启动或写入/收尾失败取消后续。普通完整性CHECK保留并继续，不自动重试覆盖。暂停热力图不暂停批次；批次内禁止从GUI改变模式和扫描率。
- 原单次计划repeat保留为planned_repeat；CSV仍为原单次/区组设计，不将三个自动窗口写作完成三个计划行。当前FULL零载15种组合各点击一次即可产生45段。
- 验证：22项GUI/串口集成、13项记录器、7项模块检测及解析器自测通过；包括Stop边界、断线、写入失败、双击和设置窗口打开时三连录。主界面/设置截图检查通过。已部署到原GUI目录，修改前备份与部署哈希位于 `docs/Final/tmp/gui_repeat3_20260906`；无实机采集或固件变动。

## 2026-09-06 - 自动模块识别与简化设置

- 手动录制从近期有效协议帧自动确定通信槽位和模式，并在 Record 时锁定预期清单；录制期间缺失更新不会通过缩小 N 被隐藏。开始前再次核对新鲜度；计划录制保留 CSV 预期清单。
- Settings 移除模块、模式、扫描率、路径等重复输入，改为人工条件的单选项及可选备注。目标扫描率、SPI 和阈值注明控制/本地配置来源，实际包率单独测量；不声称从设备读回。
- Settings 打开时暂停热力图定时刷新，串口接收、解析、原始数据录制继续。Save/Cancel/窗口关闭后恢复并显示最新帧。
- Record 不再额外发送 MODE/SCAN_HZ 命令，直接记录当前数据流。模块编号仍为 CS/IRQ 槽位，无唯一板卡身份字段；相关说明已加入当前 report 2.0 正文与协议附录，并更新 PDF。
- 验证：14 项 GUI/串口集成、7 项检测、13 项记录后端测试及解析器自测通过；检查设置窗口暂停期间原始数据完整、关闭恢复绘制、录制期模块清单固定，界面截图无重叠。只做离线验证，没有新增实机实验数据。
- 已更新原 four-module-variable-spi GUI 路径；修改前备份及部署哈希位于 `docs/Final/tmp/gui_auto_settings_20260906`。重启 GUI 后生效，STM32/Teensy 固件不变。

## 2026-09-06 - 新版 GUI 实验记录与历史归档

- 更新 four-module-variable-spi 的 PC GUI：支持半天实验计划逐行选择、条件与模块映射编辑、可配置录制/前缀时长、停止录制和事件标记。
- 新记录保存所有接收到的原始字节，并分别统计全程与主分析窗口；增加逐模块 K、ESKF 比例、模块缺失更新、CRC/缓存链与本次计数差。未改变 STM32/Teensy 固件和 USB 帧格式。
- 将活动 data 中的 88 次实验、470 个文件（503,037,879 B）整体移至 `history/pre_variable_spi_20260906/data`。移动前后全部文件 SHA-256 一致；保留原始内容，通过 archive_manifest.json 和 path_map.csv 追踪路径。
- 重新创建空的活动 data 目录，供新版 GUI 采集。Power 和 Calibration 不在本轮重测或归档范围内。
- 绘图脚本支持显式 --data-root，历史分析默认使用归档路径；不自动将历史记录混入新版实验。新版图表的 run 选择和主窗口统计适配仍需在采集后完成，现有报告与图表未重生成。
- 旧格式绘图/审计入口遇到 schema_version>=2 会明确停止，提示使用 scopes.main 和显式 run 选择，避免缺少旧字段时静默生成零值或混用全程与主窗口统计。
- 验证通过：13 项录制后端测试、8 项 GUI/串口集成测试、GUI 布局检查，以及含 212 个 STM32 编码帧的原生协议回归。历史异常记录回放识别出 6 次模块未更新。尚未连接设备执行新实验。

## 2026-09-03 - Separated the enlarged Figure 4.3 legends

- Moved the enlarged legends lower in the USB and Host SPI source panels so
  they remain separate from the enlarged x-axis titles.
- Data, calculations, axes ranges and plotted meanings were unchanged.

## 2026-09-03 - Enlarged Figure 4.3 panel typography

- Increased the legends, axis titles, tick labels and numeric annotations in
  all four Figure 4.3 source panels.
- Data, calculations, axes ranges and plotted meanings were unchanged.

## 2026-09-03 - Enlarged legends in Figures 4.1--4.3

- Increased legend text in the combined DELTA record figure, the DELTA
  demand overview and the four-panel USB/HOST SPI overview.
- Data, calculations, axes, colours and plotted meanings were unchanged.

## 2026-09-03 - Restored per-panel DELTA y-axis ranges

- Restored independent y-axis limits for the four-panel DELTA composite so
  panels (a) and (b) retain the original single-module scale rather than the
  larger four-module range.
- The plotted records, x-axis, colours and calculations are unchanged.

## 2026-09-03 - 合并 Figure 4.1 的四个 DELTA 面板

- 将原 Figure 4.1 和 Figure 4.2 合并为一个四面板竖向图
  `08_delta_combined_results.png/.pdf`。
- 面板标记为 (a)--(d)，依次表示单模块无负载、单模块大面积动态负载、
  四模块无负载和四模块全覆盖同时负载。
- 报告仅引用合并后的 Figure 4.1；原两张两面板图保留为历史导出，原始数据和计算未修改。

## 2026-09-03 - Host SPI 统一采用无填充 DELTA

- 将 Host SPI 统一建模为只传输有效 DELTA 字节，不发送固定槽位填充，
  不叠加 USB 侧的 MUL1 外层封装。
- 更新 Host SPI 理论图、交点表、figure manifest、README 与独立
  Data Scalability 文档；Host SPI 曲线现在对应 K=0、240、480 三种
  DELTA 活动量。
- 更新理论测试，使其验证无填充 DELTA 公式及各活动量下的带宽交点。

## 2026-09-03

- Figures 4.1 and 4.2 use `#7BB6BA` for the main DELTA trace and `#B8442D`
  for all three horizontal reference/mean lines.
- The horizontal axes in Figures 4.1 and 4.2 use Dark Charcoal `#3D3539`.
- The three horizontal references are differentiated as zero-load `#596073`,
  recorded mean `#9D725F`, and FULL `#B8442D`.
- Figure 4.3's `K=240` curves now use `#8B84A3` in the USB and Host SPI
  panels.
- Figure 4.4's four-dimensional overview now uses `#8CD1B2` for the
  `N=50` curve previously shown in `#45728F`.
- Figure 4.4's `N=50` curve is restored to `#45728F`; its 3D surface now
  uses a `#45728F` to `#8CD1B2` gradient.
- Removed the surface mesh from Figure 4.4 while retaining the 3D coordinate
  grid and the right 2D reference grid for readability.
- Restyled the Figure 4.4 coordinate grid as a clearer three-dimensional
  framework with lightly tinted panes; the sloped surface remains ungridded.
- Replaced the pane-only reference grid with an explicit three-plane X/Y/Z
  coordinate lattice (XY, XZ and YZ); the data surface remains ungridded.
- Reverted the latest three-plane coordinate-lattice restyling in Figure 4.4;
  the prior default 3D coordinate grid is restored while the data surface
  remains ungridded.
- Restored Figure 4.4 to the screenshot-matched rendering: semi-transparent
  `#45728F` to `#8CD1B2` surface gradient with its original fine surface mesh.
- Removed the integrity/transfer-status chart that occupied Figure 4.5 from
  the final report body. Replaced it with a text statement that all recorded
  experiments completed data acquisition; existing `CHECK REQUIRED` integrity
  records remain explicit and are not relabelled as full validation passes.
- Rebuilt Figure 4.3 so each of its four source panels keeps its own aspect
  ratio and vertical geometry; the composite is now placed at `\textwidth`
  in LaTeX so it stays within the document limits without distorting panels.
- Updated Figure 4.7's voltage-drop matrix to a sequential gradient from
  `#0F9EA8` to `#45728F`; data, normalization range and annotations are unchanged.
- Reduced the opacity of Figure 4.4's sloped surface from `0.78` to `0.58`
  so the underlying 3D coordinate structure is easier to see; surface colours,
  mesh, axes and data are unchanged.
- Changed Figure 4.6's compliance-band fill to translucent `#7BB6BA` and
  changed the `Source mean` curve and labels to `#D7BBA5`; thresholds, data and
  axes are unchanged.
- Removed the mesh lines drawn on Figure 4.4's sloped surface while retaining
  the 3D coordinate grid, surface transparency, colours and all data.
- Updated Figure 4.7 so its minimum-value colour is `#DBD4CC`, with a
  continuous gradient to the maximum-value colour `#45728F`; data and scale are unchanged.
- Updated Figure 4.8 so per-cell traces use `#0F9EA8`, measured points use
  `#9D725F`, and the connected mean/model lines use `#3D3539`; data and axes are unchanged.
- Reduced the height of Figure 4.4 panel (b) to 80% of its previous height
  while preserving its width, axes, ranges and plotted data.
- Reduced each Figure 4.3 overview panel to the same 80% height proportion
  while preserving each panel's width, order, source artwork and data.
- Recoloured Figure 4.4 for clearer comparisons: N=1 uses `#8B84A3`, N=25
  uses `#7BB6BA`, N=50 uses `#B8442D`, and N=100 uses `#9D725F`; the surface
  gradient remains `#45728F` to `#8CD1B2`, with `#D7BBA5` surface edges and
  `#DBD4CC` coordinate reference grids.
- Restored Figure 4.3 panels to 100% height and matched its left/right column
  widths and spacing to Figure 4.4 (`width_ratios=[1.16, 0.84]`).
- Trimmed unused white margins from the four source panels before composing
  Figure 4.3 so the plotted content is larger without changing panel data.
- Recoloured the six Figure 4.5 load-condition bars in order with
  `#8B84A3`, `#7BB6BA`, `#B8442D`, `#9D725F`, `#D7BBA5` and `#DBD4CC`.
- Removed Figure 4.5 from the final report body; its source data and generated
  auxiliary artwork remain available outside the report flow.
- Restored Figure 4.4's original curve mapping: N=1 `#7BB6BA`, N=25
  `#B8442D`, N=50 `#45728F`, and N=100 `#596073`; its original surface-edge
  and coordinate-grid styling is also restored.
- Figure 4.3 now explicitly uses equal 1:1 row heights, preserving 100% height
  for all four panels while retaining the Figure 4.4 left/right width ratio.
- 将统一图表配色更新为 `#596073`、`#7BB6BA`、`#DBD4CC`、`#D7BBA5`、
  `#9D725F` 和 `#B8442D`。
- 需要直接比较的序列使用青蓝—砖红或青蓝—深灰高对比组合，并保留
  线型、标记和图案等冗余编码。
- 未修改原始数据、计算逻辑、坐标范围、文字内容或科学含义。

## 2026-09-03

- 将数据可拓展性图表、DELTA 帧图和数据流图统一为低饱和度青绿—蓝灰
  科研配色，并集中引用 `docs/Final/figure_style.py`。
- 统一坐标轴、文字、网格、图例、透明度和静态导出背景；连续图表改用
  由青绿色派生的连续色图。
- 未修改原始数据、计算逻辑、坐标范围、文字内容或科学含义。
- 对多条件柱状对比图增加颜色区分度，并保留原有条件顺序与数值标注。

## 2026-09-02

- 调整 02E 和 USB/HOST SPI 总览的面板标记位置，并扩大总览的标题遮罩区，确保图内仅保留 (a)–(d) 面板标记；所有面板说明继续放在报告题记中。

## 2026-09-02

- 按最新排版要求移除 02E 左侧三维图中的 FULL boundary at K=480 曲线及其图例、标题说明；右侧 FULL 参考虚线保留用于曲线比较。

## 2026-09-02

- 移除 02E 左侧三维 DELTA 图中的 FULL 参考斜面，保留 K=480 处的 FULL 边界线及右侧各模块数的 FULL 参考线，避免参考平面遮挡主体曲面。

## 2026-09-02

- 将 08A/08B 中水平参考线和均值线的数值移到绘图区右侧独立标注区，并用引线连接，避免与折线数据重叠。

## 2026-09-02

- 优化 02E 三维图：降低 FULL 参考斜面的透明度和网格干扰，并加粗 DELTA 与 FULL 在 `K=480` 处的交界线，使主体 DELTA 曲面保持清晰。

## 2026-09-02

- 新增 `02e_delta_usb_k_overview_200hz.png/.pdf` 及配套 CSV：固定 200 Hz，左侧为 N–K–USB 传输量三维模型并叠加当前 FULL 参考斜面，右侧为选定模块数的 DELTA 曲线及对应 FULL 传输量标记。
- 更新生成脚本、README 和 `figure_manifest.json`；新图保留为独立导出，不改变原有 02A–D 和四图总览。

## 2026-09-02

- 更新 `08a_delta_single_module_results` 和 `08b_delta_four_module_results`：去除动态阶段背景色，在所有水平参考线最右侧标注数值，并在下方动态面板标记最高普通 DELTA 帧。
- Figure 4.3 改用既有的 USB/HOST SPI 四图总览；报告图题同步精简，不再列出具体实验数值。
- 生成脚本现在会自动同步两张 PDF 到报告的 `figures/data` 目录，避免报告继续引用旧副本。

## 2026-09-02

- 新增 `figures/source/generate_delta_composite.py`，从四个指定实验目录的原始 `packet_log.csv` 和 `summary.json` 重新生成两张上下排列的 DELTA 结果图：`08a_delta_single_module_results.png/.pdf` 和 `08b_delta_four_module_results.png/.pdf`。
- 两张图分别比较 N=1/M1 的无负载与大面积动态负载，以及 N=4/M0–M3 的无负载与全覆盖同时负载；图内仅保留必要的坐标、图例和数据编码，实验条件及数值说明移至报告图题。
- 原始实验文件和各实验目录中的独立图未修改；报告使用矢量 PDF 版本。

## 2026-09-02

- Rewrote `docs/Data_Scalability.md` as a concise English, report-oriented chapter with the structure: Introduction, Methodology, Results, Discussion, and Conclusion.
- Kept the main argument focused on data scalability: FULL versus DELTA, USB payload growth, module scaling, activity dependence, and reconstruction integrity.
- Positioned the current DELTA implementation accurately as event-inspired synchronous transport, not a fully asynchronous AER/event-driven sensor.
- Added verified references on AER, asynchronous event sensing, and event-driven tactile encoding at the relevant background and discussion points.
- Added `bibs/data_scalability.bib` for later LaTeX report integration.
- No firmware, GUI, raw experiment data, or figure files were changed.

## 2026-09-02

- 按最新排版要求更新图 02：02C 的模块范围改为 N=1–10；移除 02D 局部放大图，将 10 MHz 与 41 MHz 交点直接标记在主图；删除 02A–02D 图下方的解释性备注并重新生成四张独立图及 2×2 总览。未修改固件、GUI 或原始实验数据。
- 微调 02D 横轴刻度：移除与 41 MHz 交点 N≈24.55 重叠的 N=25 普通刻度，保留交点标签以避免视觉重叠。
- 图 02 链路拆分（取代下方早期混合图）：生成 02A USB 三维图、02B USB 200 Hz 曲线、02C HOST SPI 三维图、02D HOST SPI 200 Hz 曲线四张独立图。02A 为 N=1–100、f=0–700 Hz；02B 为 N=1–700、200 Hz；02C 为 N=1–10、f=0–700 Hz；02D 为 N=1–30、200 Hz。原 `02_usb_theoretical_3d` PNG/PDF 原位更新为 02A，保留已有链接。
- USB 两图及其 CSV 移除所有 SPI 参考，保留 USB 480 Mbit/s 原始信号速率参考；FULL 的 200 Hz 交点 N≈286.24 投影至横轴，K=240、K=0 的图外交点写入说明。明确这是应用数据需求与原始速率参考的比较，不是已实现的模块容量。
- HOST SPI 重新按当前代码每模块固定 1044 B（含填充）建模：`R=8×1044×N×f/10^6 Mbit/s`；FULL 与 DELTA 重合，不叠加 USB 封装或并行 MOSI 命令。分别标注当前 10 MHz 与假设 41 MHz 原始带宽；200 Hz 放大图显示 N≈5.99、24.55 的理想时钟预算交点，未声称实际容量或去填充已实现。
- 新增三份独立理论 CSV，更新原 USB CSV 和交点 CSV；交点表按 `link` 明确区分 USB/HOST SPI。同步更新 README、生成清单和可复现脚本；增加 `test_theoretical_links.py`，12 项公式、边界、交点、表格及输出检查全部通过。四图逐一检查排版，PNG 均为 3780×2700、300 dpi，并配套 PDF。
- 本次仅更新图 02 系列及配套说明；图 01、04、05、06、07 的 PNG 哈希均保持不变。原始实验数据、GUI、STM32 与 Teensy 固件未修改。
- 追加输出质量修正：图 02A–D 的 PNG 显式转换为不透明 RGB 白底，并保留 300 dpi；公式、数据表、PDF 与实验数据不变。
- 增加 `02_four_panel_overview.png/.pdf` 总览图，将四张独立图按 2×2 排列；独立图、理论表格和原始实验数据均保留。
- 在 HOST SPI 的 02C、02D 中增加去除固定槽位填充后的 DELTA 理论值：`R=8N(84+2K)f/10^6`，用 K=0、K=240 展示；K=480 与当前 1044 B 固定槽位重合。该曲线明确标记为假设模型，未修改当前固件。

- 图 02 后续调整：右侧截面从 700 Hz 改为 200 Hz，纵轴调整为 0–200 Mbit/s；41 Mbit/s 参考线的交点增加垂直虚线、点标记和横轴模块数 N≈24.43、45.07。USB 480 Mbit/s 位于右图范围外，明确注明 N≤100 无 USB 交点；左侧 N=1–100、f=0–700 Hz 与两个带宽平面保持不变。新增交点 CSV，同步更新 PNG、PDF、README 和生成清单；未修改其他图、原始实验记录或固件。
- 按用户要求使用 `scientific-visualization` 和 `matplotlib` 技能更新图 02、05、07；增加可复用 `figures/source/report.mplstyle`，统一字体、配色、线型、图例、留白及 300 dpi PNG/PDF 输出。
- 图 02 的理论范围扩展为 N=1–100、f=0–700 Hz，添加单方向 SPI 41 MHz（41 Mbit/s）和 USB 2.0 HS 原始信号速率（480 Mbit/s）参考平面，并添加 700 Hz 截面。说明其为原始速率参考，而非实测应用吞吐量。
- 修正理论图的模块 header 计数：1–4 模块保留四个 header，超过四个模块按每模块 4 B 元数据外推；统一 `H(N)=24+4max(4,N)`。DELTA K=480 与 FULL 等长，合并重叠曲面。
- 图 05 扩展至 100 模块，FULL 使用理论模型，DELTA 使用 N=4 实测平均每模块载荷（含同步帧）的条件外推；单独保留 N=1–4 实测面板、逐次记录和组平均，并保留 CHECK REQUIRED 数据。没有把外推值标成实测结果。
- 图 07 扩展为 N=1–100、K=0–480 的完整热图和代表性曲线；采用等效逻辑 round 长度 kB，说明 100 模块需要扩展当前协议与硬件，未计新分包开销。
- 按要求将图 03 `03_full_theory_vs_measured.png` 移至 Windows 回收站（可恢复），删除生成函数并更新 README 索引；不再自动重新生成该图。
- 新增 `figures/tables/` 保存理论网格、外推值和观测数据引用，新增 `figure_manifest.json` 记录软件版本、来源和假设。原始实验数据、GUI 和固件未改动。
- 已逐图检查最终排版，并核对 PNG 的 300 dpi 元数据、41 条实测引用、48,100 个 DELTA 理论网格点、N=100/f=700 的峰值和单模块 K=0 的 124 B 下界。

## 2026-09-01

- 明确当前研究范围：以 `FULL` 为基准，仅研究 `DELTA`。
- 将 `SPATIAL` 标记为暂缓、废弃方案，不纳入当前实验与结论；原有内容保留作为历史设计记录。
- 明确本章只研究数据传输量、USB 带宽和数据可拓展性；元件功耗归入下一章 `Power Scalability`，暂不通过软件优化。
- 精简范围备注，明确暂不通过软件算法减少功耗。
- 从 `Data_Scalability.md` 正文中移除 `SPATIAL` 全部章节、公式、流程和图片引用。
- 收缩实验范围：合并 `FULL` 与 `DELTA` 的活动量对比，重点验证 `DELTA` 对模块扩展和带宽限制的改善；协议、阈值和缓存等内容仅保留为基本检查。
- 整理新增的 12 次 DELTA 无负载实验：M0–M3 各重复 3 次，统一归档到 `data/DELTA/N=1/200Hz/`，并记录逐 MUL 长度、同步帧数量、USB 数据率及完整性检查结果。
- 在 `script/plot_delta_mul_length.py` 新增 DELTA MUL 长度可视化脚本：自动读取每次实验的 `packet_log.csv`，以记录经过时间为横轴、当前 MUL1 长度为纵轴，并为每次记录生成独立 PNG 折线图。
- 将同步帧改为橙色虚线标记，并将默认输出位置改为每次实验自己的数据目录；复制当前 GUI 到 `script/four-module-fsr-monitor.py`，启动命令已切换到该副本，DELTA 记录完成后会自动启动当前实验的绘图。
- 调整绘图含义：`DELTA_SYNC` 不再作为 MUL 长度数据点绘制，只在其发生时间显示竖向虚线；蓝色折线仅表示普通 DELTA MUL 长度。
- 在 MUL 长度图中增加理论无负载参考线：当前单模块协议的最小完整 `MUL1` 长度为 `124 B`，使用红色水平线表示。
- 将 DELTA 无负载数据目录从 `.../N=1/200Hz/...` 简化为 `.../N=1/...`，因为当前全部 DELTA 测试统一使用 `200 Hz`。
- 更新 `script/plot_delta_mul_length.py`：纵轴固定从 0 开始并按记录中的最高同步帧自适应上限；根据 `updated_mask` 和各模块算法自动识别实际模块数；零负载理论线按活动模块数自动计算；不同模块的 `DELTA_SYNC` 使用不同颜色的虚线标记。
- 为现有 39 次实验补充活动模块、模块数量 `N`、目标扫描频率；为现有 Delta 记录手动补充 `Zero load` 负载条件，并修正归档后 `summary.json` 中失效的旧文件路径。
- 更新 `script/four-module-fsr-monitor.py`：后续 GUI 记录自动将活动模块、模块数量 `N`、目标扫描频率、实际观测算法和请求算法写入 `summary.json` 与 `experiment_log.md`；负载情况仍不由 GUI 自动推断。
- 修正 GUI 自动绘图触发条件：Delta 记录现在根据当前选择模式或实际观测到的 Delta 算法，并确认 `packet_log.csv` 已生成后启动 MUL 长度绘图。
- 整理最新 6 次 Delta 无负载记录：根据 `updated_mask` 检查后确认它们实际是 6 种 `N=2` 双模块组合，而不是单模块记录；已归档到 `data/DELTA/Zero_load/N=2/` 并生成 6 张 MUL 长度图。
- 更新 `data/DELTA/Zero_load/README.md`，合并 N=1 与 N=2 的实验条件、目录结构和结果汇总。
- 发现并整理 1 次额外完成的三模块 Delta 无负载记录：`M0_M1_M2`，归档到 `data/DELTA/Zero_load/N=3/`，并生成对应 MUL 长度图；Delta 汇总更新为 19 次记录。
- 更新 `script/plot_delta_mul_length.py`：为每张 DELTA MUL 长度图增加实际平均 MUL1 长度水平线，并在图例中标注具体平均值；已重新生成现有全部 19 张图。
- 调整平均 MUL1 长度线：改为蓝色实线并置于数据曲线最上层；已重新生成现有全部 19 张图。
- 整理新增的三模块 DELTA 无负载记录：将 `20260901_204308` 归档为 `N=3/M0_M1_M3`，将 `20260901_205014` 归档为 `N=3/M0_M2_M3`，将 `20260901_204633` 归档为 `N=3/M1_M2_M3`，补充条件、结果和文件路径，并为全部 22 次 DELTA 记录重新生成长度图。
- 更新 `data/DELTA/Zero_load/README.md`：总记录更新为 22 次，并补充 MUL 长度图中蓝色平均线、红色理论线和同步帧虚线的含义；记录三次新实验各存在 1 次 Delta 基础序号失配。
- 整理新增的四模块 DELTA 无负载记录：将 `20260901_205141` 归档为 `N=4/M0_M1_M2_M3`，补充条件、结果和文件路径，并为全部 23 次 DELTA 记录重新生成长度图；该记录存在 1 次 Delta 基础序号失配。
- 更新 `data/DELTA/Zero_load/README.md`：加入 N=4 结果并将汇总更新为 23 次记录。
- 根据无负载 DELTA 的三次单模块平均结果，记录 M1 为后续动态负载测试的优先模块：平均刷新率 `200.450 Hz`，用于建立稳定的动态测试基准；同时注明该选择不等同于传感器精度优于其他模块。
- 整理 M1 大面积动态负载实验的 3 次记录：归档到 `data/DELTA/Dynamic_load/M1/Large_area/Repeat_1..3/`，补充负载流程、阶段数据率、结果摘要和完整性状态，并新增该组实验的 `README.md`。
- 更新 `Data_Scalability.md`：记录 M1 动态测试已完成，三次平均数据率为 `0.5520 Mbit/s`、平均刷新率为 `199.765 Hz`；三次记录各有 1 次 Delta 基础序号失配。
- 整理 M1 小面积动态负载实验的 3 次记录：归档到 `data/DELTA/Dynamic_load/M1/Small_area_3x1.6cm/Repeat_1..3/`，记录 `3 × 1.6 cm` 负载流程、阶段数据率、结果摘要和完整性状态，并新增该组实验的 `README.md`。
- 更新 `Data_Scalability.md`：记录小面积测试平均数据率 `0.4517 Mbit/s`、平均刷新率 `200.301 Hz`，并与大面积测试进行对比。
- 整理新增 M1 高频滚动动态负载记录：使用棍子在两个 FSR 上来回滚动，30 s 记录得到 6008 个完整 MUL1，平均 USB 数据率 `0.887710 Mbit/s`，平均 MUL1 长度 `554.09 B`，所有 CRC、序号、丢帧和 Delta 基线检查均为 `0`；归档到 `data/DELTA/Dynamic_load/M1/High_frequency_rolling/Repeat_1/`。
- 更新 `plot_delta_mul_length.py`：为每张 DELTA MUL 长度图增加按活动模块数自适应的 FULL 理论 MUL1 帧长水平实线，使用当前四模块 MUL1 外壳公式 `40 + 1044N B/frame`；蓝色平均线继续保持在最上层。
- 重新生成全部 DELTA MUL 长度图，并将同步帧、理论零负载线、FULL 理论线和平均线统一写入各图例；同时在 `Data_Scalability.md` 中明确部分模块运行时固定的四个 module block header 不携带 ESKF 数据。
- 调整 `plot_delta_mul_length.py` 的图例位置：移到绘图区右侧的独立区域，避免遮挡 MUL1 曲线和水平参考线；全部 30 张 DELTA 图已重新生成。
- 再次调整 `plot_delta_mul_length.py` 的图例位置：将图例移到图形最下方并分两列排列，避免占用绘图区右侧；全部 30 张 DELTA 图已重新生成。
- 调整图表纵横比例：将绘图画布高度从 `5.5` 增加到 `7.0`，保留底部图例布局；全部 30 张 DELTA 图已重新生成。
- 降低所有 DELTA_SYNC 竖向虚线的透明度（alpha=`0.35`），减少其对数据曲线的干扰；新增 N=2 和 N=4 全部 FSR 同时全覆盖动态记录并按模块数归档。
- 更新 `Data_Scalability.md`：补充 N=2（4 个 FSR）和 N=4（8 个 FSR）同时全覆盖动态负载的实际 USB 数据率、MUL1 长度、刷新率、FULL 理论对比及完整性检查结果。
- Updated Figure 4.9 panel (a) so the dashed Identity reference line uses #7BB6BA; data, axes and all other series are unchanged.

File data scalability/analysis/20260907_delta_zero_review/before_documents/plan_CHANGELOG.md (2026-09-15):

# Changelog

## 2026-09-07 - FULL zero-load primary matrix complete after M012 retest and N=4

- Six new captures passed all main-window checks: three M012 retests and three N=4 runs. Independently verified 48,070 MUL1 packets, 168,243 ESKF frames and 192,280 module_log rows without new CRC/sequence/slot/log inconsistencies. The three full-capture CHECK results contain only a 1 B trailing recording fragment.
- Organized the retest under `FULL/N=3/200Hz/M0_M1_M2/Batch_20260907_004948_668301/Repeat_1..3/`, leaving the original three directories intact. N=4 uses `FULL/N=4/200Hz/M0_M1_M2_M3/Repeat_1..3/`. All 36 original files (208,073,646 bytes) passed pre/post-move SHA256 checks.
- Selected one complete three-window batch for each of all 15 configurations: the whole M012 retest batch replaces the original batch's position in the 45-run primary matrix. This is a batch-level choice, not a rate-based filter; the old slow M013 PASS run remains selected. All 48 recorded windows remain indexed, including the earlier failure and two supplemental M012 PASS windows.
- Added explicit eligibility versus primary-selection fields, a 45-run primary_matrix.csv, primary statistics, all-PASS supplemental statistics, all-run diagnostics and per-batch results. Totals: 47 main PASS / 1 CHECK, 16 recorded batches, 288 original files. The retest does not establish that all recordings were error-free.
- Evidence and selection manifest: `data scalability/analysis/20260907_full_completion_review/`. Updated data/FULL/N3/N4 catalogs; no schedule CSV, original data, firmware, GUI, report or figures changed. Completion covers FULL zero-load only; temporal repeats are not independent rebuilt Blocks.

## 2026-09-07 - N=3 FULL data organized with one failed main window

- All four three-slot configurations have three recorded windows: 12 captures, 11 main PASS and one main CHECK. The M0_M1_M2 first capture contains a CRC failure at 19.4723392 s and a 1024 B shortfall relative to the declared frame layout; a second sequence skipped by the live parser is recoverable as a complete CRC-valid packet from raw. Preserve the failed original and do not equate the two skipped sequence numbers with two physically lost packets.
- M0_M1_M3 Repeat 3 remains eligible despite its 199.123828 Hz rate. A 123 ms bridge enqueue gap and a separate 301.3735 ms PC completion gap are documented; do not remove the slower PASS run or infer SPI saturation from these timestamps alone.
- Organized all twelve captures into `data scalability/data/FULL/N=3/200Hz/<combination>/Repeat_1..3/`. All 72 originals (364,788,907 bytes) passed pre/post-move SHA256 verification; original metadata, states and bytes remain unchanged.
- The performance table uses eligible n=2 for M0_M1_M2 and n=3 for the other configurations. All-run diagnostic statistics retain each original n=3, including the failure for reliability assessment. Combined indexes contain 42 runs / 14 configurations / 252 files, with 41 eligible main windows and an explicit CHECK flag.
- Evidence, time analysis and mapping are in `data scalability/analysis/20260907_n3_full_review/`. One additional clean M0_M1_M2 window and the three N=4 windows remain necessary. No firmware, GUI, schedule CSV, historical data or report figures were changed.

## 2026-09-06 - N=2 FULL zero-load combinations completed

- Audited all six two-slot combinations, three consecutive captures each: 18/18 main windows PASS. Independently checked 144,212 complete MUL1 packets, 288,424 ESKF frames and 576,848 module_log rows; all complete packets are 2128 B, with no CRC/sequence/slot/log mismatch. Full windows: 2 PASS and 16 CHECK for a 1 B trailing recording fragment only.
- Organized into `data scalability/data/FULL/N=2/200Hz/<slot_combination>/Repeat_1..3/`. All 108 original files (393,046,829 bytes) passed pre/post-move SHA256 verification. Original metadata, content and embedded capture paths are preserved.
- Added combination mean ± sample SD and temporal n=3 / batch n=1, with evidence and mappings in `data scalability/analysis/20260906_n2_full_review/`. Combined active indexes now cover N=1 and N=2: 30 runs, 10 configurations and 180 original files.
- FULL zero-load coverage under the three-window recording workflow is 30/45 captures. N=3 four combinations and N=4 one combination remain; these temporal repeats do not complete three independent planned Blocks. The schedule CSV, report and historical data were not rewritten.

## 2026-09-06 - First completed FULL zero-load data classified

- Verified twelve completed N=1 / target 200 Hz / FULL / zero-load captures, three consecutive windows for each slot M0–M3. All main windows passed; independently checked 96,193 complete packets and 72,096 main-window packets. Full-capture CHECK is limited to a 1 B trailing recording fragment.
- Organized into `data scalability/data/FULL/N=1/200Hz/M0..M3/Repeat_1..3/`. Preserved all original content and metadata; all 72 files (159,181,044 bytes) passed pre/post-move SHA256 comparison. Run/file mapping and audit are in `data scalability/analysis/20260906_current_data_review/`.
- Added per-slot mean ± sample SD and temporal n=3, batch n=1. These windows do not mark three independent planned Blocks complete. N=2–4, DELTA and dynamic conditions remain outstanding in this snapshot; the schedule CSV and report were not rewritten.

## 2026-09-06 - Continuous parsing across recording boundaries

- Fixed Record clearing an incomplete MUL1 packet from the live framer, which could create false session sequence gaps and DELTA cache errors. Keep live parsing continuous and translate stream offsets into per-recording raw offsets.
- Audit start-crossing packets separately: retain only the bytes actually received within the file, exclude them from complete-packet rate/K/q and file-cache baselines, and preserve genuine sequence/CRC/module/parser errors. Rename the GUI lost label to missing MUL1 to distinguish packet-sequence estimates from physical scans.
- Read-only audit of the three current FULL/M0 captures found a complete CRC-valid packet split between the first and second raw files; all three main windows passed. Preserve the original data and summaries. Evidence: data scalability/analysis/20260906_record_boundary/ANALYSIS_CN.md.
- Validation: 20 recorder, 26 GUI/serial integration and 7 detector tests plus parser self-test passed, including FULL/DELTA boundaries in three consecutive captures and a genuine missing packet. Backup and deployment hashes: tmp/gui_stream_boundary_20260906. Restart the GUI to load the fix; no device firmware change.

## 2026-09-06 - Record x3

- Each GUI Record click now queues three consecutive captures under the same frozen configuration. Default: 3 x 40 s, each retaining its own 10 s prefix and separate files.
- Repeat is automatic 1/2/3 with a shared batch_id and unchanged Block. These are consecutive time windows under one setup, not independently rebuilt blocks or automatic physical reloading.
- Stop/disconnection/recording IO failure cancels remaining captures. Settings pauses display only. Preserve original plan repeat as planned_repeat; the existing single-run CSV is not automatically converted into a three-block completion record.
- Installed after 22 GUI/serial integration, 13 recorder and 7 detector tests plus parser self-test passed. No hardware capture or firmware flashing performed.

## 2026-09-06 - Simplified GUI and automatic slot detection

- Manual recordings detect recent successfully decoded slots/mode and freeze their expected set at Record; scheduled recordings keep the explicit planned set. Record does not resend mode/rate commands.
- Settings now uses human-condition radio selections and optional notes, with automatic/control-derived values read-only. Opening Settings pauses heatmap refresh only; Save/Cancel/window close resumes the latest frame while recording remains independent.
- Clearly label slot identity, local configuration, commanded target rate and measured packet rate. Protocol slot identity limitations were added to the current report 2.0 PDF.
- Installed after 14 GUI/serial integration, 7 detector and 13 recorder tests plus parser self-test passed; reviewed both main and settings renders. No real device capture or flashing was performed.

## 2026-09-06

- Final experiment scope is Data only; Power/Calibration retesting was removed at the user's request.
- Added the 142-row half-day schedule and 154-row extended Data schedule; no experimental measurements were generated.
- Implemented the variable-SPI PC GUI's configurable recording windows, schedule/metadata editor, per-run and main-window audits, complete received-byte capture, per-module status/K/q logs, and event markers.
- Default new recordings now use `docs/Final/data scalability/data`. The 88 existing runs (470 files, 503,037,879 bytes) were moved to `history/pre_variable_spi_20260906/data` and every original file SHA-256 verified. Original embedded paths are preserved and mapped by `path_map.csv`.
- Added explicit historical data-root arguments to figure/review tools; theoretical plots no longer require a nonempty measured-data directory.
- Legacy figure/review loaders reject schema_version>=2 explicitly until main-window statistics and run selection are adapted; they cannot silently substitute zero for missing legacy rates.
- Validation: 13 recorder backend tests, 8 GUI/serial integration tests, visual layout inspection, and the existing native protocol regression including 212 STM32-generated frame vectors passed. No real hardware capture or firmware flashing was performed.

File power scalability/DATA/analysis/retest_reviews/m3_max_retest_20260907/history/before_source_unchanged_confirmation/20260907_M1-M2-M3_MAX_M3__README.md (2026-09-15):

# Targeted M3 retest

User-identified M1-M2-M3 / MAX / M3, reported 2026-09-07.
See record.json for original photo provenance and unconfirmed metadata.
This is a separate partial retest; original acquisition and report are retained.
Source voltage is not provided, so the new source-to-module difference is null.

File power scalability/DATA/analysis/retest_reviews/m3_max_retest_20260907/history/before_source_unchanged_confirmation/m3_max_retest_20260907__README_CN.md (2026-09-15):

# M1＋M2＋M3 / MAX / M3 定向复测（2026-09-07登记）

这是用户提供的M3电压、电流复测。原记录及其44 mV压降保留，复测单独登记。
两张原始JPEG已按SHA256核验复制，未裁切或调整图像。

| 量 | 原主读数 | 复测主读数 | 复测MIN | 复测MAX | 主读数变化 |
|---|---:|---:|---:|---:|---:|
| M3电压 / V | 3.232 | 3.243 | 3.243 | 3.244 | +0.011 |
| M3电流 / mA | 19.721 | 19.263 | 19.25 | 19.41 | −0.458 |

照片读数经两次独立视觉核对，数值均在对应MIN/MAX范围内。保留仪表显示的小数位；
电流MIN/MAX的两位小数不补写成额外精度，也不能转换为SD或独立样本。

## 当前解释与待补信息

- 电压比原主读数高11 mV；电流低0.458 mA。两次记录条件是否完全一致仍待确认。
- 用户已澄清3.243 V、MIN3.243 V、MAX3.244 V均为照片中的M3模块端读数；
  SOURCE尚未重测。源端测点身份疑问已解决，新压降因缺少复测源端参考而留空。
  不把M3读数计作SOURCE，也不自动沿用旧SOURCE=3.276 V。
- 用户已确认复测前重新插入M3 connector。是否更换供电线未说明；
  质量/接触位置/负载分配是否相同仍未确认。将重新插入操作作为复测条件保存，
  不能仅由电压升高判定旧44 mV已确证为接头故障。
- 新读数本身不证明原44 mV是测量错误、接触故障，也不证明已无任何故障。
- 只有M3的两类读数，本次不是一条完整三模块重复实验。完整矩阵仍为30配置条件、
  64条原分支观测；另有这1组定向复测。未把原M1/M2电流拼接成新实测总电流。
- 未对两次M3观测计算重复性SD，未替换已发布报告或热图中的旧值。
- 登记日期来自本次对话；截图文件保存时间不作为已验证的实验起止时间。
- FULL/配置200 Hz/持续USB读取仅继承实验上下文，图片不独立验证频率及运行设置。

## 文件

- 原始复测记录和照片：../../../../../raw/canonical/power_experiment_records/targeted_retests/20260907_M1-M2-M3_MAX_M3
- original_vs_retest.csv：原记录与复测的逐量比较。
- intake_manifest.json：原文件保留、复制核验及记录哈希。
- history/before_retest_intake/：本次登记前的目录说明、变更日志和实验日志。

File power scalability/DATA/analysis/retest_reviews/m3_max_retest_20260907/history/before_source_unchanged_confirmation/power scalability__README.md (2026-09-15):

# Power scalability

> **M0空载电流复测已登记（2026-09-07）：** M0＋M1＋M2、ZERO 的M0电流为18.051 mA（MIN18.00、MAX18.08），用户确认模块电压仍3.241 V。[原值与复测对照](DATA/analysis/retest_reviews/m0_zero_retest_20260907/README_CN.md)。照片与用户确认来源分别保存，新的电压极值未提供；作为单模块补充记录保留，原矩阵、图表和报告未替换。

> **M3定向复测已登记（2026-09-07）：** M1＋M2＋M3、MAX 的M3复测电压3.243 V、电流19.263 mA，照片和MIN/MAX已独立保存。[原值与复测对照](DATA/analysis/retest_reviews/m3_max_retest_20260907/README_CN.md)。复测前已确认重新插入M3 connector；已澄清3.243 V为M3模块端、SOURCE尚未重测，加载一致性未确认，新压降留空；原44 mV、完整矩阵和报告2.3暂保持原记录。

> **2026-09-07报告2.3发布：** [当前报告](../main%202.3.pdf) 已纳入全部15组合的ZERO/MAX数据，更新7张Power图、方法、结果、讨论、附录、摘要和结论，共61页。[版本存档与校验](../report_versions/v2.3/manifest.json) 保留2.2基线和本轮来源。同一Word清单已更新，P05仍为部分完成。以下阶段性条目保留各自当时的状态，不再表示当前报告待合入；最新图表目录为 DATA/reference/report_v2_3_figures/。

本目录用于保存 Power Scalability 的实验设计、原始数据、分析脚本、派生结果和实验照片。

**最新完整汇总：[N=1–4全部空载／满负载结果](DATA/analysis/current/all_power_review_20260907/README_CN.md)。** 2026-09-07新增M0-M1-M3和M0-M2-M3的14张MAX电压/电流照片及10个温度点。两组电流合计58.631、58.279 mA；源端均3.275 V，输出侧功率估计192.016525、190.863725 mW。当前持续USB接收、FULL、配置200 Hz系列已覆盖15种非空组合×2种负载，即**30个配置条件、64条模块支路记录**。每个配置条件仍只有一组记录，没有新增同条件独立重复。全部配置的主读数、MIN/MAX、温度及来源保存在新汇总；主读数齐全不代表加载定义、故障监测、重复性或动态验证齐全。

| N | 每种负载组合数 | ZERO电流 / mA | MAX电流 / mA | ZERO输出侧功率估计 / mW | MAX输出侧功率估计 / mW |
|---|---:|---:|---:|---:|---:|
| 1 | 4 | 18.325 ± 0.111 | 20.009 ± 0.280 | 60.115 ± 0.370 | 65.644 ± 0.910 |
| 2 | 6 | 36.263 ± 0.265 | 39.629 ± 0.315 | 118.907 ± 0.848 | 129.891 ± 1.020 |
| 3 | 4 | 54.405 ± 0.337 | 58.964 ± 0.616 | 178.245 ± 1.091 | 193.136 ± 2.051 |
| 4 | 1 | 72.513 | 78.720 | 237.408 | 257.651 |

±为不同组合之间的样本SD，不是同条件重复SD；N=1为四个不同模块，N=4仅一个组合不能计算SD。功率为顺序支路读数之和乘顺序源端电压的估计，不含Teensy USB功耗和稳压器损耗。各组合MAX比ZERO电流高7.665%–10.973%，仅作描述性对照；新6组MAX的质量/接触面积/负载分配未给出，不能将差异全部归因于负载。原阻塞待机记录独立保留，本次没有补测阻塞状态。旧main 2.1不含这些补充数据；当前main 2.3已纳入。

双模块满负载子表：[N=2 MAX六组合电压、电流和温度](DATA/analysis/current/n2_max_review_20260907/README_CN.md)。四组新增电流合计分别39.357、39.335、39.719、40.016 mA；六组合合计电流39.629±0.315 mA（组合间样本SD），空载与满负载均覆盖6/6。

最新整体空载数据：[N=1–4 全部15组合统计](DATA/analysis/current/zero_power_review_20260907/README_CN.md)。2026-09-07补入M0-M1-M3与M0-M2-M3的三条支路电流和五个温度，ZERO电压、电流主读数、温度记录现覆盖15/15组合。N=3四组合合计电流54.405±0.337 mA（组合间样本SD）；各组合仍只有一组电流记录。主读数齐全不等于重复性、动态或热稳态验证完成。

最新补充统计：[N=2 ZERO六组合电流、功率估计和温度](DATA/analysis/current/n2_zero_review_20260907/README_CN.md)。2026-09-07新增四组合的电流/温度，原电压记录按组合关联；每组合一组电流记录，均值±SD描述组合间差异。这批数据已纳入当前main 2.3；旧2.1保留。

四个新增N=2组合及两个新增N=3组合的旧ZERO照片已移入各自`zero_load`目录，共34张，当前分析已按原SHA256核验并修复引用。原始转录保留当时路径，迁移映射及旧派生文件见[路径迁移记录](DATA/analysis/provenance/path_relocation_20260907/README_CN.md)。MAX新增照片和ZERO来源分别关联，原始读数及已发布main 2.1保持不变。

入口：[评估报告](Power_Scalability_Measurement_Plan_CN.md) · [全部图表及矢量版](DATA/analysis/figures/README.md) · [变更日志](CHANGELOG.md)。

## 目录结构

```text
power scalability/
├─ Power_Scalability_Measurement_Plan_CN.md
├─ Power_Scalability_Experiment_Log_CN.md
├─ CHANGELOG.md
├─ DATA/
│  ├─ power_raw.csv                      原始测量数据；分析脚本不会修改
│  ├─ power_experiment_records/          transmission/no_transmission 测试填写模板
│  └─ analysis/
│     ├─ figures/                        7 张图的 PNG/PDF/SVG、目录及校验清单
│     ├─ power_summary.csv               逐 run 派生指标
│     ├─ power_scaling.csv               按模块数汇总及拟合
│     ├─ branch_summary.csv              各模块支路电流、功耗和压降
│     ├─ thermal_summary.csv             温度汇总
│     ├─ anomaly_summary.csv             异常值与数据限制
│     └─ analysis_summary.json           完整机器可读分析结果
├─ script/
│  ├─ Main/
│  │  ├─ analyze_power_scalability.py    分析入口
│  │  ├─ power_figures.py                绘图与多格式导出
│  │  ├─ power_report.mplstyle           统一报告样式
│  │  └─ validate_power_figures.py       文件、尺寸、字体与来源校验
│  ├─ requirements.txt
│  └─ requirements-qa.txt
└─ photos/
   └─ n=1|n=2|n=3|n=4/                  各模块数量的实验照片
```

## 最新补充数据的复现

在本目录依次执行：

```powershell
python -B script/Main/summarize_voltage_review.py
python -B script/Main/summarize_n2_zero_20260907.py
python -B script/Main/summarize_zero_power_20260907.py
python -B script/Main/summarize_n2_max_20260907.py
python -B script/Main/summarize_all_power_20260907.py
```

这些入口生成日期命名的补充统计，不修改报告2.1的冻结分析。每份统计附有原始记录/照片哈希与已知限制。

## 历史分析的复现

在本目录执行：

```powershell
python -m pip install -r script/requirements.txt
python script/Main/analyze_power_scalability.py
```

以下旧入口只分析历史 `power_raw.csv` 中的 `200 Hz / FULL / ZERO` 数据，不包含顶部新增记录。`N=1` 使用四个模块的独立参考值，
`N=2` 现在汇总 M0+M1 与 M2+M3 两种组合；`N=3` 汇总 M0+M1+M2 与新增的 M1+M2+M3 两种组合；`N=4` 使用当前已有的多模块 run。所有派生结果覆盖写入 `DATA/analysis/`，
[DATA/raw/canonical/power_raw.csv](DATA/raw/canonical/power_raw.csv) 始终保持不变。

`DATA/rawdata/` 已按要求删除。当前分析仅使用 `DATA/raw/canonical/power_raw.csv`；
旧版 N=4 记录、M3 诊断记录和 M1+M2+M3 填写模板均不再保留。
其中 `host_usb_polling_state` 标记主机是否持续读取 USB；现有记录均为
`BLOCKED_STANDBY_NO_CONTINUOUS_USB_READ`，后续通路状态实验应标记为
`CONTINUOUS_USB_READ`。

新的 Power 实验填写文件统一保存在
`DATA/raw/canonical/power_experiment_records/`，按主机通信状态、模块数量、模块组合和负载分类。

图表统一宽 180 mm，输出 300 dpi 白底 PNG、嵌入字体的 PDF 和可编辑文本的 SVG；
放入报告或 PPT 时优先使用 PDF/SVG。图中的文字均为英文。

当前工作区已配置 `.venv-power-plots`，从项目根目录可直接运行：

```powershell
& .\.venv-power-plots\Scripts\python.exe 'docs/Final/power scalability/script/Main/analyze_power_scalability.py'
```

文件校验在本目录执行：

```powershell
python -m pip install -r script/requirements-qa.txt
python script/Main/validate_power_figures.py
```

绘图环境版本和源文件 SHA-256 保存在 [figure_manifest.json](DATA/analysis/figures/figure_manifest.json)，
检查结果保存在 [figure_validation.json](DATA/analysis/figures/figure_validation.json)。

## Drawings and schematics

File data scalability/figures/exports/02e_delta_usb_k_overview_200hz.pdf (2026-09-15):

(a)

(b)

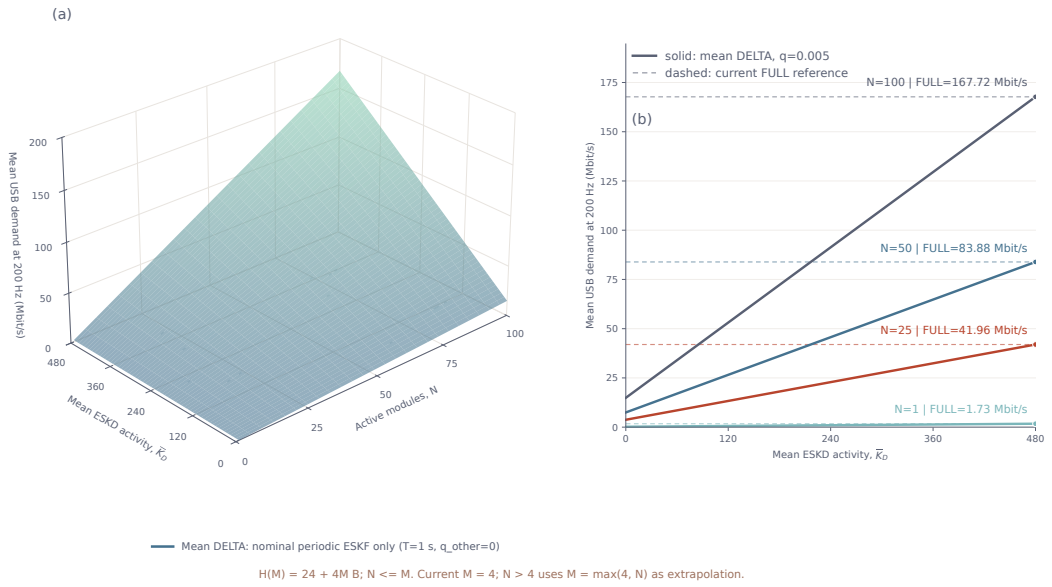
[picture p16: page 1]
Active modules, N; N=1 | FULL=1.73 Mbit/s; N=25 | FULL=41.96 Mbit/s; N=50 | FULL=83.88 Mbit/s; N=100 | FULL=167.72 Mbit/s

solid: mean DELTA, q=0.005
dashed: current FULL reference

Mean USB demand at 200 Hz (Mbit/s)

Mean ESKD activity, KD

Mean DELTA: nominal periodic ESKF only (T=1 s, q_other=0)

H(M) = 24 + 4M B; N <= M. Current M = 4; N > 4 uses M = max(4, N) as extrapolation.

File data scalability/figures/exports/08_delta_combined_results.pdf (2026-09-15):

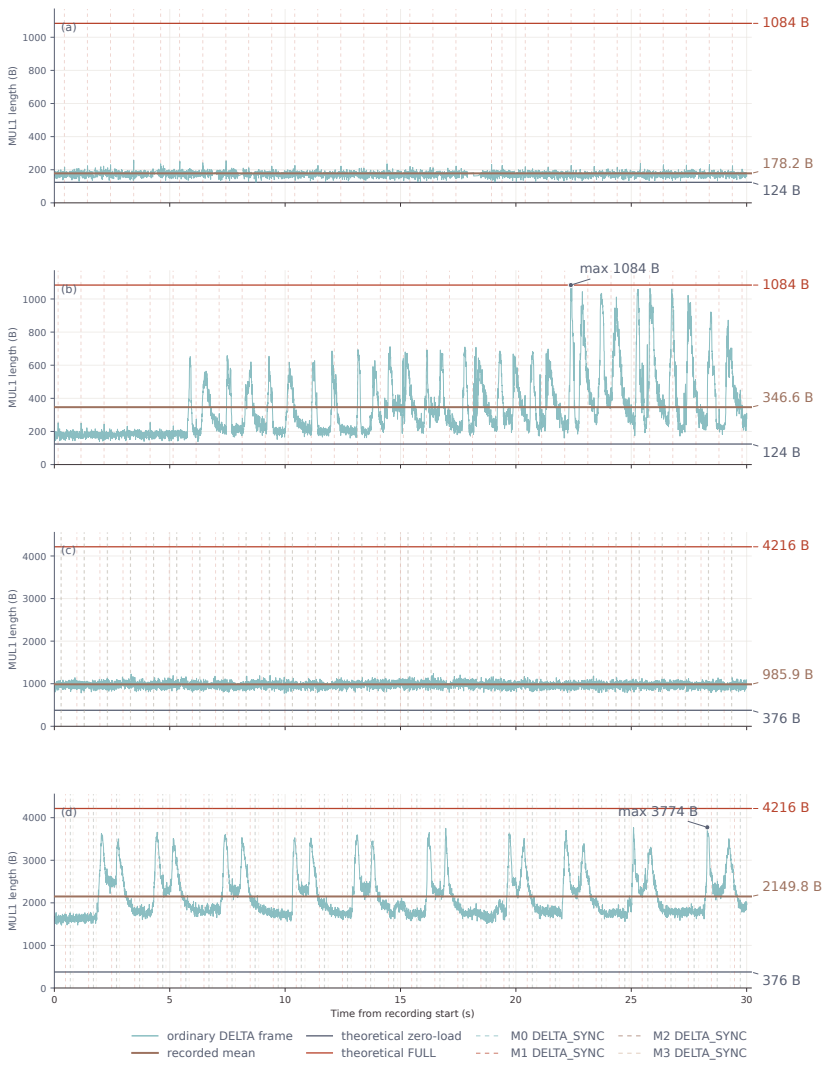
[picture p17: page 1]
MUL1 length (B); max 1084 B; max 3774 B; M0 DELTA_SYNC M1 DELTA_SYNC; M2 DELTA_SYNC M3 DELTA_SYNC

Time from recording start (s)
theoretical zero-load
theoretical FULL

ordinary DELTA frame
recorded mean

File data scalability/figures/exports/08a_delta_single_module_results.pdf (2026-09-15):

1084 B

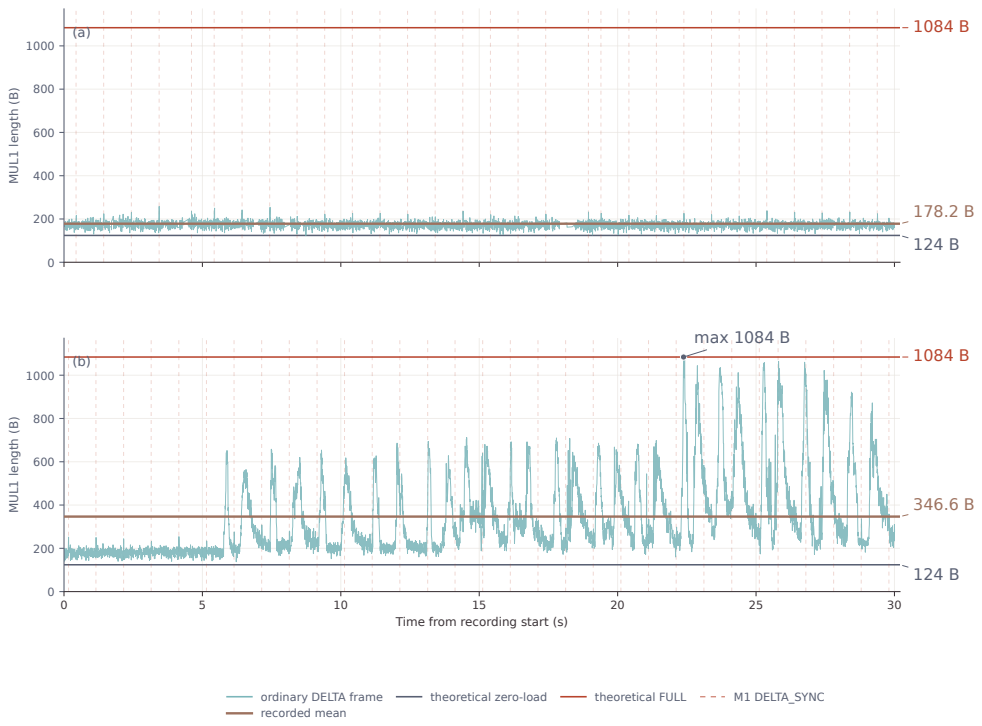
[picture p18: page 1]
MUL1 length (B); max 1084 B; theoretical zero-load; theoretical FULL; M1 DELTA_SYNC

Time from recording start (s)

ordinary DELTA frame
recorded mean

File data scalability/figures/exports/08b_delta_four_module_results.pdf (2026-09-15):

4216 B

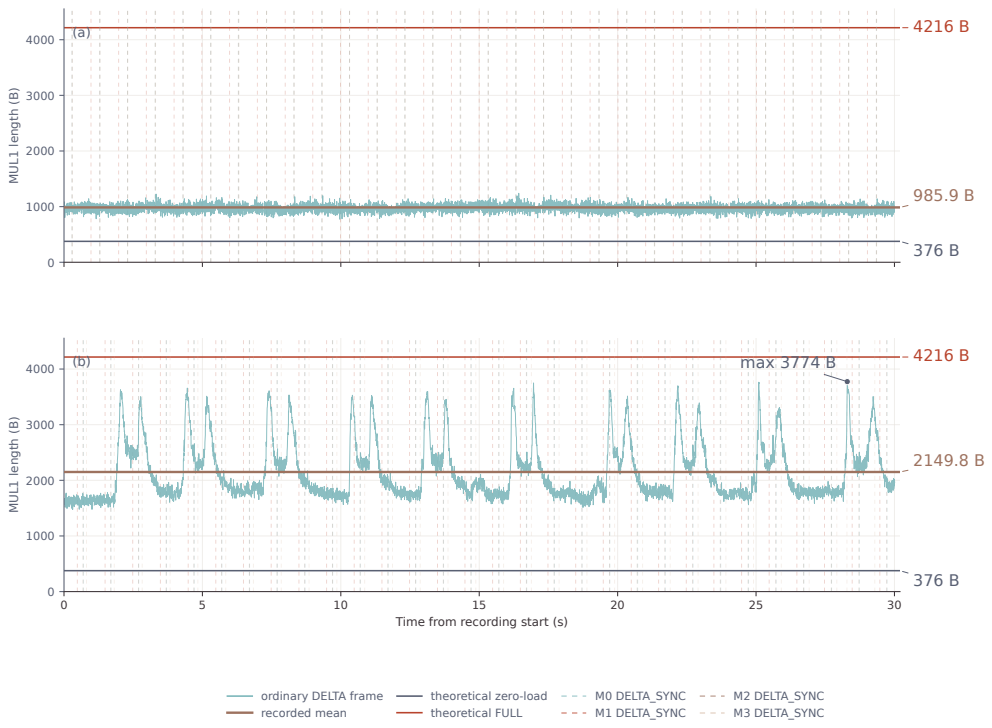
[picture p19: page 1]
MUL1 length (B); max 3774 B; M0 DELTA_SYNC M1 DELTA_SYNC; M2 DELTA_SYNC M3 DELTA_SYNC

Time from recording start (s)

ordinary DELTA frame
recorded mean

theoretical zero-load
theoretical FULL

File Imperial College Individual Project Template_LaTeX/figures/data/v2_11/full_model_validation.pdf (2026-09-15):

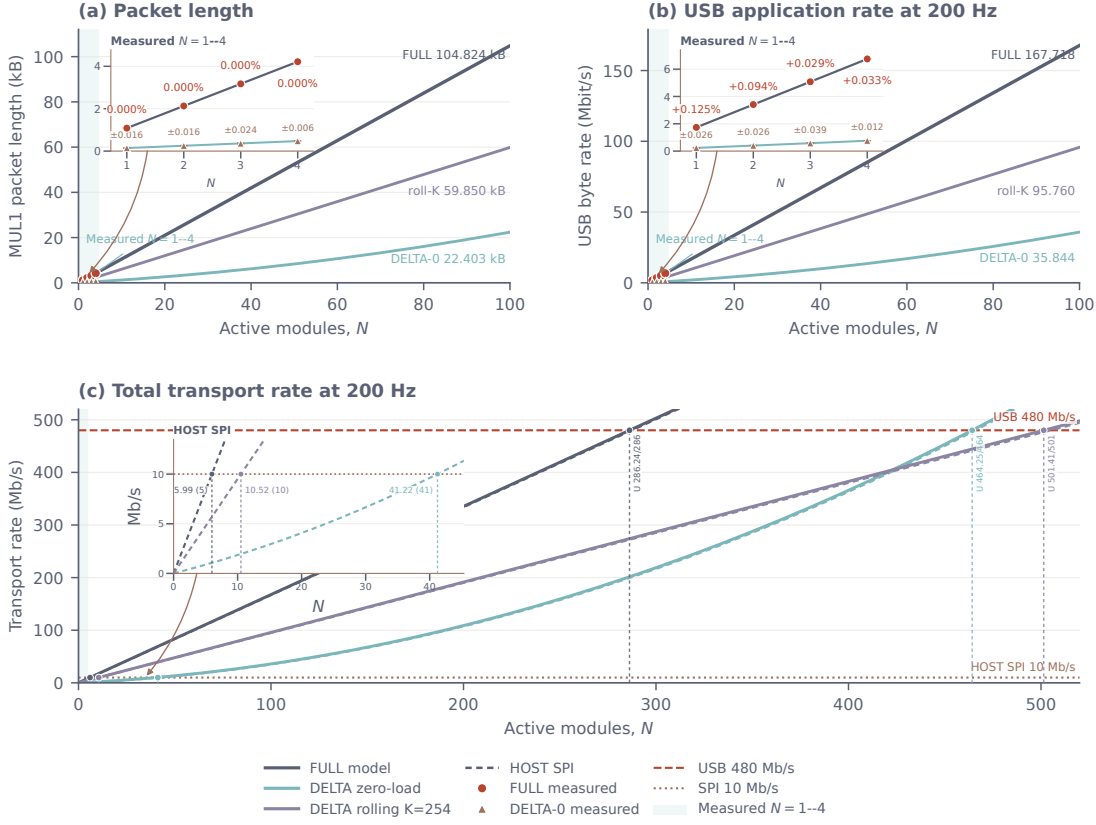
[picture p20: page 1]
Active modules, N; Measured N = 1--4; FULL 104.824 kB; DELTA-0 22.403 kB; roll-K 59.850 kB; (a) Packet length; FULL 167.718; DELTA-0 35.844; roll-K 95.760; USB 480 Mb/s; HOST SPI; HOST SPI FULL measured DELTA-0 measured; USB 480 Mb/s SPI 10 Mb/s Measured N = 1--4

(b) USB application rate at 200 Hz

MUL1 packet length (kB)

USB byte rate (Mbit/s)

(c) Total transport rate at 200 Hz

Transport rate (Mb/s)

HOST SPI 10 Mb/s

FULL model
DELTA zero-load
DELTA rolling K=254

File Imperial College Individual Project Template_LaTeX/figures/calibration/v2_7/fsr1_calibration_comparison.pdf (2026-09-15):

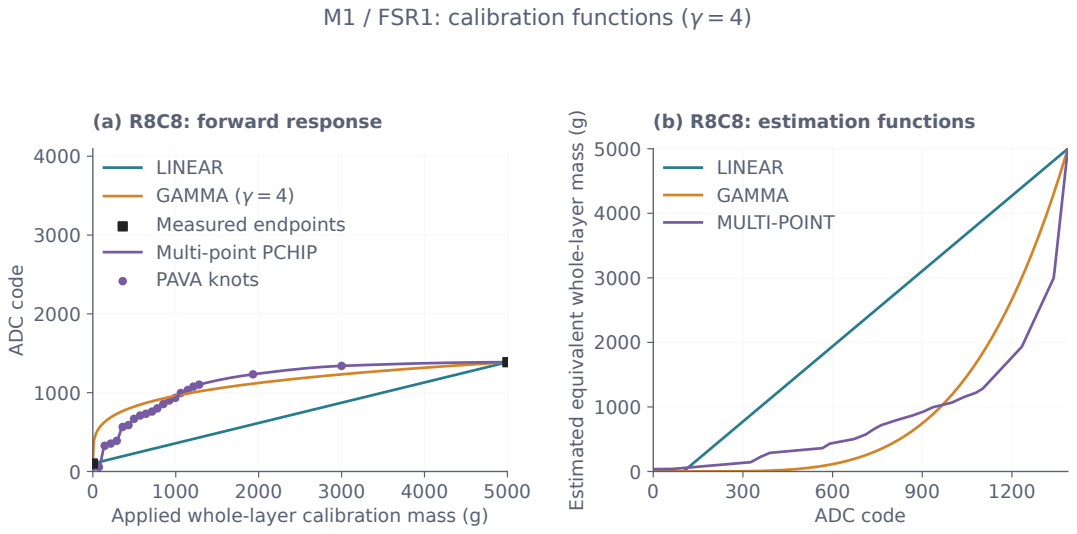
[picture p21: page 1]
ADC code; (a) R8C8: forward response; (b) R8C8: estimation functions; LINEAR GAMMA MULTI-POINT; M1 / FSR1: calibration functions (γ = 4)

Estimated equivalent whole-layer mass (g)

LINEAR GAMMA (γ = 4) Measured endpoints

Multi-point PCHIP PAVA knots

Applied whole-layer calibration mass (g)

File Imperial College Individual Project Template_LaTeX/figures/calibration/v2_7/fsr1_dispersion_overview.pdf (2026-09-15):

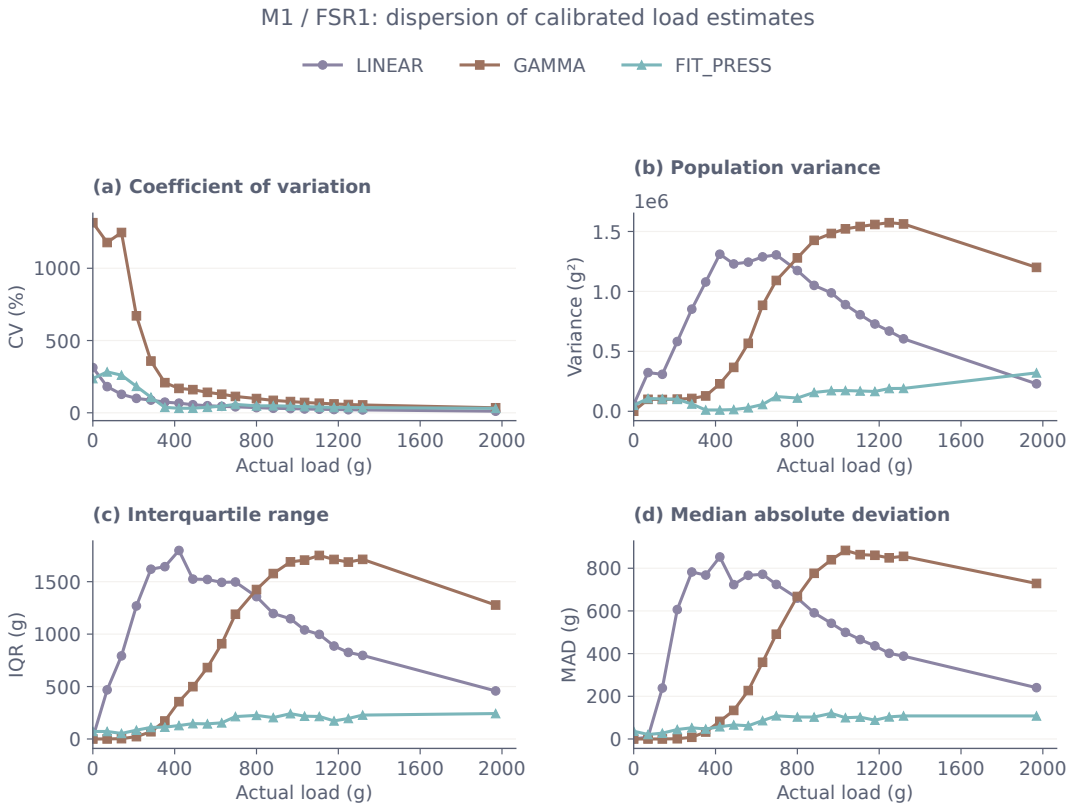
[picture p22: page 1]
Actual load (g); Variance (g²); (b) Population variance; IQR (g); (c) Interquartile range; MAD (g); LINEAR; GAMMA; FIT_PRESS

M1 / FSR1: dispersion of calibrated load estimates

(a) Coefficient of variation

(d) Median absolute deviation

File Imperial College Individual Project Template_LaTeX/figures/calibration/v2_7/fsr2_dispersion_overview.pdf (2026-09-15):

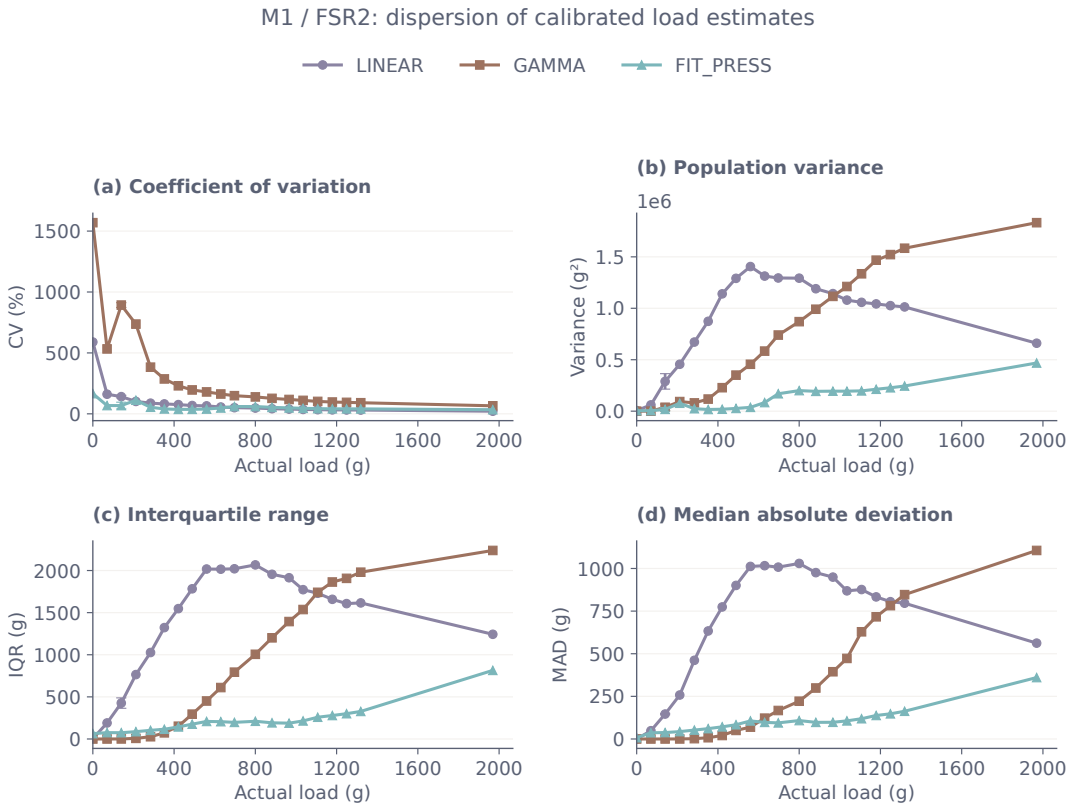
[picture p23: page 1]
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

M1 / FSR2: dispersion of calibrated load estimates

(a) Coefficient of variation

(d) Median absolute deviation

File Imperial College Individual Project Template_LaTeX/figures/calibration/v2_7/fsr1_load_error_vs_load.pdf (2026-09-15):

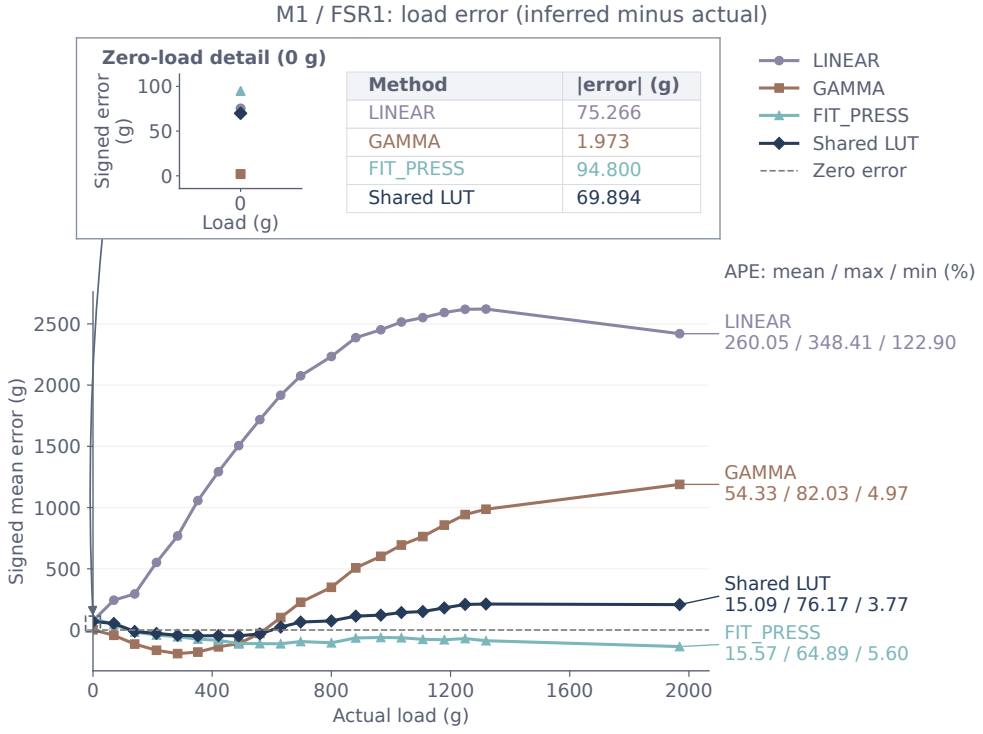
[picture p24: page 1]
Actual load (g); FIT_PRESS 15.57 / 64.89 / 5.60; Shared LUT 15.09 / 76.17 / 3.77; GAMMA 54.33 / 82.03 / 4.97; LINEAR 260.05 / 348.41 / 122.90; LINEAR GAMMA FIT_PRESS Shared LUT Zero error; Shared LUT; 0 Load (g); Signed error

M1 / FSR1: load error (inferred minus actual)

Zero-load detail (0 g)

Method | |error| (g)
LINEAR | 75.266
GAMMA | 1.973
FIT_PRESS | 94.800

APE: mean / max / min (%)

Signed mean error (g)

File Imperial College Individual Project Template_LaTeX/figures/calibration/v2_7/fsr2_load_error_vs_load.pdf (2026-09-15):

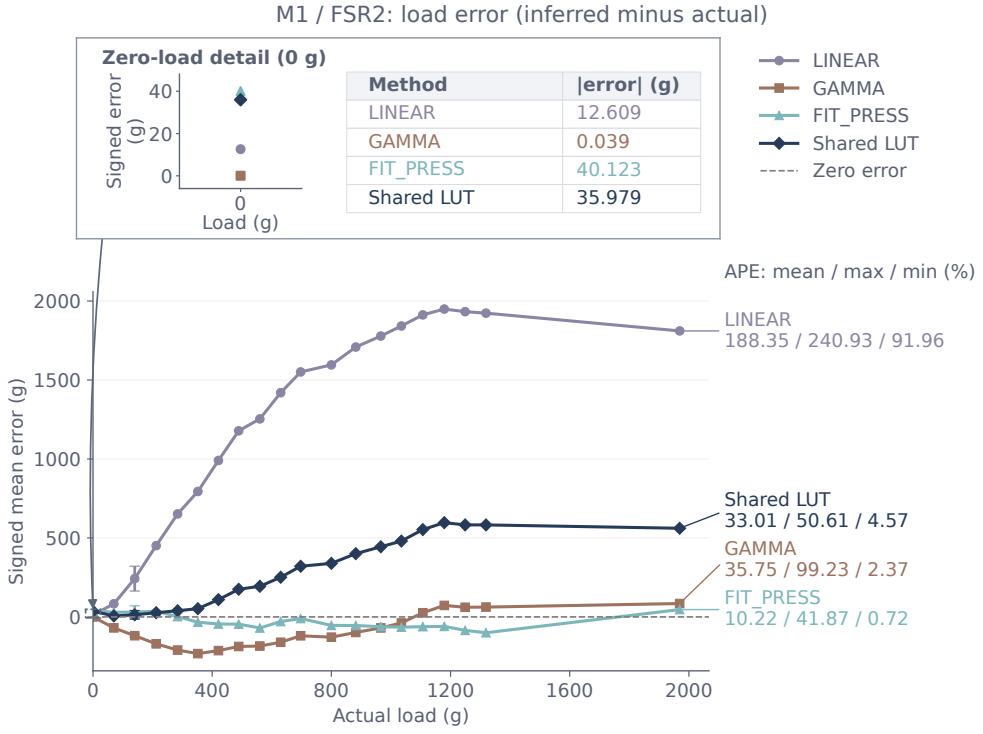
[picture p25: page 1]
Actual load (g); FIT_PRESS 10.22 / 41.87 / 0.72; GAMMA 35.75 / 99.23 / 2.37; Shared LUT 33.01 / 50.61 / 4.57; LINEAR 188.35 / 240.93 / 91.96; LINEAR GAMMA FIT_PRESS Shared LUT Zero error; Method; |error| (g); LINEAR; GAMMA; FIT_PRESS; Shared LUT; 0 Load (g); Signed error

M1 / FSR2: load error (inferred minus actual)

Zero-load detail (0 g)

APE: mean / max / min (%)

Signed mean error (g)

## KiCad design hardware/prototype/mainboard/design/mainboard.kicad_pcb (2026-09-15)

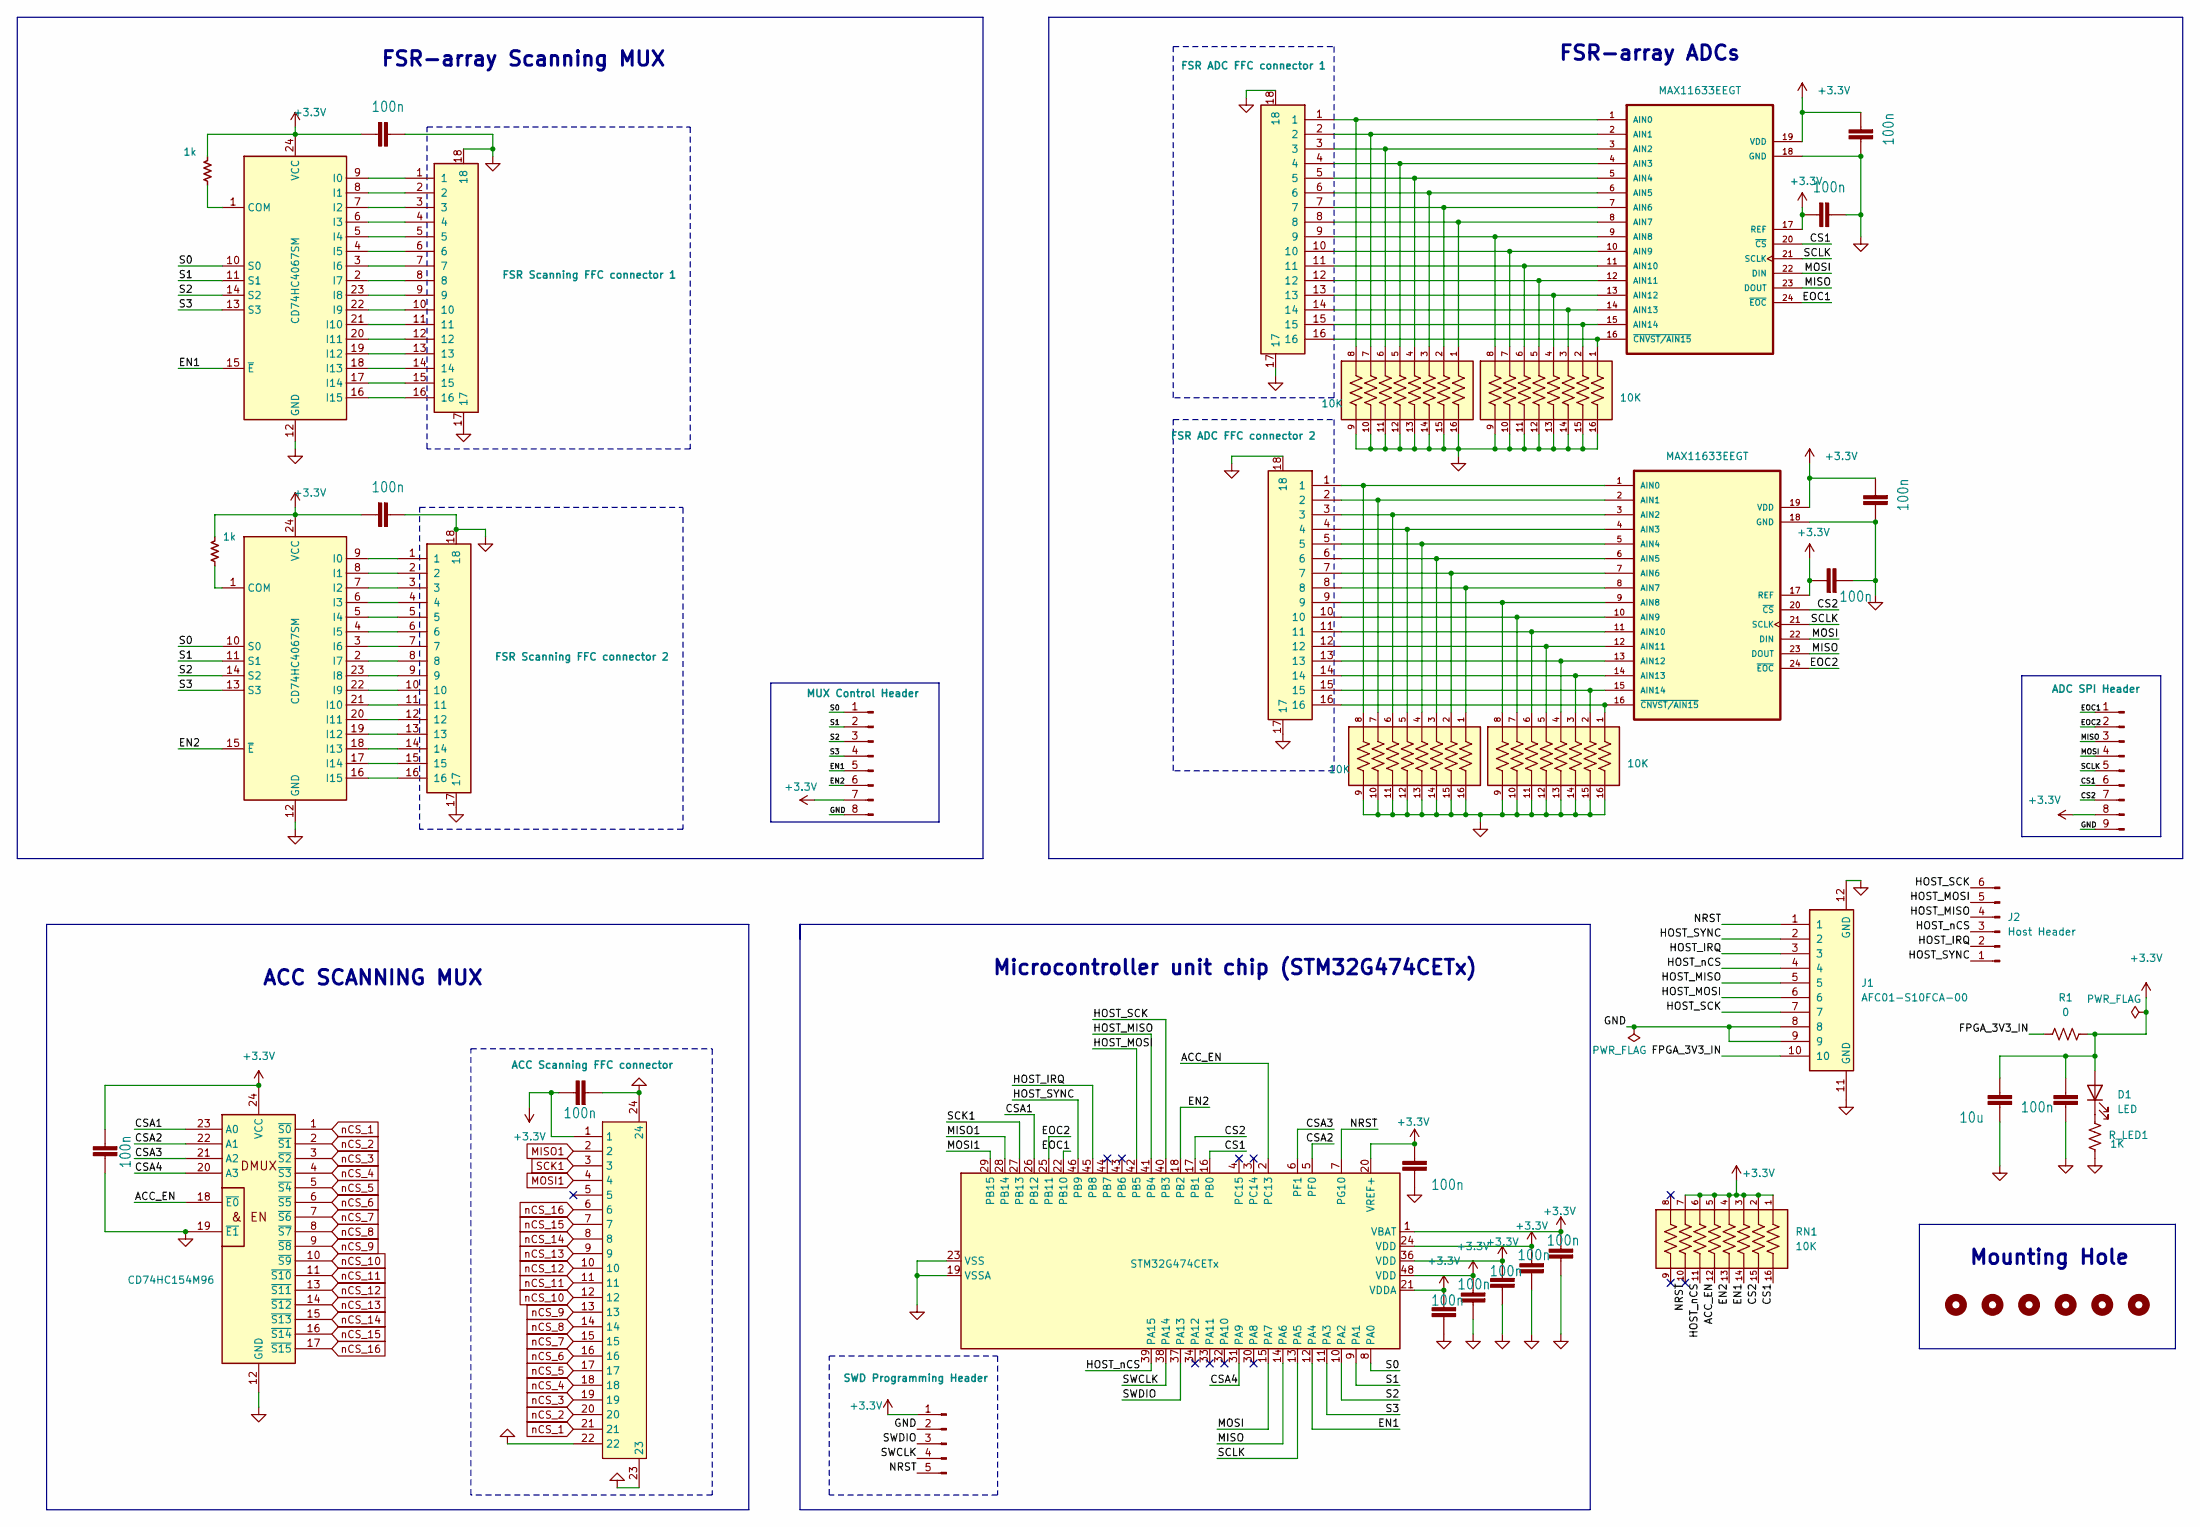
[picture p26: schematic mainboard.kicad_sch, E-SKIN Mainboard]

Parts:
ACC_DEC1: CD74HC154M96
ACC_FPC1: ACC Scanning FFC connector; AFC01-S22FCA-00; LCSC Part C262668
ADC_SPI_HDR1: ADC SPI Header; PinHeader_1x09_P1.27mm_Vertical
C1, C2, C5, C6, C7, C8, C9, C10, C11, C12, C13, C14, C15, C16, C17: 100n; C_0603_1608Metric
C18: 10u; C_0603_1608Metric
COL_ADC1, COL_ADC2: MAX11633EEGT
COL_FPC1: FSR ADC FFC connector 1; AFC01-S16FCA-00
COL_FPC2: FSR ADC FFC connector 2; AFC01-S16FCA-00
D1: LED; LED_0603_1608Metric
J1: AFC01-S10FCA-00
J2: Host Header; PinHeader_1x06_P1.27mm_Vertical
MCU1: STM32G474CETx; LQFP-48_7x7mm_P0.5mm
MOUNT1, MOUNT2, MOUNT3, MOUNT4, MOUNT5, MOUNT6: M3 Mounting Hole; MountingHole_3.2mm_M3
MUX_CTRL_HDR1: MUX Control Header; PinHeader_1x08_P1.27mm_Vertical
R1: 0; R_0603_1608Metric
RN1: 10K; EXB2HV103JV; PARTREV 1-Mar-20
RN2, RN3, RN4, RN5: 10K; Res-array; PARTREV 1-Mar-20
ROW_FPC1: FSR Scanning FFC connector 1; AFC01-S16FCA-00
ROW_FPC2: FSR Scanning FFC connector 2; AFC01-S16FCA-00
ROW_MUX1, ROW_MUX2: CD74HC4067SM; SSOP-24_5.3x8.2mm_P0.65mm
R_LED1: 1K; R_0603_1608Metric
R_MUX1_COM1, R_MUX2_COM1: 1k; R_0603_1608Metric
SWD_HDR1: SWD Programming Header; PinHeader_1x05_P1.27mm_Vertical

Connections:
+3.3V: ACC_DEC1.24 (VCC), ACC_FPC1.1, ADC_SPI_HDR1.8, C1.2, C2.1, C5.2, C6.2, C7.2, C8.1, C9.2, C10.2, C11.2, C12.2, C13.2, C14.2, C15.2, C16.2, C17.2, C18.2, COL_ADC1.17 (REF), COL_ADC1.19 (VDD), COL_ADC2.17 (REF), COL_ADC2.19 (VDD), D1.2 (A), MCU1.1 (VBAT), MCU1.20 (VREF+), MCU1.21 (VDDA), MCU1.24 (VDD), MCU1.36 (VDD), MCU1.48 (VDD), MUX_CTRL_HDR1.7, R1.2, RN1.1, RN1.2, RN1.3, RN1.4, RN1.5, RN1.6, RN1.7, ROW_MUX1.24 (VCC), ROW_MUX2.24 (VCC), R_MUX1_COM1.1, R_MUX2_COM1.1, SWD_HDR1.1; also elsewhere on the board
/ACC_EN: ACC_DEC1.18 (~E0), MCU1.2 (PC13), RN1.12; also elsewhere on the board
/CS1: ADC_SPI_HDR1.6, COL_ADC1.20 (~CS), MCU1.16 (PB0), RN1.16; also elsewhere on the board
/CS2: ADC_SPI_HDR1.7, COL_ADC2.20 (~CS), MCU1.17 (PB1), RN1.15; also elsewhere on the board
/CSA1: ACC_DEC1.23 (A0), MCU1.26 (PB12); also elsewhere on the board
/CSA2: ACC_DEC1.22 (A1), MCU1.5 (PF0); also elsewhere on the board
/CSA3: ACC_DEC1.21 (A2), MCU1.6 (PF1); also elsewhere on the board
/CSA4: ACC_DEC1.20 (A3), MCU1.31 (PA9); also elsewhere on the board
/EN1: MCU1.12 (PA4), MUX_CTRL_HDR1.5, RN1.14, ROW_MUX1.15 (~E); also elsewhere on the board
/EN2: MCU1.18 (PB2), MUX_CTRL_HDR1.6, RN1.13, ROW_MUX2.15 (~E); also elsewhere on the board
/EOC1: ADC_SPI_HDR1.1, COL_ADC1.24 (~EOC), MCU1.22 (PB10); also elsewhere on the board
/EOC2: ADC_SPI_HDR1.2, COL_ADC2.24 (~EOC), MCU1.25 (PB11); also elsewhere on the board
/FPGA_3V3_IN: J1.10, R1.1
/HOST_IRQ: J1.3, J2.2, MCU1.45 (PB8); also elsewhere on the board
/HOST_MISO: J1.5, J2.4, MCU1.41 (PB4); also elsewhere on the board
/HOST_MOSI: J1.6, J2.5, MCU1.42 (PB5); also elsewhere on the board
/HOST_SCK: J1.7, J2.6, MCU1.40 (PB3); also elsewhere on the board
/HOST_SYNC: J1.2, J2.1, MCU1.46 (PB9); also elsewhere on the board
/HOST_nCS: J1.4, J2.3, MCU1.39 (PA15), RN1.11; also elsewhere on the board
/MISO: ADC_SPI_HDR1.3, COL_ADC1.23 (DOUT), COL_ADC2.23 (DOUT), MCU1.14 (PA6); also elsewhere on the board
/MOSI: ADC_SPI_HDR1.4, COL_ADC1.22 (DIN), COL_ADC2.22 (DIN), MCU1.15 (PA7); also elsewhere on the board
/NRST: J1.1, MCU1.7 (PG10), RN1.10, SWD_HDR1.5; also elsewhere on the board
/S0: MCU1.8 (PA0), MUX_CTRL_HDR1.1, ROW_MUX1.10 (S0), ROW_MUX2.10 (S0); also elsewhere on the board
/S1: MCU1.9 (PA1), MUX_CTRL_HDR1.2, ROW_MUX1.11 (S1), ROW_MUX2.11 (S1); also elsewhere on the board
/S2: MCU1.10 (PA2), MUX_CTRL_HDR1.3, ROW_MUX1.14 (S2), ROW_MUX2.14 (S2); also elsewhere on the board
/S3: MCU1.11 (PA3), MUX_CTRL_HDR1.4, ROW_MUX1.13 (S3), ROW_MUX2.13 (S3); also elsewhere on the board
/SCLK: ADC_SPI_HDR1.5, COL_ADC1.21 (SCLK), COL_ADC2.21 (SCLK), MCU1.13 (PA5); also elsewhere on the board
/SWCLK: MCU1.38 (PA14), SWD_HDR1.4; also elsewhere on the board
/SWDIO: MCU1.37 (PA13), SWD_HDR1.3; also elsewhere on the board
GND: ACC_DEC1.12 (GND), ACC_DEC1.19 (~E1), ACC_FPC1.22, ACC_FPC1.23, ACC_FPC1.24, ADC_SPI_HDR1.9, C1.1, C2.2, C5.1, C6.1, C7.1, C8.2, C9.1, C10.1, C11.1, C12.1, C13.1, C14.1, C15.1, C16.1, C17.1, C18.1, COL_ADC1.18 (GND), COL_ADC2.18 (GND), COL_FPC1.17, COL_FPC1.18, COL_FPC2.17, COL_FPC2.18, J1.8, J1.9, J1.11 (GND), J1.12 (GND), MCU1.19 (VSSA), MCU1.23 (VSS), MCU1.35 (VSS), MCU1.47 (VSS), MUX_CTRL_HDR1.8, RN2.9, RN2.10, RN2.11, RN2.12, RN2.13, RN2.14, RN2.15, RN2.16, RN3.9, RN3.10, RN3.11, RN3.12, RN3.13, RN3.14, RN3.15, RN3.16, RN4.9, RN4.10, RN4.11, RN4.12, RN4.13, RN4.14, RN4.15, RN4.16, RN5.9, RN5.10, RN5.11, RN5.12, RN5.13, RN5.14, RN5.15, RN5.16, ROW_FPC1.17, ROW_FPC1.18, ROW_FPC2.17, ROW_FPC2.18, ROW_MUX1.12 (GND), ROW_MUX2.12 (GND), R_LED1.2, SWD_HDR1.2; also elsewhere on the board
MISO1: ACC_FPC1.2; also elsewhere on the board
MOSI1: ACC_FPC1.4; also elsewhere on the board
unnamed: COL_ADC1.1 (AIN0), COL_FPC1.1, RN3.8
unnamed: COL_ADC1.2 (AIN1), COL_FPC1.2, RN3.7
unnamed: COL_ADC1.3 (AIN2), COL_FPC1.3, RN3.6
unnamed: COL_ADC1.4 (AIN3), COL_FPC1.4, RN3.5
unnamed: COL_ADC1.5 (AIN4), COL_FPC1.5, RN3.4
unnamed: COL_ADC1.6 (AIN5), COL_FPC1.6, RN3.3
unnamed: COL_ADC1.7 (AIN6), COL_FPC1.7, RN3.2
unnamed: COL_ADC1.8 (AIN7), COL_FPC1.8, RN3.1
unnamed: COL_ADC1.9 (AIN8), COL_FPC1.9, RN2.8
unnamed: COL_ADC1.10 (AIN9), COL_FPC1.10, RN2.7
unnamed: COL_ADC1.11 (AIN10), COL_FPC1.11, RN2.6
unnamed: COL_ADC1.12 (AIN11), COL_FPC1.12, RN2.5
unnamed: COL_ADC1.13 (AIN12), COL_FPC1.13, RN2.4
unnamed: COL_ADC1.14 (AIN13), COL_FPC1.14, RN2.3
unnamed: COL_ADC1.15 (AIN14), COL_FPC1.15, RN2.2
unnamed: COL_ADC1.16 (~CNVST/AIN15), COL_FPC1.16, RN2.1
unnamed: COL_ADC2.1 (AIN0), COL_FPC2.1, RN4.8
unnamed: COL_ADC2.2 (AIN1), COL_FPC2.2, RN4.7
unnamed: COL_ADC2.3 (AIN2), COL_FPC2.3, RN4.6
unnamed: COL_ADC2.4 (AIN3), COL_FPC2.4, RN4.5
unnamed: COL_ADC2.5 (AIN4), COL_FPC2.5, RN4.4
unnamed: COL_ADC2.6 (AIN5), COL_FPC2.6, RN4.3
unnamed: COL_ADC2.7 (AIN6), COL_FPC2.7, RN4.2
unnamed: COL_ADC2.8 (AIN7), COL_FPC2.8, RN4.1
unnamed: COL_ADC2.9 (AIN8), COL_FPC2.9, RN5.8
unnamed: COL_ADC2.10 (AIN9), COL_FPC2.10, RN5.7
unnamed: COL_ADC2.11 (AIN10), COL_FPC2.11, RN5.6
unnamed: COL_ADC2.12 (AIN11), COL_FPC2.12, RN5.5
unnamed: COL_ADC2.13 (AIN12), COL_FPC2.13, RN5.4
unnamed: COL_ADC2.14 (AIN13), COL_FPC2.14, RN5.3
unnamed: COL_ADC2.15 (AIN14), COL_FPC2.15, RN5.2
unnamed: COL_ADC2.16 (~CNVST/AIN15), COL_FPC2.16, RN5.1
unnamed: D1.1 (K), R_LED1.1
unnamed: ROW_MUX1.1 (COM), R_MUX1_COM1.2
unnamed: ROW_FPC1.1, ROW_MUX1.9 (I0)
unnamed: ROW_FPC1.2, ROW_MUX1.8 (I1)
unnamed: ROW_FPC1.3, ROW_MUX1.7 (I2)
unnamed: ROW_FPC1.4, ROW_MUX1.6 (I3)
unnamed: ROW_FPC1.5, ROW_MUX1.5 (I4)
unnamed: ROW_FPC1.6, ROW_MUX1.4 (I5)
unnamed: ROW_FPC1.7, ROW_MUX1.3 (I6)
unnamed: ROW_FPC1.8, ROW_MUX1.2 (I7)
unnamed: ROW_FPC1.9, ROW_MUX1.23 (I8)
unnamed: ROW_FPC1.10, ROW_MUX1.22 (I9)
unnamed: ROW_FPC1.11, ROW_MUX1.21 (I10)
unnamed: ROW_FPC1.12, ROW_MUX1.20 (I11)
unnamed: ROW_FPC1.13, ROW_MUX1.19 (I12)
unnamed: ROW_FPC1.14, ROW_MUX1.18 (I13)
unnamed: ROW_FPC1.15, ROW_MUX1.17 (I14)
unnamed: ROW_FPC1.16, ROW_MUX1.16 (I15)
unnamed: ROW_MUX2.1 (COM), R_MUX2_COM1.2
unnamed: ROW_FPC2.1, ROW_MUX2.9 (I0)
unnamed: ROW_FPC2.2, ROW_MUX2.8 (I1)
unnamed: ROW_FPC2.3, ROW_MUX2.7 (I2)
unnamed: ROW_FPC2.4, ROW_MUX2.6 (I3)
unnamed: ROW_FPC2.5, ROW_MUX2.5 (I4)
unnamed: ROW_FPC2.6, ROW_MUX2.4 (I5)
unnamed: ROW_FPC2.7, ROW_MUX2.3 (I6)
unnamed: ROW_FPC2.8, ROW_MUX2.2 (I7)
unnamed: ROW_FPC2.9, ROW_MUX2.23 (I8)
unnamed: ROW_FPC2.10, ROW_MUX2.22 (I9)
unnamed: ROW_FPC2.11, ROW_MUX2.21 (I10)
unnamed: ROW_FPC2.12, ROW_MUX2.20 (I11)
unnamed: ROW_FPC2.13, ROW_MUX2.19 (I12)
unnamed: ROW_FPC2.14, ROW_MUX2.18 (I13)
unnamed: ROW_FPC2.15, ROW_MUX2.17 (I14)
unnamed: ROW_FPC2.16, ROW_MUX2.16 (I15)
SCK1: ACC_FPC1.3; also elsewhere on the board
nCS_1: ACC_DEC1.1 (~S0), ACC_FPC1.21
nCS_2: ACC_DEC1.2 (~S1), ACC_FPC1.20
nCS_3: ACC_DEC1.3 (~S2), ACC_FPC1.19
nCS_4: ACC_DEC1.4 (~S3), ACC_FPC1.18
nCS_5: ACC_DEC1.5 (~S4), ACC_FPC1.17
nCS_6: ACC_DEC1.6 (~S5), ACC_FPC1.16
nCS_7: ACC_DEC1.7 (~S6), ACC_FPC1.15
nCS_8: ACC_DEC1.8 (~S7), ACC_FPC1.14
nCS_9: ACC_DEC1.9 (~S8), ACC_FPC1.13
nCS_10: ACC_DEC1.10 (~S9), ACC_FPC1.12
nCS_11: ACC_DEC1.11 (~S10), ACC_FPC1.11
nCS_12: ACC_DEC1.13 (~S11), ACC_FPC1.10
nCS_13: ACC_DEC1.14 (~S12), ACC_FPC1.9
nCS_14: ACC_DEC1.15 (~S13), ACC_FPC1.8
nCS_15: ACC_DEC1.16 (~S14), ACC_FPC1.7
nCS_16: ACC_DEC1.17 (~S15), ACC_FPC1.6

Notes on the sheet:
FSR-array ADCs
ACC SCANNING MUX
Microcontroller unit chip (STM32G474CETx)
FSR-array Scanning MUX
Mounting Hole

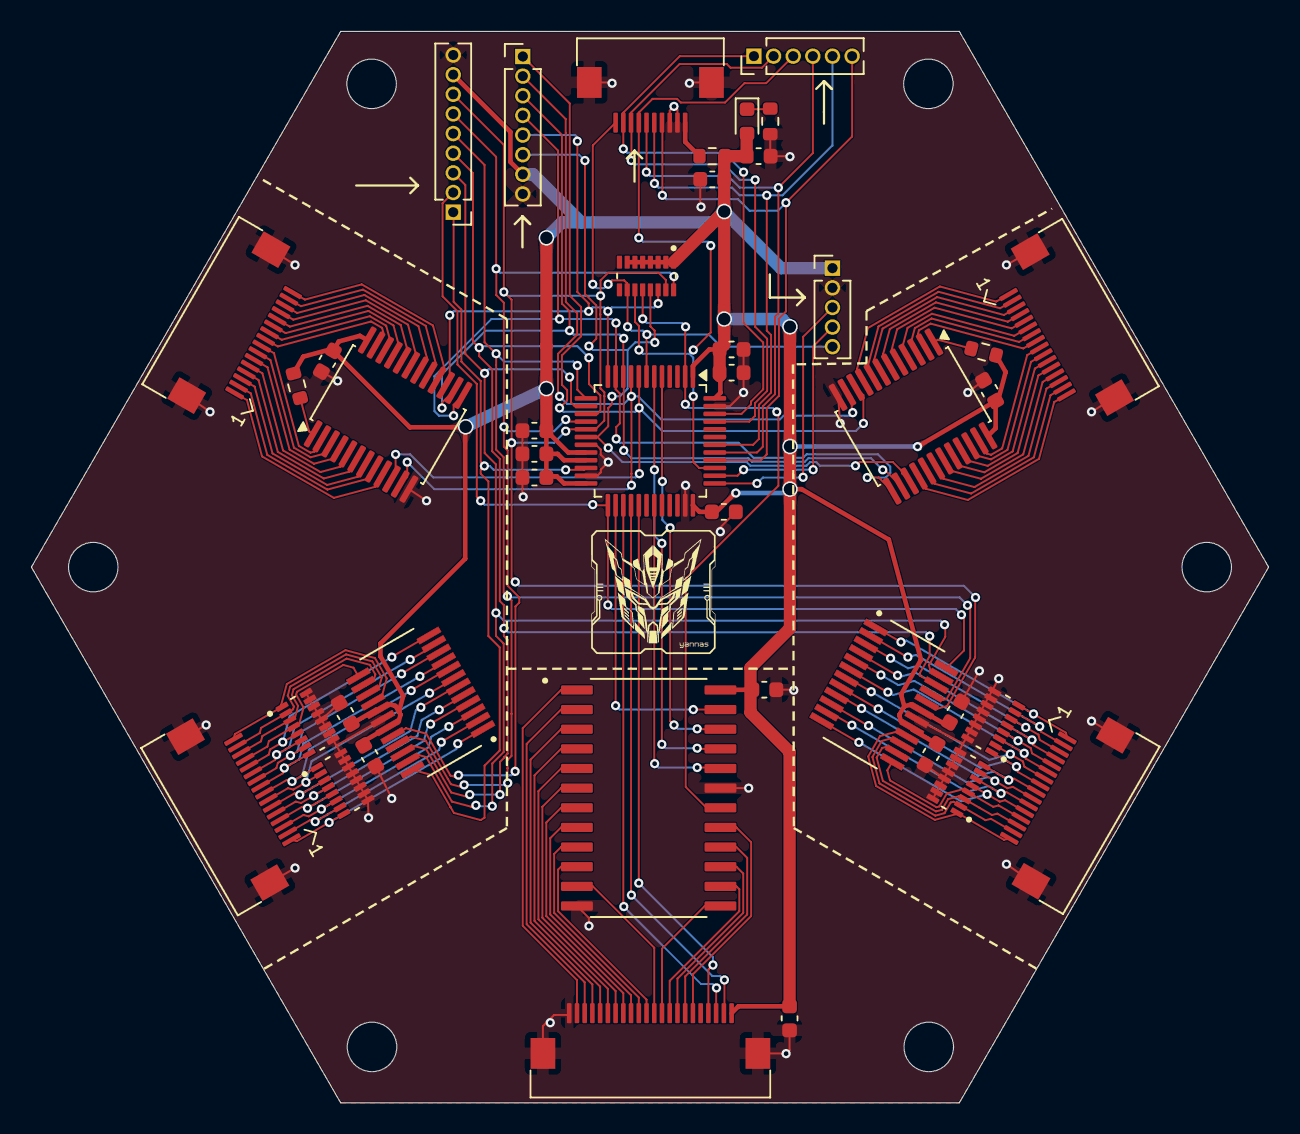
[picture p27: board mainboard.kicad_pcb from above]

Board: 4 copper layers, 80.0 x 69.3 mm, 48 parts (0 on the bottom side), 116 nets.

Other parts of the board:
MCU: STM32G474CETx; LQFP-48_7x7mm_P0.5mm

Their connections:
+3.3V: MCU.1 (VBAT), MCU.20 (VREF+), MCU.21 (VDDA), MCU.24 (VDD), MCU.36 (VDD), MCU.48 (VDD); also elsewhere on the board
/ACC_EN: MCU.2 (PC13); also elsewhere on the board
/CS1: MCU.16 (PB0); also elsewhere on the board
/CS2: MCU.17 (PB1); also elsewhere on the board
/CSA1: MCU.26 (PB12); also elsewhere on the board
/CSA2: MCU.5 (PF0); also elsewhere on the board
/CSA3: MCU.6 (PF1); also elsewhere on the board
/CSA4: MCU.31 (PA9); also elsewhere on the board
/EN1: MCU.12 (PA4); also elsewhere on the board
/EN2: MCU.18 (PB2); also elsewhere on the board
/EOC1: MCU.22 (PB10); also elsewhere on the board
/EOC2: MCU.25 (PB11); also elsewhere on the board
/HOST_IRQ: MCU.45 (PB8); also elsewhere on the board
/HOST_MISO: MCU.41 (PB4); also elsewhere on the board
/HOST_MOSI: MCU.42 (PB5); also elsewhere on the board
/HOST_SCK: MCU.40 (PB3); also elsewhere on the board
/HOST_SYNC: MCU.46 (PB9); also elsewhere on the board
/HOST_nCS: MCU.39 (PA15); also elsewhere on the board
/MISO: MCU.14 (PA6); also elsewhere on the board
/MOSI: MCU.15 (PA7); also elsewhere on the board
/NRST: MCU.7 (PG10); also elsewhere on the board
/S0: MCU.8 (PA0); also elsewhere on the board
/S1: MCU.9 (PA1); also elsewhere on the board
/S2: MCU.10 (PA2); also elsewhere on the board
/S3: MCU.11 (PA3); also elsewhere on the board
/SCLK: MCU.13 (PA5); also elsewhere on the board
/SWCLK: MCU.38 (PA14); also elsewhere on the board
/SWDIO: MCU.37 (PA13); also elsewhere on the board
GND: MCU.19 (VSSA), MCU.23 (VSS), MCU.35 (VSS), MCU.47 (VSS); also elsewhere on the board
MISO1: MCU.28 (PB14); also elsewhere on the board
MOSI1: MCU.29 (PB15); also elsewhere on the board
SCK1: MCU.27 (PB13); also elsewhere on the board

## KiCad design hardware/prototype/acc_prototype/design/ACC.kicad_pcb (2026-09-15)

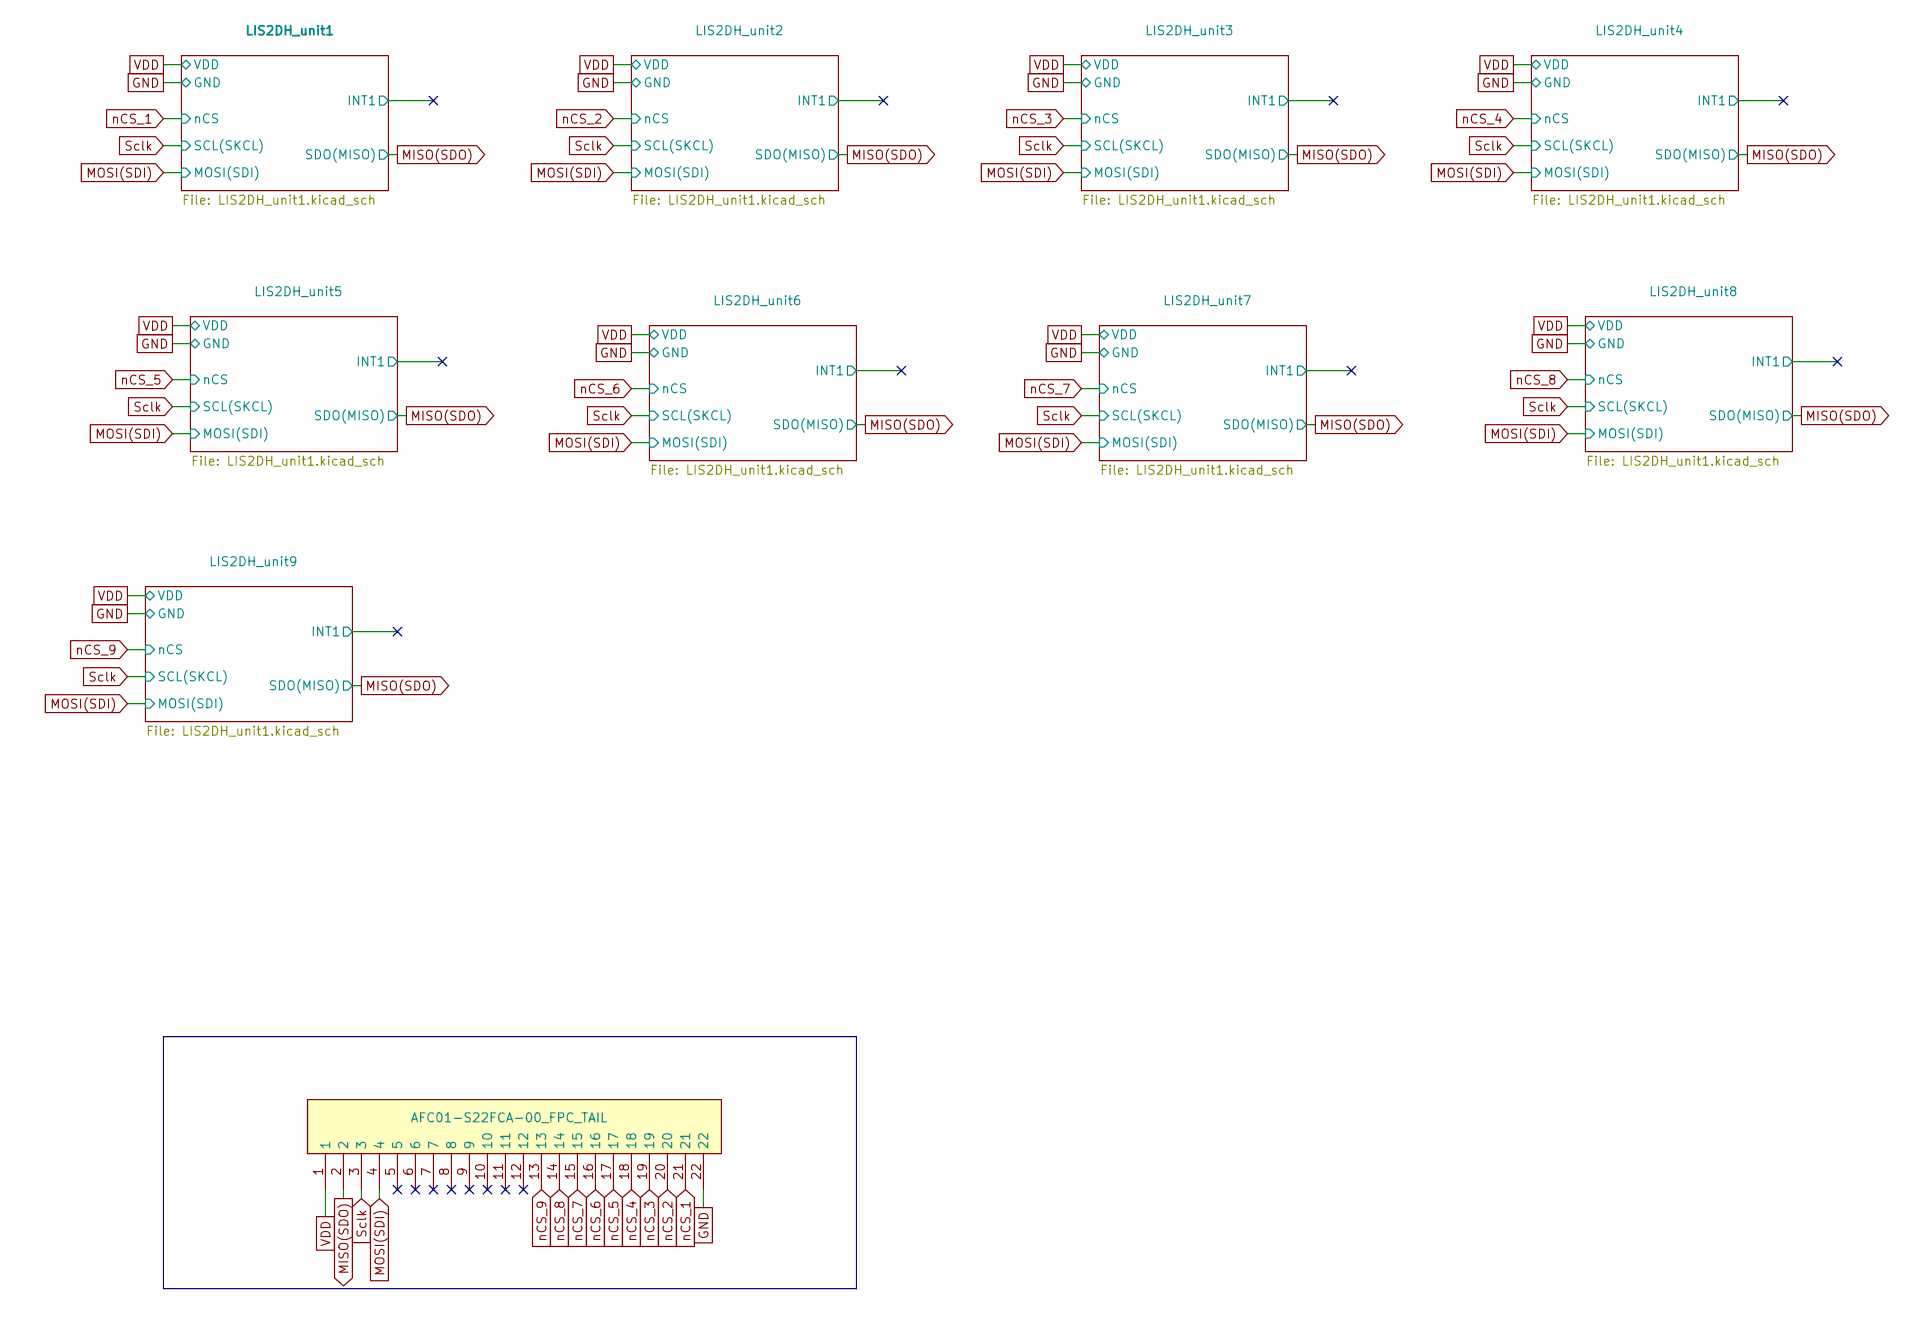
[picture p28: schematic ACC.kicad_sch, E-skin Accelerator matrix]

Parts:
FFC_connector1: AFC01-S22FCA-00_FPC_TAIL; LCSC Part C262668

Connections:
GND: FFC_connector1.22; also elsewhere on the board
MISO(SDO): FFC_connector1.2; also elsewhere on the board
MOSI(SDI): FFC_connector1.4; also elsewhere on the board
Sclk: FFC_connector1.3; also elsewhere on the board
VDD: FFC_connector1.1; also elsewhere on the board
nCS_1: FFC_connector1.21; also elsewhere on the board
nCS_2: FFC_connector1.20; also elsewhere on the board
nCS_3: FFC_connector1.19; also elsewhere on the board
nCS_4: FFC_connector1.18; also elsewhere on the board
nCS_5: FFC_connector1.17; also elsewhere on the board
nCS_6: FFC_connector1.16; also elsewhere on the board
nCS_7: FFC_connector1.15; also elsewhere on the board
nCS_8: FFC_connector1.14; also elsewhere on the board
nCS_9: FFC_connector1.13; also elsewhere on the board

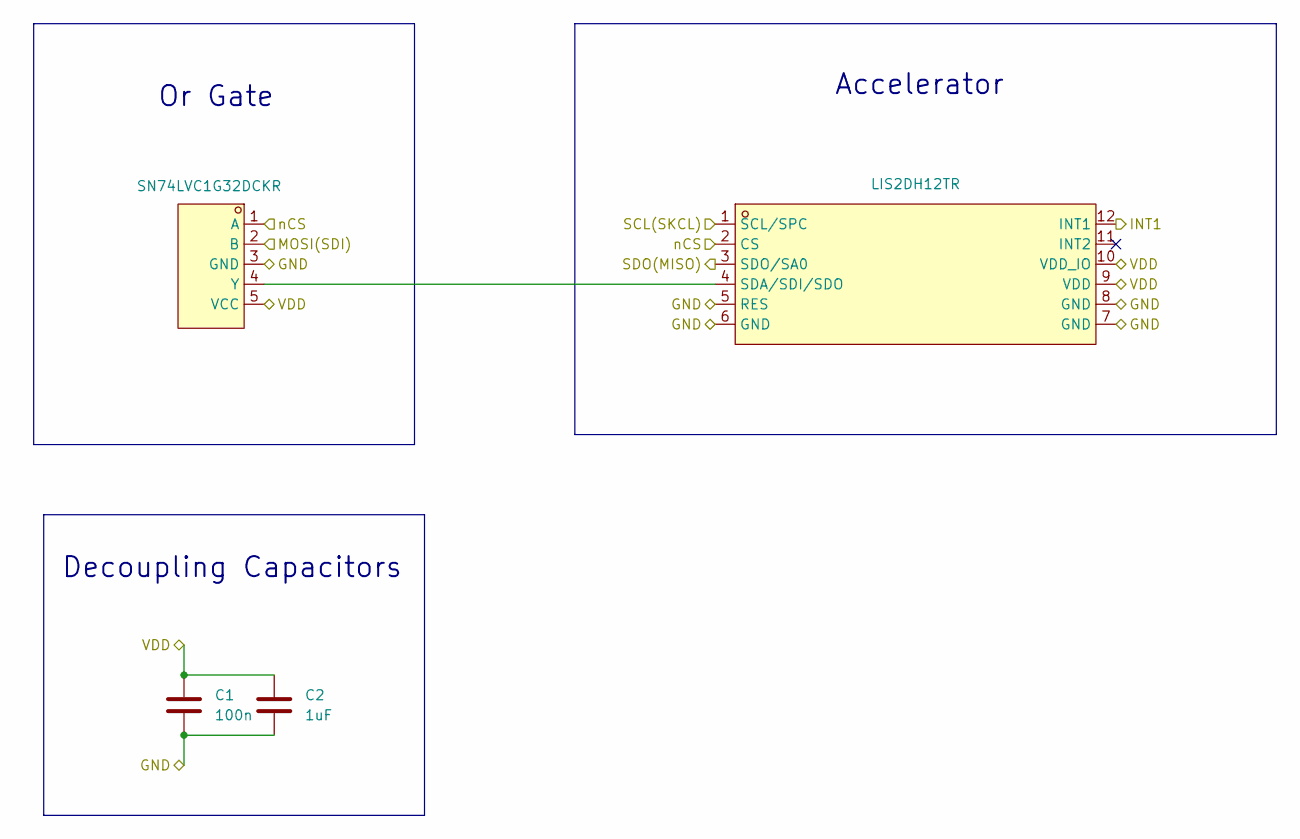
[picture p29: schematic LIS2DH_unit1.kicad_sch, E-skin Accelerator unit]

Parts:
C1: 100n; C_0402_1005Metric_Pad0.74x0.62mm_HandSolder; LCSC Part C1525
C2: 1uF; C_0402_1005Metric_Pad0.74x0.62mm_HandSolder; LCSC Part C52923
U1: LIS2DH12TR; LCSC Part C110926
U17: SN74LVC1G32DCKR; LCSC Part C7840

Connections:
/LIS2DH_unit1/INT1: U1.12 (INT1)
GND: C1.2, C2.2, U1.5 (RES), U1.6 (GND), U1.7 (GND), U1.8 (GND), U17.3 (GND); also elsewhere on the board
MISO(SDO): U1.3 (SDO/SA0); also elsewhere on the board
MOSI(SDI): U17.2 (B); also elsewhere on the board
unnamed: U1.4 (SDA/SDI/SDO), U17.4 (Y)
Sclk: U1.1 (SCL/SPC); also elsewhere on the board
VDD: C1.1, C2.1, U1.9 (VDD), U1.10 (VDD_IO), U17.5 (VCC); also elsewhere on the board
nCS_1: U1.2 (CS), U17.1 (A); also elsewhere on the board

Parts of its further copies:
C3, C5, C7, C9, C11, C13, C15, C17: 100n; C_0402_1005Metric_Pad0.74x0.62mm_HandSolder; LCSC Part C1525
C4, C6, C8, C10, C12, C14, C16, C18: 1uF; C_0402_1005Metric_Pad0.74x0.62mm_HandSolder; LCSC Part C52923
U2, U3, U4, U5, U6, U7, U8, U9: LIS2DH12TR; LCSC Part C110926
U18, U19, U20, U21, U22, U23, U24, U25: SN74LVC1G32DCKR; LCSC Part C7840

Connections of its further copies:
/LIS2DH_unit2/INT1: U2.12 (INT1)
/LIS2DH_unit3/INT1: U3.12 (INT1)
/LIS2DH_unit4/INT1: U4.12 (INT1)
/LIS2DH_unit5/INT1: U5.12 (INT1)
/LIS2DH_unit6/INT1: U6.12 (INT1)
/LIS2DH_unit7/INT1: U7.12 (INT1)
/LIS2DH_unit8/INT1: U8.12 (INT1)
/LIS2DH_unit9/INT1: U9.12 (INT1)
GND: C3.2, C4.2, C5.2, C6.2, C7.2, C8.2, C9.2, C10.2, C11.2, C12.2, C13.2, C14.2, C15.2, C16.2, C17.2, C18.2, U2.5 (RES), U2.6 (GND), U2.7 (GND), U2.8 (GND), U3.5 (RES), U3.6 (GND), U3.7 (GND), U3.8 (GND), U4.5 (RES), U4.6 (GND), U4.7 (GND), U4.8 (GND), U5.5 (RES), U5.6 (GND), U5.7 (GND), U5.8 (GND), U6.5 (RES), U6.6 (GND), U6.7 (GND), U6.8 (GND), U7.5 (RES), U7.6 (GND), U7.7 (GND), U7.8 (GND), U8.5 (RES), U8.6 (GND), U8.7 (GND), U8.8 (GND), U9.5 (RES), U9.6 (GND), U9.7 (GND), U9.8 (GND), U18.3 (GND), U19.3 (GND), U20.3 (GND), U21.3 (GND), U22.3 (GND), U23.3 (GND), U24.3 (GND), U25.3 (GND); also elsewhere on the board
MISO(SDO): U2.3 (SDO/SA0), U3.3 (SDO/SA0), U4.3 (SDO/SA0), U5.3 (SDO/SA0), U6.3 (SDO/SA0), U7.3 (SDO/SA0), U8.3 (SDO/SA0), U9.3 (SDO/SA0); also elsewhere on the board
MOSI(SDI): U18.2 (B), U19.2 (B), U20.2 (B), U21.2 (B), U22.2 (B), U23.2 (B), U24.2 (B), U25.2 (B); also elsewhere on the board
unnamed: U2.4 (SDA/SDI/SDO), U18.4 (Y)
unnamed: U3.4 (SDA/SDI/SDO), U19.4 (Y)
unnamed: U4.4 (SDA/SDI/SDO), U20.4 (Y)
unnamed: U5.4 (SDA/SDI/SDO), U21.4 (Y)
unnamed: U6.4 (SDA/SDI/SDO), U22.4 (Y)
unnamed: U7.4 (SDA/SDI/SDO), U23.4 (Y)
unnamed: U8.4 (SDA/SDI/SDO), U24.4 (Y)
unnamed: U9.4 (SDA/SDI/SDO), U25.4 (Y)
Sclk: U2.1 (SCL/SPC), U3.1 (SCL/SPC), U4.1 (SCL/SPC), U5.1 (SCL/SPC), U6.1 (SCL/SPC), U7.1 (SCL/SPC), U8.1 (SCL/SPC), U9.1 (SCL/SPC); also elsewhere on the board
VDD: C3.1, C4.1, C5.1, C6.1, C7.1, C8.1, C9.1, C10.1, C11.1, C12.1, C13.1, C14.1, C15.1, C16.1, C17.1, C18.1, U2.9 (VDD), U2.10 (VDD_IO), U3.9 (VDD), U3.10 (VDD_IO), U4.9 (VDD), U4.10 (VDD_IO), U5.9 (VDD), U5.10 (VDD_IO), U6.9 (VDD), U6.10 (VDD_IO), U7.9 (VDD), U7.10 (VDD_IO), U8.9 (VDD), U8.10 (VDD_IO), U9.9 (VDD), U9.10 (VDD_IO), U18.5 (VCC), U19.5 (VCC), U20.5 (VCC), U21.5 (VCC), U22.5 (VCC), U23.5 (VCC), U24.5 (VCC), U25.5 (VCC); also elsewhere on the board
nCS_2: U2.2 (CS), U18.1 (A); also elsewhere on the board
nCS_3: U3.2 (CS), U19.1 (A); also elsewhere on the board
nCS_4: U4.2 (CS), U20.1 (A); also elsewhere on the board
nCS_5: U5.2 (CS), U21.1 (A); also elsewhere on the board
nCS_6: U6.2 (CS), U22.1 (A); also elsewhere on the board
nCS_7: U7.2 (CS), U23.1 (A); also elsewhere on the board
nCS_8: U8.2 (CS), U24.1 (A); also elsewhere on the board
nCS_9: U9.2 (CS), U25.1 (A); also elsewhere on the board

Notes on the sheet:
Decoupling Capacitors
Accelerator
Or Gate

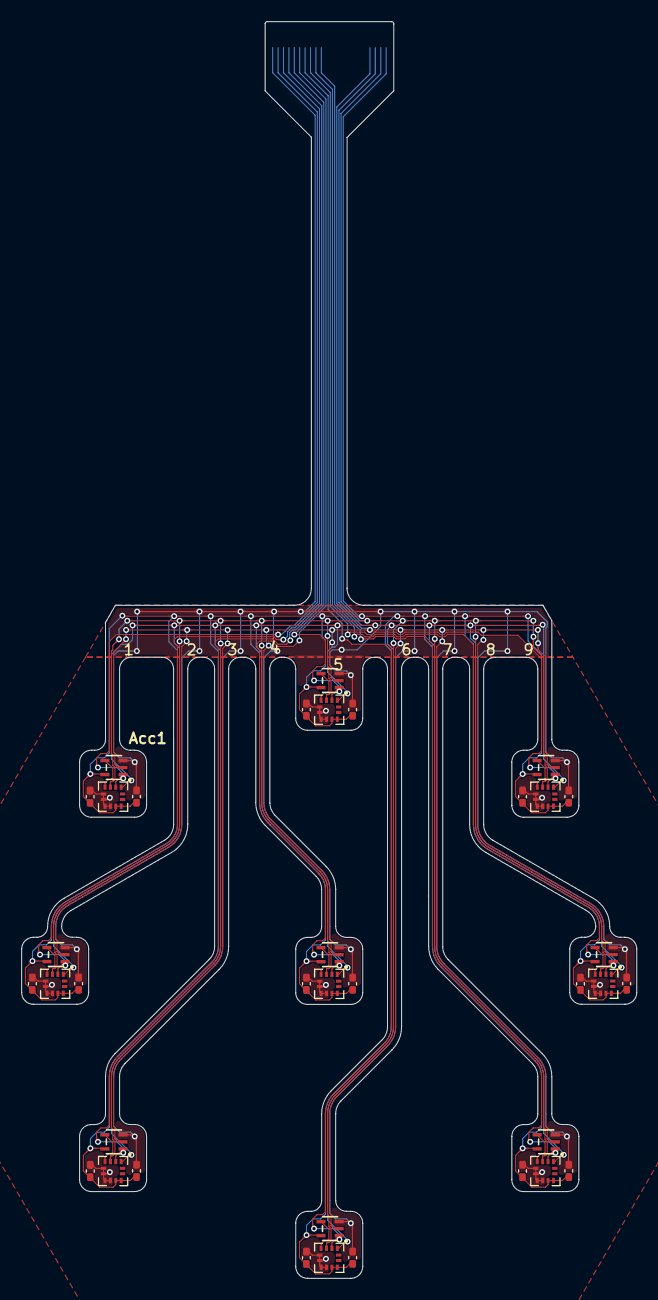
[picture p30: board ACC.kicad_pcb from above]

Board: 2 copper layers, 56.9 x 116.3 mm, 37 parts (1 on the bottom side), 23 nets.

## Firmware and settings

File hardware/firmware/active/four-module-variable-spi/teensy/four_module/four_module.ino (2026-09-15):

/*
 * Variable-length four-module FSR-only bridge for Teensy 4.1.
 *
 * Wire contract: ESK protocol v4 from STM32, MUL1 protocol v2 to the PC,
 * two 16 x 16 FSR layers per module. Host SPI clocks only the encoded frame:
 * 16 header bytes, then length - 16 bytes under the same chip select.
 */
#include <Arduino.h>
#include <SPI.h>

constexpr uint8_t MODULE_COUNT = 4;
constexpr uint8_t ALL_MODULES_MASK = (1U << MODULE_COUNT) - 1U;
constexpr uint8_t CS_PINS[MODULE_COUNT] = {10, 14, 15, 16};
constexpr uint8_t IRQ_PINS[MODULE_COUNT] = {2, 3, 4, 5};
constexpr uint32_t USB_BAUD = 2000000;
constexpr uint32_t SPI_HZ = 10000000;
#ifndef ESKIN_DEFAULT_SCAN_HZ
#define ESKIN_DEFAULT_SCAN_HZ 200
#endif
static_assert(ESKIN_DEFAULT_SCAN_HZ >= 0 && ESKIN_DEFAULT_SCAN_HZ <= 1000,
              "ESKIN_DEFAULT_SCAN_HZ must be in the range 0..1000");
constexpr uint32_t DEFAULT_SCAN_HZ = ESKIN_DEFAULT_SCAN_HZ;
constexpr uint32_t IRQ_SETTLE_US = 50;
constexpr uint32_t CS_SETUP_US = 10;
constexpr uint32_t CS_HOLD_US = 10;
constexpr uint32_t MODE_SWITCH_DELAY_MS = 1000;
constexpr uint32_t IRQ_RELEASE_TIMEOUT_MS = 100;
constexpr uint32_t MULTI_ROUND_TIMEOUT_MS = 100;
constexpr uint32_t STATUS_PACKET_INTERVAL_MS = 500;
constexpr uint32_t MIN_MODULE_OFFLINE_TIMEOUT_MS = 100;
constexpr uint32_t MODULE_OFFLINE_PERIODS = 3;

constexpr size_t HOST_MAX_FRAME_BYTES = 1044;
constexpr size_t HOST_HEADER_BYTES = 16;
constexpr size_t HOST_COMMAND_BYTES = 16;
constexpr size_t PACKET_HEADER_BYTES = 20;
constexpr size_t PACKET_TRAILER_BYTES = 4;
constexpr size_t DIAGNOSTIC_PREFIX_BYTES = 16;
constexpr uint8_t ESK_PROTOCOL_VERSION = 4U;
constexpr size_t DELTA_MASK_BYTES = 32;
constexpr size_t DELTA_MASK_TOTAL_BYTES = 2 * DELTA_MASK_BYTES;
constexpr size_t DELTA_MASK_PREFIX_BYTES = 16 + DELTA_MASK_TOTAL_BYTES;
constexpr size_t DELTA_MASK_MIN_FRAME_BYTES = DELTA_MASK_PREFIX_BYTES + 4;
constexpr size_t MAX_PACKET_BYTES = PACKET_HEADER_BYTES +
                                     MODULE_COUNT * (4 + HOST_MAX_FRAME_BYTES) +
                                     PACKET_TRAILER_BYTES;
/* Keep a short burst of complete MUL1 packets while the host drains USB.
 * A depth of two made a temporary CDC scheduling delay immediately discard
 * the packet that contained the Delta base frame. */
constexpr size_t USB_QUEUE_DEPTH = 4;

constexpr uint8_t ESK_FULL[4] = {'E', 'S', 'K', 'F'};
constexpr uint8_t ESK_DELTA[4] = {'E', 'S', 'K', 'D'};
constexpr uint8_t MUL_MAGIC[4] = {'M', 'U', 'L', '1'};
constexpr uint8_t COMMAND_MAGIC[4] = {'D', 'S', 'C', 'M'};
constexpr uint8_t COMMAND_FLAG_DELTA_RESYNC = 0x01U;
constexpr uint8_t MODULE_STATUS_NOT_UPDATED = 0x80U;

enum class Algorithm : uint8_t { Full = 0, Delta = 1 };
enum class ReadResult : uint8_t {
  Ok = 0,
  BadFrame,
  BadCrc,
  NoIrq,
  Timeout,
  ModeTransition,
  ResyncNeeded,
  BadVersion,
};

struct ModuleState {
  bool haveFrame = false;
  uint16_t logicalLength = 0;
  uint32_t lastSequence = 0;
  bool sequenceSeen = false;
  uint32_t lastIrqMs = 0;
  uint32_t irqCount = 0;
  uint32_t okCount = 0;
  uint32_t badFrameCount = 0;
  uint32_t crcErrorCount = 0;
  uint32_t sequenceGapCount = 0;
  uint32_t releaseTimeoutCount = 0;
  Algorithm frameAlgorithm = Algorithm::Full;
  ReadResult lastResult = ReadResult::NoIrq;
};

uint8_t moduleFrames[MODULE_COUNT][HOST_MAX_FRAME_BYTES] = {};
ModuleState modules[MODULE_COUNT] = {};
uint8_t usbQueue[USB_QUEUE_DEPTH][MAX_PACKET_BYTES] = {};
uint16_t usbQueueLength[USB_QUEUE_DEPTH] = {};
size_t usbQueueHead = 0;
size_t usbQueueTail = 0;
size_t usbQueueCount = 0;
size_t usbQueueOffset = 0;
size_t usbQueueHighWater = 0;
uint32_t usbPacketsSent = 0;
uint32_t packetSequence = 0;
uint32_t lastDiagnosticMs = 0;
uint32_t lastStatusPacketMs = 0;
uint8_t pendingUpdateMask = 0;
uint8_t activeModuleMask = ALL_MODULES_MASK;
uint32_t pendingSinceMs = 0;
uint8_t deltaResyncMask = 0U;
uint32_t transportEpoch = 0U;
Algorithm selectedAlgorithm = Algorithm::Full;
Algorithm pendingAlgorithm = Algorithm::Full;
bool modeSwitchPending = false;
uint32_t modeSwitchStartedMs = 0;
uint16_t scanHz = DEFAULT_SCAN_HZ;
uint16_t deltaThreshold = 8;

void clearPendingTransport();
void beginResync(Algorithm algorithm);
void fillCommand(uint8_t command[HOST_COMMAND_BYTES], bool requestDeltaResync);

uint32_t moduleOfflineTimeoutMs() {
  if (scanHz == 0U) return MIN_MODULE_OFFLINE_TIMEOUT_MS;
  const uint32_t periodMs =
      (1000UL + (uint32_t)scanHz - 1UL) / (uint32_t)scanHz;
  const uint32_t adaptiveTimeout = periodMs * MODULE_OFFLINE_PERIODS;
  return adaptiveTimeout > MIN_MODULE_OFFLINE_TIMEOUT_MS ?
         adaptiveTimeout : MIN_MODULE_OFFLINE_TIMEOUT_MS;
}

uint16_t readU16LE(const uint8_t *value) {
  return (uint16_t)value[0] | ((uint16_t)value[1] << 8U);
}

uint32_t readU32LE(const uint8_t *value) {
  return (uint32_t)value[0] | ((uint32_t)value[1] << 8U) |
         ((uint32_t)value[2] << 16U) | ((uint32_t)value[3] << 24U);
}

void writeU16LE(uint8_t *target, uint16_t value) {
  target[0] = (uint8_t)value;
  target[1] = (uint8_t)(value >> 8U);
}

void writeU32LE(uint8_t *target, uint32_t value) {
  target[0] = (uint8_t)value;
  target[1] = (uint8_t)(value >> 8U);
  target[2] = (uint8_t)(value >> 16U);
  target[3] = (uint8_t)(value >> 24U);
}

uint32_t crc32Ieee(const uint8_t *data, size_t length) {
  uint32_t crc = 0xFFFFFFFFU;
  for (size_t i = 0; i < length; ++i) {
    crc ^= data[i];
    for (uint8_t bit = 0; bit < 8; ++bit) {
      const uint32_t mask = 0U - (crc & 1U);
      crc = (crc >> 1U) ^ (0xEDB88320U & mask);
    }
  }
  return ~crc;
}

bool markerIs(const uint8_t *value, const uint8_t marker[4]) {
  return memcmp(value, marker, 4U) == 0;
}

const char *algorithmName() {
  switch (selectedAlgorithm) {
    case Algorithm::Delta: return "DELTA";
    default: return "FULL";
  }
}

Algorithm algorithmForFrame(const uint8_t *frame) {
  if (markerIs(frame, ESK_FULL)) {
    if ((frame[5] & 0x20U) != 0U) return Algorithm::Delta;
    return Algorithm::Full;
  }
  if (markerIs(frame, ESK_DELTA)) {
    return Algorithm::Delta;
  }
  return Algorithm::Full;
}

bool isDeltaSyncFrame(const uint8_t *frame) {
  return markerIs(frame, ESK_FULL) && ((frame[5] & 0x20U) != 0U);
}

bool waitForLevel(uint8_t pin, uint8_t level, uint32_t timeoutMs) {
  const uint32_t started = millis();
  while (digitalRead(pin) != level) {
    if ((millis() - started) >= timeoutMs) return false;
    yield();
  }
  return true;
}

/* Only inspect the bytes already clocked from the slave. A valid header
 * bounds the second transfer; the mask and CRC are checked after it ends. */
uint16_t headerFrameLength(const uint8_t *frame) {
  if (frame[4] != ESK_PROTOCOL_VERSION ||
      (frame[5] & 0x10U) == 0U || (frame[5] & 0xC0U) != 0U) return 0U;
  const uint16_t declared = readU16LE(&frame[6]);
  if (markerIs(frame, ESK_FULL)) {
    return declared == HOST_MAX_FRAME_BYTES ? declared : 0U;
  }
  if (markerIs(frame, ESK_DELTA)) {
    if ((frame[5] & 0x20U) == 0U ||
        declared < DELTA_MASK_MIN_FRAME_BYTES ||
        declared > HOST_MAX_FRAME_BYTES || (declared & 1U) != 0U) return 0U;
    return declared;
  }
  return 0U;
}

uint16_t logicalFrameLength(const uint8_t *frame) {
  const uint16_t declared = headerFrameLength(frame);
  if (declared == 0U) return 0U;
  if (markerIs(frame, ESK_FULL)) {
    return declared;
  }
  if (markerIs(frame, ESK_DELTA)) {
    uint16_t changed = 0U;
    for (size_t index = 0; index < DELTA_MASK_TOTAL_BYTES; ++index) {
      uint8_t value = frame[16 + index];
      while (value != 0U) {
        changed = (uint16_t)(changed + (value & 1U));
        value = (uint8_t)(value >> 1U);
      }
    }
    const uint16_t expected = (uint16_t)(DELTA_MASK_MIN_FRAME_BYTES +
                                         2U * changed);
    if (declared != expected) return 0;
    return declared;
  }
  return 0;
}

ReadResult readModuleFrame(uint8_t module) {
  ModuleState &state = modules[module];
  uint8_t *frame = moduleFrames[module];
  const uint8_t moduleBit = (uint8_t)(1U << module);
  const bool requestDeltaResync =
      (selectedAlgorithm == Algorithm::Delta) &&
      ((deltaResyncMask & moduleBit) != 0U);
  uint8_t command[HOST_COMMAND_BYTES];
  fillCommand(command, requestDeltaResync);
  memset(frame, 0, HOST_MAX_FRAME_BYTES);
  memcpy(frame, command, HOST_COMMAND_BYTES);
  delayMicroseconds(IRQ_SETTLE_US);
  SPI.beginTransaction(SPISettings(SPI_HZ, MSBFIRST, SPI_MODE0));
  digitalWrite(CS_PINS[module], LOW);
  delayMicroseconds(CS_SETUP_US);
  SPI.transfer(frame, HOST_HEADER_BYTES);
  const uint16_t wireLength = headerFrameLength(frame);
  if (wireLength != 0U) {
    /* Keep CS asserted: STM32 already armed one DMA for the full frame.
     * The 16-byte MOSI command was sent during the header transfer. */
    SPI.transfer(frame + HOST_HEADER_BYTES, wireLength - HOST_HEADER_BYTES);
  }
  /* An invalid header ends after 16 bytes. The slave detects the partial
   * transaction when NSS is released and aborts its outstanding DMA. */
  delayMicroseconds(CS_HOLD_US);
  digitalWrite(CS_PINS[module], HIGH);
  SPI.endTransaction();

  const uint16_t length = wireLength != 0U ? logicalFrameLength(frame) : 0U;
  if (length == 0U) {
    if (frame[0] == 'E' && frame[1] == 'S' && frame[2] == 'K' &&
        frame[4] != ESK_PROTOCOL_VERSION) {
      return ReadResult::BadVersion;
    }
    return ReadResult::BadFrame;
  }
  const uint32_t wire = readU32LE(&frame[length - 4U]);
  if (wire != crc32Ieee(frame, length - 4U)) {
    ++state.crcErrorCount;
    return ReadResult::BadCrc;
  }
  state.frameAlgorithm = algorithmForFrame(frame);
  const uint32_t sequence = readU32LE(&frame[8]);
  const bool sequenceGap =
      state.sequenceSeen && sequence != state.lastSequence + 1U;
  if (sequenceGap) {
    ++state.sequenceGapCount;
  }
  state.lastSequence = sequence;
  state.sequenceSeen = true;

  const bool deltaSync = isDeltaSyncFrame(frame);
  if (selectedAlgorithm == Algorithm::Delta &&
      state.frameAlgorithm == Algorithm::Delta && sequenceGap && !deltaSync) {
    /* A Delta base may have been skipped while the USB queue was full. */
    beginResync(Algorithm::Delta);
    return ReadResult::ResyncNeeded;
  }
  if (requestDeltaResync) {
    if (!deltaSync) return ReadResult::ResyncNeeded;
    deltaResyncMask &= (uint8_t)~moduleBit;
  }
  if (state.frameAlgorithm != selectedAlgorithm) {
    return ReadResult::ModeTransition;
  }
  state.logicalLength = length;
  state.haveFrame = true;
  ++state.okCount;
  return ReadResult::Ok;
}

void fillCommand(uint8_t command[HOST_COMMAND_BYTES],
                 bool requestDeltaResync) {
  memset(command, 0, HOST_COMMAND_BYTES);
  memcpy(command, COMMAND_MAGIC, 4U);
  command[4] = 2U;
  command[5] = (uint8_t)selectedAlgorithm;
  writeU16LE(&command[6], deltaThreshold);
  /* Bytes 8..9 are reserved zero; scan rate retains its DSCM v2 offset. */
  writeU16LE(&command[10], scanHz);
  if (requestDeltaResync) {
    command[12] = COMMAND_FLAG_DELTA_RESYNC;
  }
}

void clearPendingTransport() {
  ++transportEpoch;
  pendingUpdateMask = 0U;
  pendingSinceMs = 0U;
  if (usbQueueCount > 0U && usbQueueOffset > 0U) {
    /* Bytes from the head packet are already on USB and cannot be recalled.
     * Keep only that packet so its remaining bytes preserve the MUL1 framing;
     * discard every packet that has not started transmission. */
    usbQueueTail = (usbQueueHead + 1U) % USB_QUEUE_DEPTH;
    usbQueueCount = 1U;
  } else {
    usbQueueHead = 0U;
    usbQueueTail = 0U;
    usbQueueCount = 0U;
    usbQueueOffset = 0U;
  }
}

void beginResync(Algorithm algorithm) {
  if (selectedAlgorithm != algorithm) return;
  const uint8_t activeMask = (uint8_t)(activeModuleMask & ALL_MODULES_MASK);
  if (algorithm == Algorithm::Delta) {
    deltaResyncMask = activeMask;
  }
  /* Discard packets that were prepared before the sequence discontinuity.
   * They can contain deltas whose base is no longer available to the PC. */
  clearPendingTransport();
  for (uint8_t module = 0; module < MODULE_COUNT; ++module) {
    modules[module].haveFrame = false;
    modules[module].logicalLength = 0U;
    modules[module].sequenceSeen = false;
    modules[module].lastResult = ReadResult::ResyncNeeded;
  }
}

void requestModeSwitch(Algorithm requestedAlgorithm) {
  pendingAlgorithm = requestedAlgorithm;
  modeSwitchPending = true;
  modeSwitchStartedMs = millis();
  /* Do not let frames from the old mode remain in the USB or round queues
   * while the one-second coordinated switch window is running. */
  clearPendingTransport();
}

void activatePendingModeSwitch() {
  selectedAlgorithm = pendingAlgorithm;
  modeSwitchPending = false;
  modeSwitchStartedMs = 0U;
  clearPendingTransport();
  deltaResyncMask = (selectedAlgorithm == Algorithm::Delta) ?
                    ALL_MODULES_MASK : 0U;
  for (uint8_t module = 0; module < MODULE_COUNT; ++module) {
    modules[module].haveFrame = false;
    modules[module].logicalLength = 0U;
    modules[module].sequenceSeen = false;
    modules[module].lastResult = ReadResult::ModeTransition;
  }
}

void requestModeResync(Algorithm algorithm) {
  beginResync(algorithm);
}

bool enqueueMultiPacket(uint8_t updatedMask) {
  if (usbQueueCount >= USB_QUEUE_DEPTH) return false;
  uint8_t *packet = usbQueue[usbQueueTail];
  memset(packet, 0, MAX_PACKET_BYTES);
  memcpy(packet, MUL_MAGIC, 4U);
  packet[4] = 2U;
  packet[5] = MODULE_COUNT;
  packet[6] = updatedMask;
  writeU32LE(&packet[12], packetSequence++);
  writeU32LE(&packet[16], millis());

  size_t offset = PACKET_HEADER_BYTES;
  for (uint8_t module = 0; module < MODULE_COUNT; ++module) {
    const bool updated = (updatedMask & (uint8_t)(1U << module)) != 0U;
    packet[offset++] = module;
    if (!updated) {
      /* Do not replay a previous Delta frame. The PC must retain its cache.
       * Keep the last read result in the status byte so a no-data system is
       * diagnosable without mixing text into the binary USB stream. */
      packet[offset++] = (uint8_t)(MODULE_STATUS_NOT_UPDATED |
                                   ((uint8_t)modules[module].lastResult & 0x0FU));
      const bool includeDiagnosticPrefix =
          modules[module].lastResult == ReadResult::BadFrame ||
          modules[module].lastResult == ReadResult::BadCrc ||
          modules[module].lastResult == ReadResult::Timeout ||
          modules[module].lastResult == ReadResult::BadVersion;
      const uint16_t diagnosticLength = includeDiagnosticPrefix ?
          (uint16_t)DIAGNOSTIC_PREFIX_BYTES : 0U;
      writeU16LE(&packet[offset], diagnosticLength);
      offset += 2U;
      if (diagnosticLength != 0U) {
        memcpy(&packet[offset], moduleFrames[module], diagnosticLength);
        offset += diagnosticLength;
      }
      continue;
    }
    packet[offset++] = modules[module].haveFrame ? 0U :
                       (uint8_t)modules[module].lastResult + 1U;
    const uint16_t length = modules[module].haveFrame ?
                            modules[module].logicalLength : 0U;
    writeU16LE(&packet[offset], length);
    offset += 2U;
    if (length != 0U) {
      memcpy(&packet[offset], moduleFrames[module], length);
      offset += length;
    }
  }
  const uint16_t packetLength = (uint16_t)(offset + PACKET_TRAILER_BYTES);
  writeU16LE(&packet[8], packetLength);
  writeU16LE(&packet[10], 0U);
  writeU32LE(&packet[offset], crc32Ieee(packet, offset));
  usbQueueLength[usbQueueTail] = packetLength;
  usbQueueTail = (usbQueueTail + 1U) % USB_QUEUE_DEPTH;
  ++usbQueueCount;
  if (usbQueueCount > usbQueueHighWater) usbQueueHighWater = usbQueueCount;
  return true;
}

void pollModules() {
  if (modeSwitchPending) {
    if ((uint32_t)(millis() - modeSwitchStartedMs) < MODE_SWITCH_DELAY_MS) {
      return;
    }
    activatePendingModeSwitch();
  }

  uint8_t updatedMask = 0U;
  const uint32_t nowMs = millis();
  const uint32_t offlineTimeoutMs = moduleOfflineTimeoutMs();
  const uint32_t pollEpoch = transportEpoch;
  /* The STM32 scan clock is the single rate limiter. Poll IRQ continuously so
   * a ready frame is consumed immediately instead of waiting for another
   * Teensy-side period when the two independent clocks are out of phase. */
  for (uint8_t module = 0; module < MODULE_COUNT; ++module) {
    const uint8_t moduleBit = (uint8_t)(1U << module);
    ModuleState &state = modules[module];
    if ((pendingUpdateMask & moduleBit) != 0U) {
      /* moduleFrames[module] is the immutable snapshot for the pending MUL1
       * round. Reading this module again would overwrite an unsent ESKF/ESKD
       * frame and break the PC's Delta base_sequence chain. This also freezes
       * the first ESKF returned during a coordinated resynchronisation. */
      continue;
    }
    if (digitalRead(IRQ_PINS[module]) != HIGH) {
      if ((activeModuleMask & moduleBit) != 0U &&
          (uint32_t)(nowMs - state.lastIrqMs) >= offlineTimeoutMs) {
        activeModuleMask &= (uint8_t)~moduleBit;
        pendingUpdateMask &= (uint8_t)~moduleBit;
        deltaResyncMask &= (uint8_t)~moduleBit;
        state.haveFrame = false;
        state.logicalLength = 0U;
        state.sequenceSeen = false;
        state.lastResult = ReadResult::NoIrq;
      }
      continue;
    }
    state.lastIrqMs = nowMs;
    if ((activeModuleMask & moduleBit) == 0U) {
      /* A reconnected module rejoins immediately. Delta needs a
       * fresh base before incremental frames can be accepted again. */
      activeModuleMask |= moduleBit;
      state.haveFrame = false;
      state.logicalLength = 0U;
      state.sequenceSeen = false;
      if (selectedAlgorithm == Algorithm::Delta) {
        deltaResyncMask |= moduleBit;
      }
    }
    ++modules[module].irqCount;
    const ReadResult result = readModuleFrame(module);
    modules[module].lastResult = result;
    if (result == ReadResult::Ok) {
      updatedMask |= moduleBit;
      pendingUpdateMask |= moduleBit;
      if (pendingSinceMs == 0U) pendingSinceMs = millis();
    } else if ((result != ReadResult::ModeTransition) &&
               (result != ReadResult::ResyncNeeded)) {
      ++modules[module].badFrameCount;
    }
    if (!waitForLevel(IRQ_PINS[module], LOW, IRQ_RELEASE_TIMEOUT_MS)) {
      ++modules[module].releaseTimeoutCount;
    }
    if (transportEpoch != pollEpoch) {
      /* A later module in this poll triggered beginResync(). Any frames
       * accepted earlier in the same local round belonged to the old cache
       * generation; clearPendingTransport() has invalidated them. Abort now
       * so a stale local updatedMask cannot reintroduce those frames. */
      return;
    }
  }

  const bool completeRound = activeModuleMask != 0U &&
      (pendingUpdateMask & activeModuleMask) == activeModuleMask;
  const bool timedOut = pendingUpdateMask != 0U &&
                        (millis() - pendingSinceMs) >= MULTI_ROUND_TIMEOUT_MS;
  const bool resyncPending =
      (selectedAlgorithm == Algorithm::Delta) &&
      ((deltaResyncMask & activeModuleMask) != 0U);
  if ((completeRound || timedOut) && !resyncPending) {
    if (enqueueMultiPacket(pendingUpdateMask)) {
      lastStatusPacketMs = millis();
      pendingUpdateMask = 0U;
      pendingSinceMs = 0U;
    } else if (selectedAlgorithm == Algorithm::Delta) {
      /* The packet was not queued. A later Delta frame may reference a
       * sequence that the PC never received, so force a full Delta sync. */
      beginResync(Algorithm::Delta);
    }
  }

  /* Always provide a low-rate diagnostic MUL1 packet when no module has
   * produced a valid frame. This keeps the USB/parser path observable and
   * reports whether each module has no IRQ, a bad frame, a CRC error, or a
   * timeout. It is intentionally rate-limited so it cannot affect scanning. */
  if ((updatedMask == 0U) &&
      ((millis() - lastStatusPacketMs) >= STATUS_PACKET_INTERVAL_MS)) {
    if (enqueueMultiPacket(0U)) {
      lastStatusPacketMs = millis();
    }
  }
}

void drainUsbQueue() {
  while (usbQueueCount > 0U) {
    const int available = Serial.availableForWrite();
    if (available <= 0) return;
    const size_t packetLength = usbQueueLength[usbQueueHead];
    const size_t remaining = packetLength - usbQueueOffset;
    const size_t chunk = remaining < (size_t)available ? remaining :
                         (size_t)available;
    const size_t written = Serial.write(usbQueue[usbQueueHead] +
                                        usbQueueOffset, chunk);
    if (written == 0U) return;
    usbQueueOffset += written;
    if (usbQueueOffset == packetLength) {
      usbQueueOffset = 0U;
      usbQueueHead = (usbQueueHead + 1U) % USB_QUEUE_DEPTH;
      --usbQueueCount;
      ++usbPacketsSent;
    }
  }
}
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
void loop() {
  handleUsbCommands();
  /* Module acquisition must not depend on the USB CDC ready flag. Some host
   * drivers expose the port before Teensy::Serial evaluates as connected. */
  pollModules();
  drainUsbQueue();
}

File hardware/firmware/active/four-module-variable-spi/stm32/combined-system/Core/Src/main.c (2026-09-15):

#include "main.h"
#include "combined_acquisition.h"

SPI_HandleTypeDef hspi1;
SPI_HandleTypeDef hspi3;
DMA_HandleTypeDef hdma_spi3_rx;
DMA_HandleTypeDef hdma_spi3_tx;

void SystemClock_Config(void);
static void MX_GPIO_Init(void);
static void MX_SPI1_Init(void);
static void MX_SPI3_Init(void);
static void MX_DMA_Init(void);

int main(void)
{
  HAL_Init();
  SystemClock_Config();
  MX_GPIO_Init();
  MX_DMA_Init();
  MX_SPI1_Init();
  MX_SPI3_Init();
  CombinedAcquisition_Init();

  while (1)
  {
    CombinedAcquisition_RunOnce();
  }
}

void SystemClock_Config(void)
{
  RCC_OscInitTypeDef osc = {0};
  RCC_ClkInitTypeDef clock = {0};

#ifdef SCLK33_SYSCLK_HIGH
  HAL_PWREx_ControlVoltageScaling(PWR_REGULATOR_VOLTAGE_SCALE1_BOOST);
#else
  HAL_PWREx_ControlVoltageScaling(PWR_REGULATOR_VOLTAGE_SCALE1);
#endif

  osc.OscillatorType = RCC_OSCILLATORTYPE_HSI;
  osc.HSIState = RCC_HSI_ON;
  osc.HSICalibrationValue = RCC_HSICALIBRATION_DEFAULT;
  osc.PLL.PLLState = RCC_PLL_ON;
  osc.PLL.PLLSource = RCC_PLLSOURCE_HSI;
  osc.PLL.PLLM = RCC_PLLM_DIV4;
#ifdef SCLK33_SYSCLK_HIGH
  osc.PLL.PLLN = SCLK33_PLLN;
#else
  osc.PLL.PLLN = 40U;
#endif
  osc.PLL.PLLP = RCC_PLLP_DIV2;
  osc.PLL.PLLQ = RCC_PLLQ_DIV2;
  osc.PLL.PLLR = RCC_PLLR_DIV2;
  if (HAL_RCC_OscConfig(&osc) != HAL_OK) { Error_Handler(); }

  clock.ClockType = RCC_CLOCKTYPE_HCLK | RCC_CLOCKTYPE_SYSCLK |
                    RCC_CLOCKTYPE_PCLK1 | RCC_CLOCKTYPE_PCLK2;
  clock.SYSCLKSource = RCC_SYSCLKSOURCE_PLLCLK;
  clock.AHBCLKDivider = RCC_SYSCLK_DIV1;
  clock.APB1CLKDivider = RCC_HCLK_DIV1;
  clock.APB2CLKDivider = RCC_HCLK_DIV1;
#ifdef SCLK33_SYSCLK_HIGH
  if (HAL_RCC_ClockConfig(&clock, FLASH_LATENCY_4) != HAL_OK)
#else
  if (HAL_RCC_ClockConfig(&clock, FLASH_LATENCY_2) != HAL_OK)
#endif
  {
    Error_Handler();
  }
}

static void MX_SPI1_Init(void)
{
  hspi1.Instance = SPI1;
  hspi1.Init.Mode = SPI_MODE_MASTER;
  hspi1.Init.Direction = SPI_DIRECTION_2LINES;
  hspi1.Init.DataSize = SPI_DATASIZE_8BIT;
  hspi1.Init.CLKPolarity = SPI_POLARITY_LOW;
  hspi1.Init.CLKPhase = SPI_PHASE_1EDGE;
  hspi1.Init.NSS = SPI_NSS_SOFT;
#ifdef SCLK33_SPI_BAUDRATE_PRESCALER
  hspi1.Init.BaudRatePrescaler = SCLK33_SPI_BAUDRATE_PRESCALER;
#else
  hspi1.Init.BaudRatePrescaler = SPI_BAUDRATEPRESCALER_8;
#endif
  hspi1.Init.FirstBit = SPI_FIRSTBIT_MSB;
  hspi1.Init.TIMode = SPI_TIMODE_DISABLE;
  hspi1.Init.CRCCalculation = SPI_CRCCALCULATION_DISABLE;
  hspi1.Init.CRCPolynomial = 7U;
  hspi1.Init.CRCLength = SPI_CRC_LENGTH_DATASIZE;
  hspi1.Init.NSSPMode = SPI_NSS_PULSE_ENABLE;
  if (HAL_SPI_Init(&hspi1) != HAL_OK) { Error_Handler(); }
}

static void MX_SPI3_Init(void)
{
  hspi3.Instance = SPI3;
  hspi3.Init.Mode = SPI_MODE_SLAVE;
  hspi3.Init.Direction = SPI_DIRECTION_2LINES;
  hspi3.Init.DataSize = SPI_DATASIZE_8BIT;
  hspi3.Init.CLKPolarity = SPI_POLARITY_LOW;
  hspi3.Init.CLKPhase = SPI_PHASE_1EDGE;
  hspi3.Init.NSS = SPI_NSS_HARD_INPUT;
  hspi3.Init.FirstBit = SPI_FIRSTBIT_MSB;
  hspi3.Init.TIMode = SPI_TIMODE_DISABLE;
  hspi3.Init.CRCCalculation = SPI_CRCCALCULATION_DISABLE;
  hspi3.Init.CRCPolynomial = 7U;
  hspi3.Init.CRCLength = SPI_CRC_LENGTH_DATASIZE;
  hspi3.Init.NSSPMode = SPI_NSS_PULSE_DISABLE;
  if (HAL_SPI_Init(&hspi3) != HAL_OK) { Error_Handler(); }
}

void Combined_ReinitializeHostSPI(void)
{
  (void)HAL_SPI_DeInit(&hspi3);
  __HAL_RCC_SPI3_FORCE_RESET();
  __DSB();
  __HAL_RCC_SPI3_RELEASE_RESET();
  __DSB();
  MX_SPI3_Init();
}

static void MX_DMA_Init(void)
{
  __HAL_RCC_DMAMUX1_CLK_ENABLE();
  __HAL_RCC_DMA1_CLK_ENABLE();
  HAL_NVIC_SetPriority(DMA1_Channel1_IRQn, 1, 0);
  HAL_NVIC_EnableIRQ(DMA1_Channel1_IRQn);
  HAL_NVIC_SetPriority(DMA1_Channel2_IRQn, 1, 1);
  HAL_NVIC_EnableIRQ(DMA1_Channel2_IRQn);
}

static void MX_GPIO_Init(void)
{
  GPIO_InitTypeDef gpio = {0};
  __HAL_RCC_GPIOA_CLK_ENABLE();
  __HAL_RCC_GPIOB_CLK_ENABLE();

  HAL_GPIO_WritePin(GPIOA, MUX_S0_Pin | MUX_S1_Pin | MUX_S2_Pin |
                           MUX_S3_Pin | MUX_EN1_Pin, GPIO_PIN_RESET);
  HAL_GPIO_WritePin(GPIOB, ADC_CS1_Pin | ADC_CS2_Pin | MUX_EN2_Pin,
                    GPIO_PIN_SET);
  HAL_GPIO_WritePin(GPIOB, HOST_IRQ_Pin, GPIO_PIN_RESET);

  gpio.Pin = MUX_S0_Pin | MUX_S1_Pin | MUX_S2_Pin | MUX_S3_Pin | MUX_EN1_Pin;
  gpio.Mode = GPIO_MODE_OUTPUT_PP;
  gpio.Pull = GPIO_NOPULL;
  gpio.Speed = GPIO_SPEED_FREQ_LOW;
  HAL_GPIO_Init(GPIOA, &gpio);

  gpio.Pin = ADC_CS1_Pin | ADC_CS2_Pin | MUX_EN2_Pin | HOST_IRQ_Pin;
  HAL_GPIO_Init(GPIOB, &gpio);

  gpio.Pin = ADC_EOC1_Pin | ADC_EOC2_Pin | HOST_SYNC_Pin;
  gpio.Mode = GPIO_MODE_INPUT;
  HAL_GPIO_Init(GPIOB, &gpio);
}

void Error_Handler(void)
{
  __disable_irq();
  while (1) { }
}

#ifdef USE_FULL_ASSERT
void assert_failed(uint8_t *file, uint32_t line)
{
  (void)file;
  (void)line;
}
#endif

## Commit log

2026-09-15 Add calibration scalability evidence
    [dispersion_metrics.csv, load_comparison.csv, matched_comparison_cells.csv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]
2026-09-15 Add data scalability analysis
    [02_bandwidth_intersections_200Hz.csv, 02_usb_theoretical_3d.csv, 02b_usb_theoretical_200hz.csv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]
2026-09-15 Add data scalability raw evidence
    [all_pass_group_statistics.csv, all_runs_diagnostic_statistics.csv, analysis_selected.csv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]
2026-09-15 Add data scalability history
    [packet_log.csv, path_map.csv]
2026-09-15 Add active hardware evidence
    [ACC-B_Mask - ENIG.gbr, ACC-B_Paste.gbr, ACC-B_Silkscreen.gbr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]
2026-09-15 Add archived hardware records
    [20260830_215646_usb_mul1_dump.txt, 20260830_220057_usb_mul1_dump.txt, 20260830_221452_usb_mul1_dump.txt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]
2026-09-15 Add report supplementary assets
    [capacity_crossings.csv, current_power_scaling_summary.csv, fsr1_accuracy_per_capture.csv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]
2026-09-15 Add power scalability evidence
    [accepted_configuration_voltage.csv, additivity_checks.csv, anomaly_summary.csv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]
2026-09-15 Document individual hardware boards
2026-09-15 Reuse existing flowchart asset
2026-09-15 Match inset frame colour
